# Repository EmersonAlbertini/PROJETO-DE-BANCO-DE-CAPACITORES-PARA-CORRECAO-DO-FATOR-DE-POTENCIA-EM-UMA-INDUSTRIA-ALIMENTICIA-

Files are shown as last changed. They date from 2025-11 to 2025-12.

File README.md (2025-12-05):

# ⚡ Projeto de Banco de Capacitores para Correção do Fator de Potência  

Este repositório apresenta o desenvolvimento de um projeto de banco de capacitores montado em painel elétrico para correção do fator de potência de uma indústria alimentícia.  
O trabalho foi elaborado como Trabalho de Conclusão de Curso (TCC) do curso de Engenharia Elétrica no Centro Universitário Hermínio Ometto (FHO).  
O projeto tem como base dados reais de uma instalação industrial no interior de Santa Catarina e foi desenvolvido em conformidade com as normas ABNT NBR 5410, NBR IEC 61439-1/2, NBR 5419, NR 10, NR 12, entre outras.

---

## 📌 Objetivos Gerais do Projeto  

- Projetar um banco de capacitores automático em painel elétrico para corrigir o fator de potência da instalação;  
- Elevar o fator de potência de 0,87 para 0,95, evitando penalidades tarifárias e melhorando a eficiência energética;  
- Reduzir o carregamento do transformador e proporcionar maior confiabilidade e segurança operacional;  
- Garantir que o projeto esteja em conformidade com as normas técnicas e boas práticas de engenharia.

---

## 🔍 Conteúdo Técnico  

O projeto aborda todas as etapas de dimensionamento, simulação e especificação dos componentes do sistema de compensação reativa, incluindo:

### ⚙️ Cálculo de Compensação Reativa  
- Levantamento da potência reativa da instalação;  
- Cálculo da potência a ser compensada para corrigir o fator de potência;  
- Definição da quantidade e configuração dos estágios.

### 🔄 Simulações e Análises  
- Simulações realizadas via software para validação dos resultados obtidos;  
- Verificação da redução de corrente e melhoria na eficiência do sistema após a compensação reativa;  
- Análise das correntes de curto-circuito trifásico e fase-terra em todos os barramentos da instalação.

### 🔌 Dimensionamento e Seleção de Componentes  
- Seleção dos capacitores trifásicos conforme a tensão nominal da instalação;  
- Utilização de reatores de dessintonia para mitigação de harmônicas e proteção dos capacitores;  
- Definição de contatores específicos para manobra de capacitores, conforme a categoria adequada de utilização;  
- Dimensionamento dos disjuntores de proteção de cada estágio e do disjuntor geral do painel;  
- Especificação do controlador de fator de potência com operação automática e comunicação industrial integrada.

### 🧮 Dimensionamento dos Condutores  
- Definição da seção dos condutores de fase conforme critérios de ampacidade, queda de tensão e curto-circuito;  
- Dimensionamento do condutor de proteção em conformidade com a NBR 5410.

### 🧱 Projeto do Painel Elétrico  
- Projeto desenvolvido em conformidade com as normas NR 10, NR 12, NBR 5410 e NBR IEC 61439-1/2;  
- Sistema de climatização dimensionado com o software RiTherm (Rittal);  
- Sistema de monitoramento térmico da Varixx, com sinalizações locais para supervisão do funcionamento;  
- Diagrama trifilar e layout 3D elaborados no EPLAN Electric P8 + Pro Panel.

---

## 🧰 Ferramentas Utilizadas  

- **EPLAN Electric P8 / Pro Panel** (diagrama e modelagem 3D);  
- **RiTherm** (dimensionamento térmico);  
- **AutoCAD** (diagrama unifilar);  
- **PSP-UFU** (simulações elétricas);  
- **Excel** (lista de cargas e cálculos técnicos).

---

## 🏫 Instituição  

**Centro Universitário Hermínio Ometto – Araras/SP**  
**Curso:** Engenharia Elétrica  
**Período de entrega:** Junho de 2025  

---

## ⚠️ Restrições de Uso  

Este projeto destina-se unicamente para fins didáticos e não deve ser utilizado em aplicações reais sem validação técnica profissional.  
Qualquer uso comercial, seja direto ou indireto, é estritamente proibido sem autorização expressa do autor.  
Para outras finalidades ou solicitações de uso que não se enquadrem nessas condições, por favor, entre em contato com o autor.

---

## ✉️ Contato  

**Autor:** Emerson Falcão Albertini  
**Email:** [emersonalbertini01@gmail.com](mailto:emersonalbertini01@gmail.com)  
**Linkedin:** [www.linkedin.com/in/emerson-falcao-albertini-8aa17a334](https://www.linkedin.com/in/emerson-falcao-albertini-8aa17a334)  

**Orientador:** Prof. Dr. Daniel Augusto Pagi Ferreira  
**Email:** [danielferreira@fho.edu.br](mailto:danielferreira@fho.edu.br)

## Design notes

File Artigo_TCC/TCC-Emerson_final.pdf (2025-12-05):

PROJETO DE BANCO DE CAPACITORES PARA CORREÇÃO DO FATOR DE POTÊNCIA EM UMA INDÚSTRIA ALIMENTÍCIA

Aluno: Emerson Falcão Albertini (FHO) emerson01@alunos.fho.edu.br Orientador: Prof. Dr. Daniel Augusto Pagi Ferreira (FHO) danielferreira@fho.edu.br

Resumo

Este trabalho tem como objetivo desenvolver um projeto de banco de capacitores montado em painel elétrico para corrigir o fator de potência de uma indústria alimentícia. A instalação analisada apresenta elevado consumo de energia reativa indutiva, devido à predominância de inversores de frequência para a partida dos motores, o que compromete o desempenho elétrico e pode gerar penalidades caso não haja a devida compensação. Com base em dados reais de uma instalação industrial, foi realizado o dimensionamento técnico do banco de capacitores, totalizando 225 kVAr distribuídos em 9 estágios, com o objetivo de elevar o fator de potência de 0,87 para 0,95. O projeto contempla os cálculos da compensação, simulações para validação dos resultados e o dimensionamento completo de todos os componentes do sistema, de acordo com as normas técnicas vigentes. Também foram desenvolvidos o diagrama trifilar e layout mecânico do painel. Com isso, o trabalho proposto oferece uma solução técnica eficaz para melhorar a qualidade da energia e evitar despesas com penalidades tarifárias.

Palavras-Chaves: banco de capacitores, fator de potência, qualidade de energia.

### 1. Introdução

Com o crescimento do setor industrial e a crescente demanda por energia elétrica, tem-se intensificado a busca por maior eficiência no uso dos recursos energéticos. A qualidade da energia tornou-se um fator essencial para a competitividade entre empresas, especialmente diante da necessidade de reduzir custos e minimizar impactos ambientais.

Segundo o Ministério de Minas e Energia (MME, 2024), a eficiência energética é considerada uma prioridade nacional, visando à redução dos custos com energia e o aumento da competitividade da economia brasileira. Nesse contexto, práticas como a correção do fator de potência ganham destaque pois, além de melhorar o desempenho dos sistemas elétricos, reduzem perdas técnicas e evitam penalidades tarifárias impostas pelas concessionárias (CREDER, 2016).

A correção do fator de potência é um aspecto crucial na gestão inteligente de energia por medir a eficiência com que a energia elétrica é convertida em trabalho útil, impactando diretamente os custos operacionais e a qualidade do fornecimento de energia.

De acordo com a legislação vigente, estabelecida pela Resolução 1000 de 7/12/2021 (ANEEL, 2021), o fator de potência deve ser mantido dentro dos limites de 0,92 indutivo e 0,92 capacitivo. Caso os limites não sejam respeitados, o excesso de energia reativa, tanto indutiva quanto capacitiva, deve ser medido e faturado. Desse modo, a correção desse fator acaba sendo praticamente obrigatória em industrias de médio a grande porte (FILHO, 2007).

Segundo CREDER (2016), a instalação de bancos de capacitores em paralelo com a rede elétrica é o método mais difundido para corrigir o fator de potência, devido ao seu baixo custo de implementação e manutenção. De modo geral, a principal função de um banco de capacitores é fornecer a quantidade necessária de energia reativa capacitiva, de forma que a relação entre a potência ativa e a potência reativa fique equilibrada, aproximando o fator de potência ao mais próximo possível de ser unitário.

### 1.1. Justificativa

O principal motivo para optar-se por essa solução é melhorar a eficiência energética da instalação. Quando o fator de potência está baixo, uma parcela significativa da energia elétrica é desperdiçada na forma de energia reativa, utilizada apenas para manter os campos eletromagnéticos de equipamentos como motores e transformadores. Com os bancos de capacitores, essa energia passa a ser fornecida localmente, o que reduz a demanda de energia reativa fornecida pela concessionária, diminuindo a circulação de corrente e perdas associadas.

Do ponto de vista técnico, os capacitores fornecem potência reativa capacitiva para compensar a potência reativa indutiva exigida pelas cargas, corrigindo o fator de potência e reduzindo o deslocamento de fase entre corrente e tensão. Como consequência, há uma diminuição das perdas por efeito Joule, do aquecimento de cabos e equipamentos e da sobrecarga em transformadores, contribuindo para um uso eficiente da infraestrutura elétrica.

Outro benefício relevante é a liberação da capacidade do sistema elétrico. A redução da corrente circulante nos condutores e equipamentos, evita sobrecargas e permite melhorar o aproveitamento da infraestrutura existente (SILVA, 2009). Essa condição possibilita futuras ampliações, além de contribuir para o prolongamento da vida útil dos equipamentos.

Além dos ganhos técnicos, a correção do fator de potência proporciona redução de custos operacionais, uma vez que as concessionárias de energia penalizam os consumidores que apresentam fator de potência baixo, cobrando taxas adicionais pela energia reativa excedente. A instalação de bancos de capacitores permite evitar essas penalidades, gerando economia nas faturas de energia elétrica (MARCHI, 2019).

Por fim, essa solução contribui para a sustentabilidade, uma vez que otimiza o uso dos recursos energéticos e evita desperdícios. Assim, a instalação de bancos de capacitores se mostra como medida eficaz e vantajosa para industrias de médio e grande porte que desejam melhorar seu desempenho energético, reduzir custos e atender às exigências regulatórias.

### 2. Considerações gerais e objetivos

Este trabalho consiste na elaboração de um projeto de um banco de capacitores automático, montado em painel, com o objetivo de corrigir o fator de potência de uma instalação industrial.

Especificamente, o estudo busca:

- Diagnosticar o fator de potência atual da instalação;
- Calcular a potência reativa capacitiva necessária para elevar o fator de potência a 0,95;
- Projetar e especificar os componentes do banco de capacitores (capacitores, contatores, disjuntores, reatores de dessintonia e controlador de fator de potência);
- Realizar os cálculos de curto-circuito e dimensionar os condutores conforme as normas técnicas vigentes;
- Validar o projeto por meio de simulações computacionais;
- Elaborar o diagrama trifilar e layout mecânico do painel;
- Avaliar os ganhos obtidos na redução da corrente e do carregamento do transformador.

A proposta foi desenvolvida a partir de dados reais obtidos em uma empresa do setor alimentício localizada no interior de Santa Catarina.

Nota: Todos os materiais técnicos desenvolvidos e utilizados neste trabalho encontram-se disponíveis no repositório oficial do GitHub:

https://github.com/EmersonAlbertini/PROJETO-DE-BANCO-DE-CAPACITORES-PARA-CORRECAO-DO-FATOR-DE-POTENCIA-EM-UMA-INDUSTRIA-ALIMENTICIA-

### 3. Descrição do projeto

A alimentação da indústria tem início em uma subestação abrigada, onde a tensão de 13,8 kV proveniente da concessionária é rebaixada para 380 V por meio de um transformador trifásico de 1000 kVA. Abaixo do transformador encontra-se o Quadro Geral de Baixa Tensão (QGBT), responsável pela distribuição de energia para seis Centros de Controle de Motores (CCM’s). Esses CCM’s alimentam diversas cargas industriais, com predominância de motores acionados por inversores de frequência, condição que intensifica o consumo de energia reativa indutiva e contribui para a redução do fator de potência da instalação.

A Figura 1 mostra o diagrama unifilar do painel elétrico QGBT, responsável por alimentar os seis CCM’s da instalação, ele servirá como ponto de referência para as próximas etapas do desenvolvimento do projeto.

Figura 1 – Diagrama unifilar painel elétrico QGBT

TRAFO-001
1000 kVA
13,8 kV/ 380 V
3Ø / 60Hz

Q01
In=1600A
Ir=1600A
3P

Q02
In=40A
3P
NOTA 9

DPS
CLASSE l+II
220V (F-PE)
Imax = 25 kA
3P+N

Q03
In=16A
3P | 1600/5A

400VA

380/115V P¹ P²

MULTIMEDIDOR
DE GRANDEZAS

ETHERNET/IP
NOTA 10

380V - 3F+N+PE - 1600A - 24kA

Q05
In=800A

3P
NOTA 7

# CCM-002⁽³Ø⁺N⁺PE⁾ ISOL. 0,6/1kV NOTA ⁸ 2x⁽4x240mm²)+1x⁽1x240mm²)

Ir=720A

Q04
In=200A

3P
NOTA 7

# CCM-001⁽³Ø⁺N⁺PE⁾ ISOL. 0,6/1kV NOTA ⁸ 1x⁽4x70mm²)+1x⁽1x50mm²)

Ir=180A

Q06
In=63A

3P
NOTA 7

# CCM-003⁽³Ø⁺N⁺PE⁾ ISOL. 0,6/1kV NOTA ⁸ 1x⁽4x16mm²)+1x⁽1x16mm²)

Ir=54A

Q07
In=250A

3P
NOTA 7

# CCM-004⁽³Ø⁺N⁺PE⁾ ISOL. 0,6/1kV NOTA ⁸ 1x⁽4x95mm²)+1x⁽1x70mm²)

Ir=225A

Q08
In=125A

3P
NOTA 7

# CCM-005⁽³Ø⁺N⁺PE⁾ ISOL. 0,6/1kV NOTA ⁸ 1x⁽4x25mm²)+1x⁽1x25mm²)

Ir=108A

Q09
In=320A

3P
NOTA 7

# CCM-006⁽³Ø⁺N⁺PE⁾ ISOL. 0,6/1kV NOTA ⁸ 1x⁽4x120mm²)+1x⁽1x95mm²)

Ir=260A CABO DE COBRE ³⁵mm² PARA EQUIPOTENCIALIZAÇÃO

PE

QGBT-001 - NOTA 3 E 4

NOTA 5

132.94 kVA
115.75 kW

### 64.97 kVAr

### 34.09 kVA 28.13 kW 18.89 kVAr

468.19 kVA
406.24 kW
232.25 kVAr

### 67.84 kVA 59.87 kW 31.59 kVAr

170.45 kVA
142.29 kW

### 91.34 kVAr

11

VAI PARA | VAI PARA | VAI PARA | VAI PARA | VAI PARA | VAI PARA
PÁG. 02 | PÁG. 02 | PÁG. 03 | PÁG. 04 | PÁG. 04 | PÁG. 05

115.23 kVA
100.54 kW

### 55.55 kVAr

Q14
In=????

3P

# NOTA 7 (3Ø⁺N⁺PE⁾ ISOL. 0,6/1kV NOTA ⁸ _x⁽_x__mm²)+_x⁽_x__mm²)

Ir=????

BANCO DE
CAPACITOR-001

225 kVAr

1

Q10 | Q11 In=320A
| 3P NOTA 7

Ir=294A

Q12
In=250A

3P
NOTA 7

Ir=250A

Q13
In=250A

3P
NOTA 7

Ir=250A

NOTA 1

In=250A

3P
NOTA 7

Ir=250A

RESERVA À DEFINIR ⁽³Ø⁺N⁺PE⁾ ISOL. 0,6/1kV 4x⁽4x185mm²)+4x⁽1x95mm²) | À DEFINIR | À DEFINIR | À DEFINIR
RESERVA | RESERVA | RESERVA

Fonte: Próprio Autor
No presente momento, a instalação apresenta um fator de potência global de 0,87, inferior ao mínimo exigido pela concessionária, o que já resulta em penalidades significativas devido ao excedente de reativos na rede. Com o objetivo de reverter esse cenário, será projetado um banco de capacitores automático, alimentado diretamente pelo QGBT, com a função de compensar a energia reativa consumida pelas cargas indutivas do sistema elétrico.

Além da correção do fator de potência, o banco de capacitores também contribuirá para reduzir o carregamento do transformador, que atualmente opera com 98,87% da sua capacidade nominal, valor muito próximo de seu limite máximo. Essa condição compromete a confiabilidade, pois torna a instalação suscetível a sobrecargas. Com a redução do carregamento, o sistema passa a operar com maior segurança e possibilita futuras ampliações, sem a necessidade imediata de substituição do transformador ou da infraestrutura existente.

Para fundamentar o dimensionamento do banco de capacitores e as análises subsequentes, foram utilizados dois documentos técnicos elaborados para este projeto: a lista de cargas (PBC-LC-25E-0001), que detalha todas as cargas da instalação, e o diagrama unifilar (PBC-UN-25E-0001), que representa graficamente a distribuição elétrica desde a subestação até as cargas terminais de cada CCM.

A Tabela 1, apresentada a seguir, mostra o resumo de cargas da instalação, ela servirá como base para os cálculos e dimensionamentos das etapas subsequentes.

Tabela 1 – Resumo de cargas

Painel

Potência
ativa
demandada
(kW)

Potência
reativa
demandada
(kVAr)

Potência
aparente
demandada
(kVA)

Fator
de
potência

Carregamento
do
transformador
CCM-001 | 100.54 | 55.55 | 115.23 | 0.87 | 11.52%
CCM-002 | 406.24 | 232.25 | 468.19 | 0.87 | 46.82%
CCM-003 | 28.13 | 18.89 | 34.09 | 0.82 | 3.41%
CCM-004 | 115.75 | 64.97 | 132.94 | 0.87 | 13.29%
CCM-005 | 59.87 | 31.59 | 67.84 | 0.88 | 6.78%
CCM-006 | 142.29 | 91.34 | 170.45 | 0.83 | 17.04%
Total | 852.82 | 494.59 | 985.86 | 0.87 | 98.87%

Fonte: Próprio Autor

### 3.1. Cálculo da potência reativa capacitiva a ser compensada

Para que o sistema elétrico da instalação atenda aos requisitos da concessionária de energia, é necessário corrigir o fator de potência. Considerando o QGBT como ponto de referência, atualmente o fator de potência global do sistema está em 0,87.

Embora o valor mínimo exigido seja 0,92, foi adotada a correção para 0,95 indutivo. Essa decisão se justifica pelo fato de que, na prática, manter o fator de potência muito próximo do mínimo permitido não é recomendável pois pequenas variações na carga, como a adição de novos equipamentos ou alterações no perfil de consumo, podem facilmente levar o sistema a ultrapassar o limite de 0,92, o que pode ocasionar sobrecargas caso o sistema não esteja dimensionado para este cenário e/ou penalidades caso a correção não seja feita.

Sendo assim, corrigir o fator de potência para 0,95 é uma boa prática de projeto, pois assegura uma margem de segurança maior que 0,92.

A Figura 2 mostra o triângulo de potências, que representa as relações entre a potência ativa (P), potência reativa (Q), potência aparente (S) e os ângulos correspondentes ao fator de potência (θ₁ e θ₂). Esse triângulo permite compreender geometricamente como essas grandezas se relacionam e, a partir dele, é possível calcular a potência reativa a ser compensada (Qc).

Figura 2 – Triângulo de potências

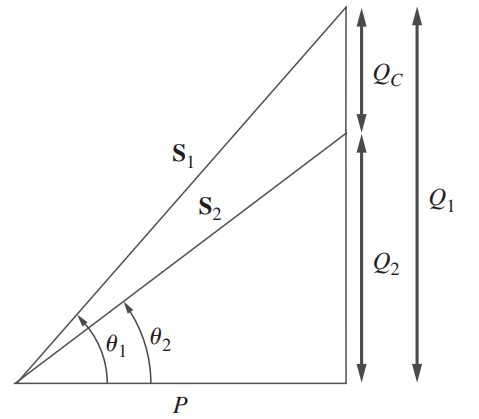
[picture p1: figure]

Fonte: ALEXANDER; SADIKU (2013).
Inicialmente, com base na lista de cargas, verificou-se que a potência ativa total demandada pela instalação é de aproximadamente 852,82 kW, enquanto a potência reativa é cerca de 494,59 kVAr. Com base nesses valores, é possível calcular a potência aparente atual da instalação utilizando a relação trigonométrica descrita na Equação (1):

S₁ = P + Q
= 852,82 + 494,59 ≅ 985,86 kVA | (1)

Para alcançar o fator de potência desejado, é necessário recalcular a potência aparente da instalação, mas agora considerando o fator de potência como 0,95. Deste modo, pela Equação (2):

S₂ =

P

FP

=

852,82
0,95 ≅ 897,71 kVA | (2)

Com a potência aparente obtida, podemos calcular a potência reativa nessa condição por meio da Equação (3):

Q = S
− P = 897,71 − 852,82 ≅ 280,32 kVAr | (3)

A diferença entre a potência reativa atual da instalação e a potência reativa desejada indica o valor da potência que deverá ser compensada pelo banco de capacitores, conforme a Equação (4):

Q = Q − Q = 494,59 − 280,32 = 214,27 kVAr | (4)

Portanto, para corrigir o fator de potência para 0,95, será necessário injetar na rede elétrica aproximadamente 214,27 kVAr de potência reativa capacitiva. Para isso, nos próximos itens, será projetado um banco de capacitores automático composto por 9 estágios de 25 kVAr, totalizando 225 kVAr, o que garantirá a compensação necessária.

Com a inserção do banco de capacitores, a potência reativa demandada da rede elétrica será reduzida, passando de 494,59 kVAr para 269,59 kVAr, resultado da subtração direta da potência reativa fornecida pelo banco (225 kVAr). Nessa nova condição, é possível recalcular a potência aparente demandada da instalação, conforme a Equação (5):

S = P + Q = 852,82 + 269,59 ≅ 894,42 kVA | (5)

Com essa redução, o transformador que anteriormente operava em um nível crítico de 98,87% de carregamento, passará a operar com aproximadamente 89,44%. Isso equivale a uma liberação de aproximadamente 95,3 kVA, ou 9,53% da capacidade nominal. Essa compensação melhorará significativamente a segurança do sistema e possibilitará adição de novas cargas, sem a necessidade imediata de substituir o transformador ou expandir a infraestrutura elétrica existente.

### 3.2. Simulação

A simulação é uma etapa fundamental para validar os resultados obtidos nos cálculos e garantir maior confiabilidade ao projeto. Para este trabalho foi utilizado o software PSP-UFU, que permitiu observar a corrente no secundário do transformador.

A Figura 3 apresenta a condição atual do sistema antes da inserção do banco de capacitores, em que a corrente elétrica no circuito do transformador até o painel do QGBT é de aproximadamente 1572 A.

Figura 3 – Sistema antes a inserção dos capacitores

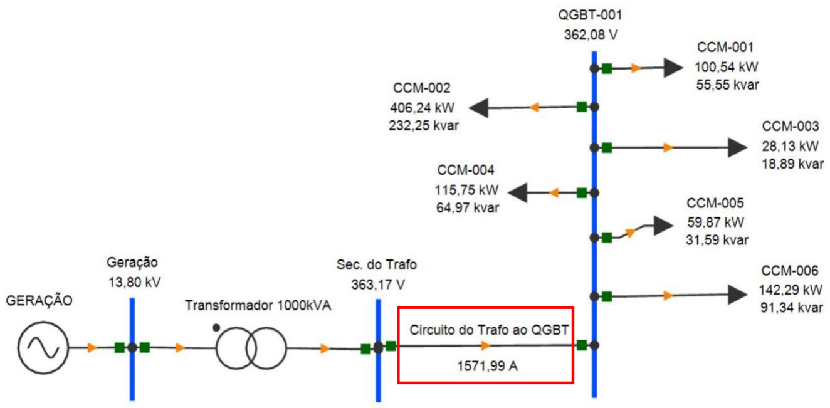
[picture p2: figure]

Fonte: Próprio Autor

A Figura 4 mostra o sistema após a instalação do banco de capacitores, verifica-se que a corrente foi reduzida para cerca de 1414 A.

Figura 4 – Sistema depois a inserção dos capacitores

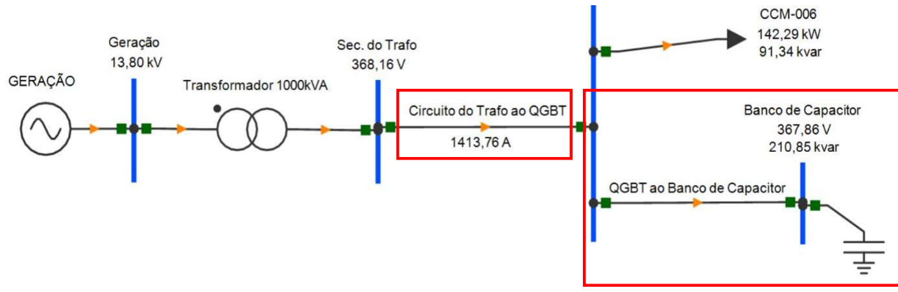
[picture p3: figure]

Fonte: Próprio Autor

Essa redução comprova de forma prática, a efetividade da solução proposta, uma vez que a corrente no secundário do transformador foi reduzida de aproximadamente 1572 A para 1414 A, correspondendo a uma liberação de cerca de 158 A.

### 3.3. Cálculo de curto-circuito

O curto-circuito é uma condição anormal em um sistema elétrico, caracterizado pela conexão acidental de fases entre si ou de fases com o neutro, gerando correntes muito superiores às nominais dos equipamentos.

O cálculo de curto-circuito é essencial para dimensionar corretamente os componentes elétricos, como condutores, disjuntores e barramentos, assegurando que suportem as correntes sem comprometer a segurança e a integridade do sistema.

Além disso, esse cálculo permite definir os ajustes de proteção, garantindo a atuação adequada em casos de falha e, consequentemente, reduzindo os riscos de danos aos equipamentos e à operação.

Para esta instalação, os cálculos de curto-circuito foram realizados em todos os barramentos significativos do sistema, sendo esses: o fornecimento de energia (média tensão), o secundário do transformador (lado de baixa tensão), o painel elétrico QGBT e o painel elétrico do banco de capacitores.

Foram determinados os valores de Ics (corrente de curto-circuito trifásico), Icft (corrente de curto-circuito fase-terra), Ica (corrente assimétrica de curto-circuito) e Icim (impulso da corrente de curto-circuito). A Tabela 2 apresenta os resultados obtidos em cada barramento.

Tabela 2 – Tabela de resultados dos cálculos de curto-circuito

Local | Ics (kA) | Icft (kA) | Fator de
| | | assimetria | Ica (kA) | Icim (kA)

Fornecimento de
energia (lado MT) | 13.91 | 10.44 | 1.62 | 22.53 | 31.87

Transformador
(lado BT) | 24.13 | 23.76 | 1.39 | 33.57 | 47.48

Painel elétrico
QGBT | 23.27 | 23.20 | 1.37 | 31.77 | 44.93

Banco de
capacitores | 20.28 | 9.97 | 1.28 | 26.02 | 36.79
| | Fonte: Próprio Autor

Além dos cálculos, os valores de curto-circuito também podem ser verificados por meio da simulação realizada no tópico anterior. A Figura 5 mostra o valor da corrente de curto-circuito trifásico no barramento do banco de capacitores, confirmando os resultados obtidos nos cálculos.

Figura 5 – Valor de Ics no banco de capacitores

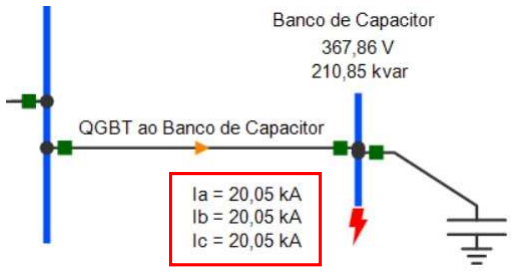
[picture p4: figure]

Fonte: Próprio Autor

### 3.4. Seleção dos capacitores

Para corrigir o fator de potência da instalação, conforme demonstrado nos cálculos anteriores, será necessário inserir capacitores em paralelo com o sistema. Para isso, foram especificadas células trifásicas modelo B32344-E4282-Z040 do fabricante Siemens, vide Figura 6.

O modelo escolhido possui características essenciais para o projeto, como por exemplo, vida útil superior a 100.000 horas, possibilidade de instalação na posição vertical e construção em filme de polipropileno metalizado autorregenerativo, que assegura maior durabilidade do equipamento. Além disso, o modelo possui um sistema interno de proteção contra sobrepressão, que garante a desconexão segura do capacitor em caso de falha.

Figura 6 – Célula capacitiva trifásica

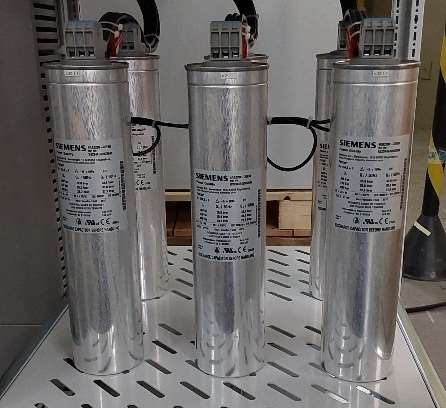
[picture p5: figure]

Fonte: Próprio autor

Cada célula possui potência nominal de 33,7 kVAr quando ligada em 440 V. No entanto, devido a tensão no secundário do transformador ser 380 V, foi necessário recalcular a potência reativa efetiva fornecida por cada unidade, considerando a variação da tensão. Como a potência de um capacitor é proporcional ao quadrado da tensão, aplica-se a relação mostrada na Equação (6):

Q = Q ×

V
V

= 33,7 ×

380
440
≅ 25,1 kVAr | (6)

Assim, cada célula capacitiva fornece cerca de 25 kVAr em 380 V. Para o projeto em questão, foi necessário instalar 9 células capacitivas, totalizando aproximadamente 225 kVAr, sendo superior à necessidade calculada de 214,27 kVAr.

### 3.5. Seleção dos reatores de dessintonia

Em instalações de médio e grande porte, é comum a presença de correntes harmônicas na rede elétrica, principalmente quando há grande quantidade de cargas não lineares, como inversores de frequência, fontes chaveadas, lâmpadas fluorescentes com reatores, entre outros.

De acordo com Wagner e Cruz (2023), as distorções harmônicas de alta frequência podem causar desgaste nos capacitores, pois estes se comportam como elementos de baixa impedância, devido à relação inversa entre impedância e frequência, o que aumenta as perdas ôhmicas, eleva a temperatura interna, reduz a vida útil dos componentes e, em casos extremos, pode causar explosões.

Para evitar esse tipo de problema, foram utilizados reatores de dessintonia (Figura 7) conectados em série com os capacitores. A principal função desse tipo de reator é deslocar a frequência de ressonância do conjunto capacitor-reator para um valor inferior às frequências harmônicas predominantes na rede, evitando assim, a amplificação das harmônicas. Além disso, os reatores atuam como elementos de proteção dos capacitores contra sobrecorrentes e sobretensões.

Figura 7 – Reator de dessintonia

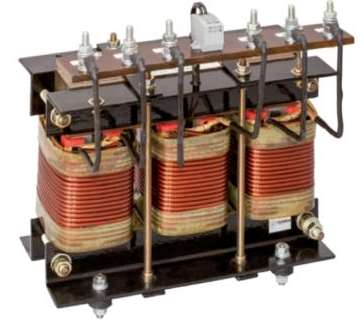
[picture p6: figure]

Fonte: WEG-capacitores-para-correção-do-fator-de-potencia

A escolha adequada dos reatores de dessintonia deve levar em consideração as correntes harmônicas presentes na rede elétrica. No entanto, na maioria dos casos não se tem um estudo detalhado para isso ou não é possível realizar medições no local. Por essa razão, é comum adotar modelos padronizados pelos fabricantes, desenvolvidos com base em critérios técnicos.

O dimensionamento desses reatores leva em consideração, principalmente, a potência do capacitor que será instalado em série com o indutor e o fator de dessintonia adotado, geralmente 7% ou 14%. O valor de 7% é mais utilizado em ambientes industriais, pois desloca a frequência de ressonância para aproximadamente 189 Hz, afastando-a da 5ª harmônica (300 Hz), uma das mais comuns geradas pelos inversores de frequência. Na maioria dos casos, o fator de 7% acaba sendo suficiente para suprir a necessidade da instalação, mas, dependendo das características da carga, pode ser necessário recorrer ao fator de 14%.

No presente projeto, considerando que cada estágio possui 25 kVAr e que a indústria analisada apresenta predominância de partidas de motores acionadas por inversores de frequência, foi adotado o uso de reatores de 25 kVAr, com fator de dessintonia de 7% para todos os estágios.

### 3.6. Seleção dos contatores para manobra dos estágios

Para fazer a comutação dos estágios do banco de capacitores foi necessário utilizar contatores específicos para essa finalidade. Diferentemente dos contatores convencionais, os contatores empregados na manobra de capacitores pertencem à categoria AC-6b, aplicação voltada especificamente para manobras de capacitores, conforme definido pela norma IEC 60947-4-1.

A principal diferença em relação aos modelos padrões, é a presença de resistores de pré-carga, que atuam nos primeiros instantes da energização, limitando a corrente de inrush, que pode atingir valores entre 30 e 50 vezes a corrente nominal do capacitor. Após o amortecimento inicial da corrente, os resistores são automaticamente curto-circuitados, permitindo a condução normal pela via principal dos contatos.

A atuação dos contatos de potência ocorre por um sinal enviado direto do controlador. Ao identificar a necessidade de correção, o controlador aciona a bobina dos contatores, inserindo ou retirando os estágios de forma automática, conforme a demanda da instalação.

Para o projeto, foram especificados contatores do modelo 3RT2628-1BB45 do fabricante Siemens (Figura 8). Este modelo possui bobina de comando em 24 Vcc e é adequado para a comutação de capacitores de 11 a 33 kVAr em redes de 380/400 V.

Figura 8 – Contator para manobra de capacitores

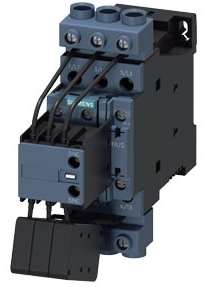
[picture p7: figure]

Fonte: SIEMENS (2025)

### 3.7. Dimensionamento dos disjuntores de proteção dos estágios

Cada estágio do banco de capacitores é composto por um conjunto de 25 kVAr em 380 V, o que resulta em uma corrente nominal dada pela Equação (7):

I =

Q
√3 × V

=

25000
√3 × 380
≈ 38 A | (7)

De acordo com as recomendações do fabricante, o disjuntor de proteção deve ser dimensionado com um fator multiplicador de 1,8 sobre a corrente nominal, a fim de suportar os picos de corrente associados ao chaveamento do capacitor (Fichas Técnicas, pág. 239). Sendo assim, a corrente corrigida dos disjuntores é obtida pela Equação (8):

I = 38 × 1,8 ≈ 68,4 A | (8)

Com base nesse valor, foi especificado o disjuntor 3VM1180-4EE32-0AA0 (Figura 9), do fabricante Siemens, para todos os estágios. Esse modelo possui corrente ajustável de 56 A a 80 A, curva de disparo térmico-magnética, proteção do tipo LI e capacidade de interrupção de curto-circuito de 36 kA.

Figura 9 – Disjuntor de proteção 3VM11

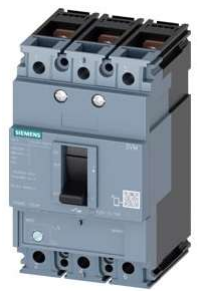
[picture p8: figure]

Fonte: SIEMENS (2025)

A escolha dos disjuntores também está em conformidade com a norma IEC 60947-2, que estabelece que a capacidade de interrupção (Icc) do disjuntor deve ser superior à corrente de curto-circuito presumida no ponto de instalação, garantindo a proteção eficaz do sistema e a integridade dos equipamentos em caso de falha.

### 3.8. Cálculo do disjuntor geral

Para dimensionar o disjuntor geral do painel foi necessário somar a corrente corrigida dos nove estágios do banco. Aplicando-se o mesmo critério de dimensionamento descrito anteriormente, a corrente total corrigida é obtida pela Equação (9):

I = 68,4 × 9 ≈ 616 A | (9)

Dessa forma, foi especificado o disjuntor 3VA1580-5EF32-0AA0. Esse modelo possui corrente nominal ajustável entre 560 A e 800 A, curva de disparo térmico-magnética, proteção do tipo LI e capacidade de interrupção de curto-circuito de 55 kA. Assim como os disjuntores dos estágios, o disjuntor geral também segue os critérios estabelecidos pela IEC 60947-2.

Embora a corrente total corrigida seja de aproximadamente 616 A, foi adotado um disjuntor geral com capacidade de 800 A, pois o painel possui três estágios reservas e, caso venham a ser utilizados, já estará preparado para suportá-los.

### 3.9. Comando geral do painel

O comando será realizado por um sistema de operação manual ou automático, composto de chaves seletoras instaladas na porta frontal do painel. Cada estágio possui sua chave que permite ao operador definir o modo de funcionamento, conforme descrito a seguir:

- Modo Manual: o estágio permanece fixamente ligado, independentemente da lógica do controlador (essa função é utilizada em situações de emergência ou em testes operacionais).
- Modo Automático: o estágio é comandado automaticamente pelo controlador de fator de potência, que decide seu acionamento conforme a demanda de potência reativa da instalação.

Além disso, o painel conta com sinaleiros luminosos na porta para indicar o status de cada estágio (ligado/desligado), com o objetivo de facilitar a supervisão local. Também foram incluídas sinalizações gerais, tais como: disjuntor geral ligado, desligado, em falha e o status do DPS (Dispositivo de Proteção contra Surtos).

### 3.10. Controlador de fator de potência

O controlador de fator de potência é o cérebro de todo o sistema, sendo responsável por comandar de forma automática a operação do banco. Para este projeto, foi especificado o modelo B44066-R6012-S221, do fabricante Siemens.

O controlador realiza medições contínuas, utilizando como referência os parâmetros de tensão e corrente vindos do painel QGBT, ponto onde será corrigido o fator de potência. Com base nessas medições, o equipamento insere ou retira os estágios de forma sequencial, elevando ou reduzindo a potência reativa, conforme a demanda da instalação.

O modelo escolhido contém doze saídas para controle dos estágios e possui recursos de proteção, como detecção de sobrecompensação e diagnóstico de falha em cada estágio. Além disso, ele permite comunicação via interfaces Modbus-TCP e RS-485, possibilitando a integração com um CLP externo ou a conexão a uma rede Ethernet.

A Figura 10 mostra o esquema de ligação do controlador de fator de potência, retirado do catálogo técnico do fabricante.

Figura 10 – Esquema de ligação controlador de fator de potência

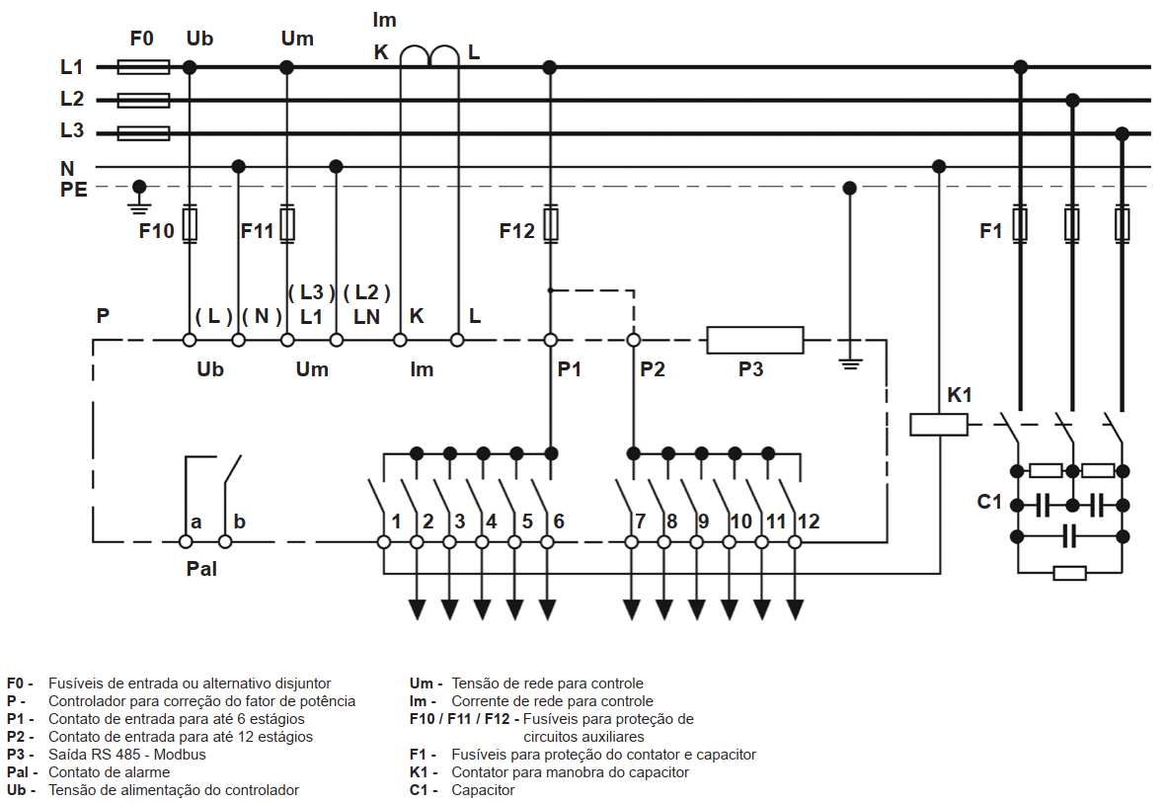
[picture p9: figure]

Fonte: SIEMENS (2025)

### 3.11. Dimensionamento dos condutores

O dimensionamento dos condutores que alimentam o painel deve atender aos parâmetros estabelecidos pela NBR 5410, considerando critérios como ampacidade, queda de tensão admissível, capacidade de interrupção de curto-circuito e dimensionamento dos condutores neutro e terra. Neste projeto, a seção nominal dos condutores de fase foi determinada pelo critério da ampacidade, por ser o mais crítico entre os mencionados, embora todos os demais critérios também tenham sido verificados.

Nessas condições, adotou-se o método de instalação do tipo C (cabos multipolares em bandeja não perfurada), considerando temperatura ambiente de 30 °C (fator de temperatura igual a 1). Além disso, o fator de agrupamento foi definido como 1, considerando que o circuito terá infraestrutura dedicada.

Apesar da corrente total do banco ser de 616 A (calculado no item 3.7), adotou-se o dimensionamento com base na corrente máxima do disjuntor geral (800 A), pois viabiliza expansões de carga. Aplicando a fórmula da corrente corrigida, tem-se a Equação (10):

I =

I
FCA × FCT =

800
1 × 1
= 800 A | (10)

Assim, os condutores de fase devem suportar 800 A. Com base na Tabela 37 da NBR 5410, foi adotado utilização de dois cabos de 185 mm² por fase, com isolação em XLPE.

Conforme a Tabela 48 da NBR 5410, a seção do condutor neutro pode ser metade da seção dos condutores de fase. Entretanto, como não se tem um estudo de distorções harmônicas, o condutor neutro foi dimensionado com a mesma seção dos condutores de fase, a fim de garantir uma margem de segurança caso a instalação apresente correntes harmônicas.

O condutor de proteção (terra) foi dimensionado conforme a Tabela 58 da NBR 5410, que estabelece que, para condutores de fase com seção superior a 35 mm², a seção do condutor de proteção pode ser metade da seção da fase. Com isso, foi adotado um único cabo de 185 mm².

Os condutores internos ao painel também foram dimensionados conforme a norma, respeitando a capacidade de condução exigida para cada circuito. Entretanto, não foram aplicados fatores de correção por agrupamento ou temperatura pois os trajetos são curtos e não geram acúmulo significativo de calor, além disso o painel já conta com sistema de ventilação forçada, conforme descrito no tópico seguinte.

### 3.12. Considerações técnicas do projeto do painel

O projeto do painel foi desenvolvido em conformidade com as normas técnicas aplicáveis, dentre elas a NBR 5410, já mencionada anteriormente, e a NBR IEC 61439-1/2, que estabelece os requisitos de montagem, desempenho e ensaios para conjuntos de manobra e controle de baixa tensão. Também foram atendidas as exigências da NR 10 e NR 12.

O painel foi construído em Forma 1, conforme definido pela NBR IEC 61439, que consiste na montagem onde não há separação física entre os dispositivos funcionais (como contatores, disjuntores e barramentos), sendo todos instalados em um mesmo compartimento. Essa forma de construção tem como objetivo reduzir custos de fabricação e manter a simplicidade construtiva.

Seguindo os requisitos da NR 12, os dispositivos de comando instalados na porta do painel (chaves seletoras e sinaleiros), são alimentados em extra baixa tensão, o que garante maior segurança ao operador durante a operação local do sistema.

Além disso, o painel conta com um sistema de monitoramento de temperatura do fabricante Varixx, composto por um relé de temperatura e sensores instalados nos pontos com maior probabilidade de aquecimento, sendo estes: a saída dos polos do disjuntor geral, as conexões entre o barramento flexível e o barramento principal, e a saída de cada capacitor. O sistema permite acompanhar a temperatura em tempo real dos pontos críticos, e pode ser integrado a um sistema supervisório.

Conforme a NBR 5419, é obrigatório o uso do dispositivo de proteção contra surtos (DPS) em painéis elétricos, salvo em condições específicas previstas na norma. No presente projeto, optou-se pelo uso somente de DPS classe 2, uma vez que o painel QGBT já conta com a proteção de um DPS classe 1, que atua como primeira barreira contra surtos diretos.

A climatização do painel é essencial para garantir a operação segura e confiável dos componentes. Para este projeto, adotou-se um sistema de ventilação forçada, composto por ventiladores e filtros, dimensionado com base na ferramenta RiTherm, da RITTAL (fabricante da chaparia utilizada no painel). A ferramenta permite determinar o tipo de climatização adequado, assegurando que a temperatura interna do painel permaneça dentro dos limites recomendados para operação segura.

O diagrama trifilar do painel elétrico foi desenvolvido no software EPLAN Electric P8, o que permitiu detalhar todas as ligações internas do sistema. A Figura 11 apresenta uma página referente a um dos estágios do banco de capacitores, retirada do diagrama trifilar.

1° ESTÁGIO ¹⁵⁰¹.1 | 1501.4 | 1501.7 R¹ | S1 | T1

### PE PE

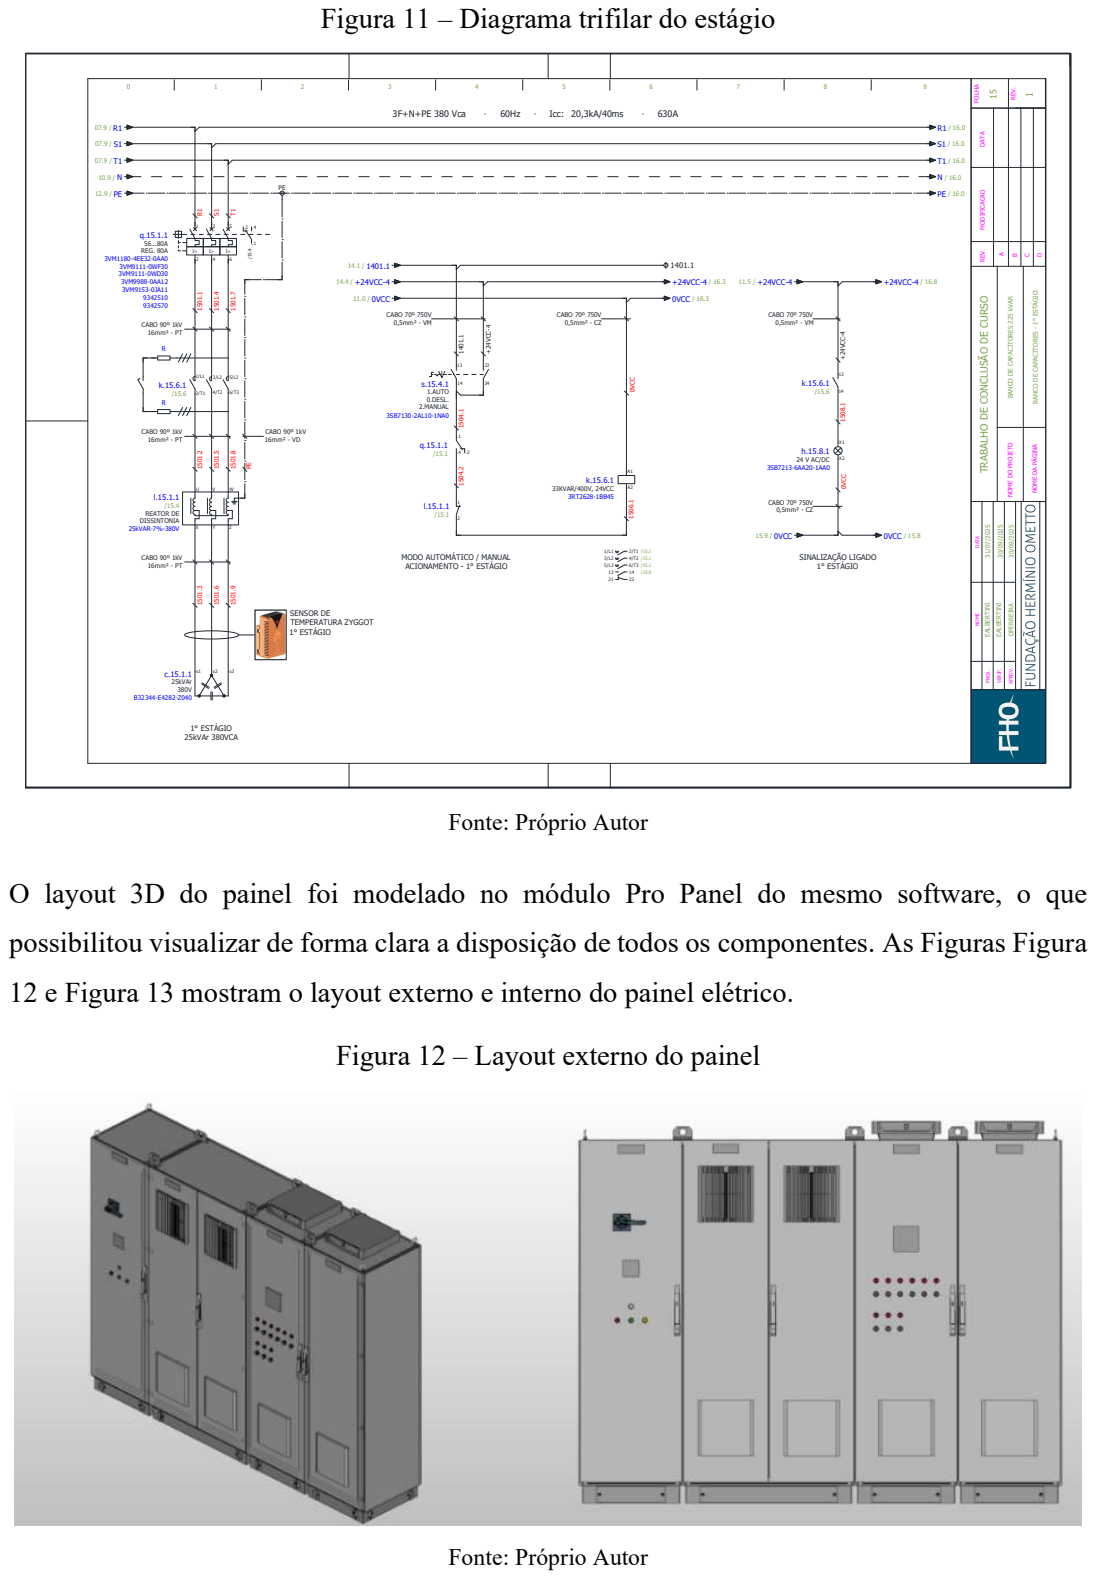
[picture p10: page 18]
PROJ.; VERIF. NOME DATA MODIFICACAO REV.; 1 EALBERTINI; CABO 90º 1kV 16mm² - PT; 1° ESTÁGIO 25kVAr 380VCA; CABO 70º 750V 0,5mm² - CZ; 3F+N+PE 380 Vca; Icc:; CABO 70º 750V 0,5mm² - VM; CABO 90º 1kV 16mm² - VD; SINALIZAÇÃO LIGADO 1° ESTÁGIO; ACIONAMENTO - 1° ESTÁGIO; +²⁴VCC⁻4 1401.1; +²⁴VCC⁻4; SENSOR DE TEMPERATURA ZYGGOT; c.15.1.1 25kVAr; k.15.6.1 33KVAR/400V, 24VCC; q.15.1.1 56...80A REG. 80A; s.15.4.1 1.AUTO; 0.DESL. 2.MANUAL 3SB7130-2AL10-1NA0; l.15.1.1 /15.4 REATOR DE DISSINTONIA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

Figura 11 – Diagrama trifilar do estágio

B DATA CD REV. NOME DO PROJETO NOME DA PÁGINA APROV. FOLHA 30/09/2025 EALBERTINI 31/07/2025 BANCO DE CAPACITORES 225 kVAR BANCO DE CAPACITORES - 1° ESTÁGIO 15 30/09/2025 DFERREIRA TRABALHO DE CONCLUSÃO DE CURSO

MODO AUTOMÁTICO / MANUAL

Fonte: Próprio Autor

O layout 3D do painel foi modelado no módulo Pro Panel do mesmo software, o que
possibilitou visualizar de forma clara a disposição de todos os componentes. As Figuras Figura
12 e Figura 13 mostram o layout externo e interno do painel elétrico.

Figura 12 – Layout externo do painel

Figura 13 – Layout interno do painel

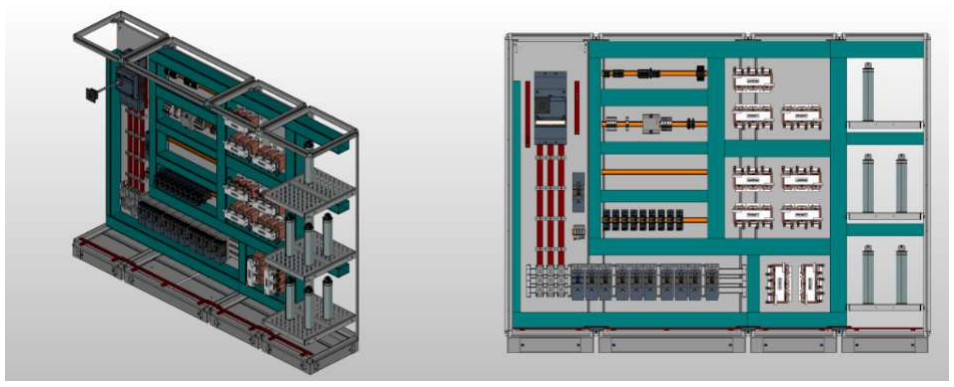
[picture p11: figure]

Fonte: Próprio Autor

### 4. Conclusão

A correção do fator de potência por meio da instalação de um banco de capacitores mostrou-se uma solução técnica eficaz para a realidade da indústria analisada. O projeto desenvolvido possibilitou elevar o fator de potência da instalação de 0,87 para 0,95, atendendo às exigências normativas e evitando penalidades tarifárias decorrentes do excesso de energia reativa na rede elétrica.

A compensação capacitiva proporcionou uma redução significativa no carregamento do transformador, que passou de 98,87% para 89,44%, liberando aproximadamente 95,3 kVA. Essa liberação de carga permitirá que o transformador opere em uma faixa mais segura e viabilizará futuras ampliações sem a necessidade de substituição imediata dos componentes.

Dessa forma, o trabalho cumpriu seu objetivo ao apresentar uma solução técnica para a compensação de energia reativa, alinhada às normas vigentes para projetos de painéis. Na prática, essa medida contribui para a eficiência energética, redução dos custos operacionais e melhor aproveitamento do sistema elétrico da indústria analisada.

REFERÊNCIAS

ABNT – Associação Brasileira De Normas Técnicas. NBR 5410: Instalações Elétricas de Baixa Tensão. Rio de Janeiro: ABNT, 2004. 209 p.

ABNT – Associação Brasileira de Normas Técnicas. NBR 5419: Proteção contra descargas atmosféricas. Rio de Janeiro: ABNT, 2015.

ABNT – Associação Brasileira De Normas Técnicas. NBR IEC 61439-1: Conjuntos de manobra e controle de baixa tensão - Parte 1: Regras gerais. Rio de Janeiro: ABNT, 2016. 147 p.

ABNT – Associação Brasileira De Normas Técnicas. NBR IEC 61439-2: Conjuntos de manobra e controle de baixa tensão - Parte 2: Requisitos para conjuntos de manobra e controle de baixa tensão. Rio de Janeiro: ABNT, 2016. 22 p.

ABNT. Associação Brasileira de Normas Técnicas. ABNT NBR IEC 60947-2: Aparelhos de manobra e comando de baixa tensão – Parte 2: Disjuntores. Rio de Janeiro, 2011.

ALEXANDER, Charles K.; SADIKU, Matthew N. O. Fundamentos de circuitos elétricos. 5. ed. Porto Alegre: AMGH Editora, Bookman, 2013.

ANEEL – Agência Nacional de Energia Elétrica. Resolução Normativa ANEEL nº 1000. Brasília, ANEEL, 2021. Disponível em: https://www.in.gov.br/en/web/dou/-/resolucao-normativa-aneel-n-1.000-de-7-de-dezembro-de-2021-368359651. Acesso em: 20 jul. 2025.

CREDER, Hélio. Instalações elétricas. 16. ed. Rio de Janeiro: LTC, 2016.

INTERNATIONAL ELECTROTECHNICAL COMMISSION. IEC 60947-4-1: Low-voltage switchgear and controlgear – Part 4-1: Contactors and motor-starters – Electromechanical contactors and motor-starters. Geneva: IEC, 2020. 276 p.

MAMEDE FILHO, João. Fator de potência. In: MAMEDE FILHO, João. Instalações elétricas industriais. 7. ed. Rio de Janeiro: Livros Técnicos e Científicos, 2007. cap. 4, p. 179.

MARCH, D. Projeto e estudo de viabilidade técnica e financeira da correção do fator de potência em indústria têxtil utilizando bancos de capacitores. 2019. p. 61-63. Trabalho de Conclusão de Curso (Graduação em Engrenharia Elétrica) – Universidade Federal de Santa Catarina, Florianópolis, 2019. Disponível em: https://repositorio.ufsc.br/handle/123456789/197847. Acesso em: 20 jul. 2025.

MINISTÉRIO DE MINAS E ENERGIA (BR). Eficiência energética é parte fundamental do futuro do setor elétrico. Brasília, 28 nov. 2024. Disponível em: https://www.gov.br/mme/pt-br/assuntos/noticias/eficiencia-energetica-e-parte-fundamental-do-futuro-do-setor-eletrico. Acesso em: 14 jul. 2025.

Ministério do Trabalho e Emprego. NR 10: Segurança em Instalações e Serviços em Eletricidade. Brasília: Ministério do Trabalho e Emprego, 2019.

Ministério do Trabalho e Emprego. NR 12: Segurança no Trabalho em Máquinas e Equipamentos. Brasília: Ministério do Trabalho e Emprego, 2019.

SIEMENS. Especificações Técnicas - Março 25. Versão: JAN/25. Disponível em: https://assets.new.siemens.com/siemens/assets/api/uuid:80670812-d74b-451f-a233-2ad58f1c4c1c/Fichas-tecnicas-Marco-atualizado.pdf. Acesso em: 22 jul. 2025.

SILVA, M. C. I. Correção do fator de potência de cargas industriais com dinâmica rápida. 2009. p. 37. Dissertação (Mestrado em Engrenharia Elétrica) – Escola de Engenharia, Universidade Federal de Minas Gerais, Belo Horizonte, 2009. Disponível em: http://hdl.handle.net/1843/BUOS-8D7HDF. Acesso em: 20 jul. 2025.

WAGNER, Gustavo; CRUZ, Vinícius. Estudo de caso de correção de fator de potência em uma planta industrial. 2023. p. 50-57. Trabalho de conclusão de curso (Graduação em Engenharia Elétrica) – Universidade Tecnológica Federal do Paraná, Curitiba, 2023. Disponível em: http://repositorio.utfpr.edu.br/jspui/handle/1/35992. Acesso em: 04 out. 2025.

WEG. Reatores de Dessintonia DRW. Disponível em: https://www.weg.net/catalog/weg/BR/pt/Automação-e-Controle-Industrial/Controls/Capacitores-e-Correção-do-Fator-de-Potência/Reatores-de-Dessintonia/Reatores-de-Dessintonia-DRW/p/MKT_WDC_BRAZIL_PRODUCT_DETUNING_REACTORS_DRW. Acesso em: 22 jul. 2025.

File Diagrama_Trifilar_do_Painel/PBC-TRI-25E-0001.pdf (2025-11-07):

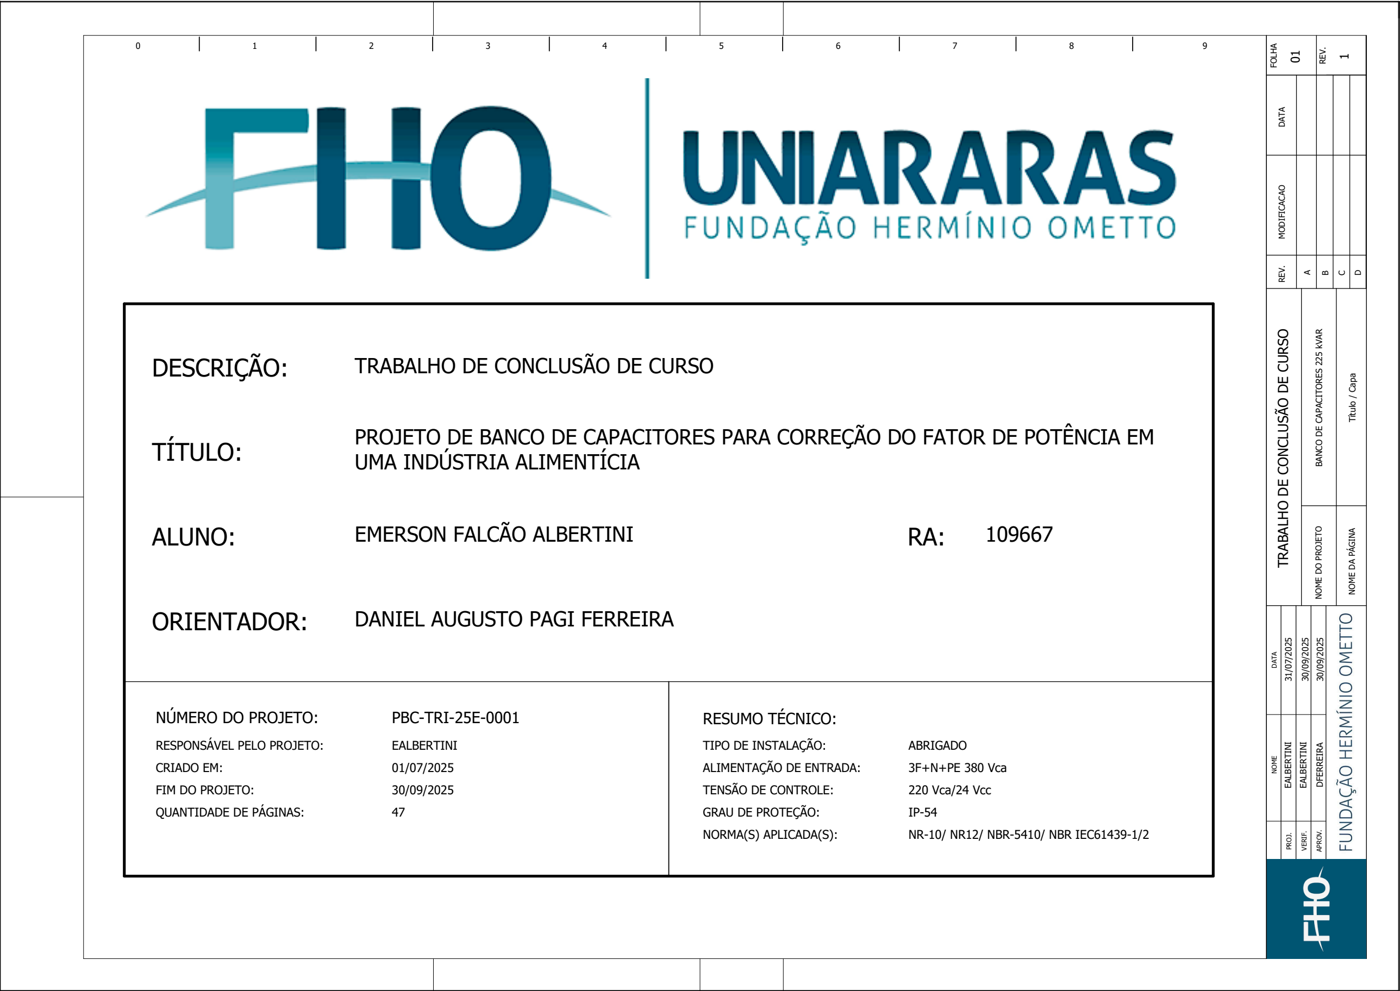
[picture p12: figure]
EALBERTINI 31/07/2025 PROJ.; VERIF.; NOME DATA; MODIFICACAO REV.; DATA; REV. NOME DO PROJETO; NOME DA PÁGINA; BANCO DE CAPACITORES 225 kVAR; Título / Capa; APROV.; FOLHA; 30/09/2025 DFERREIRA; TRABALHO DE CONCLUSÃO DE CURSO; EALBERTINI; ALIMENTAÇÃO DE ENTRADA:; FIM DO PROJETO:; TIPO DE INSTALAÇÃO:; NÚMERO DO PROJETO:; QUANTIDADE DE PÁGINAS:; ABRIGADO; 220 Vca/24 Vcc; PBC-TRI-25E-0001; 3F+N+PE 380 Vca; GRAU DE PROTEÇÃO:; TENSÃO DE CONTROLE:; RESPONSÁVEL PELO PROJETO:; CRIADO EM:; RESUMO TÉCNICO:; TÍTULO:; DESCRIÇÃO:; ALUNO:; UMA INDÚSTRIA ALIMENTÍCIA; EMERSON FALCÃO ALBERTINI; DANIEL AUGUSTO PAGI FERREIRA; ORIENTADOR:

NORMA(S) APLICADA(S): | NR-10/ NR12/ NBR-5410/ NBR IEC61439-1/2

# PROJETO DE BANCO DE CAPACITORES PARA CORREÇÃO DO FATOR DE POTÊNCIA EM

30/09/2025

EALBERTINI 31/07/2025 PROJ.

VERIF.

NOME DATA

MODIFICACAO REV.

A
B

DATA

C

D

## REV. NOME DO PROJETO

### NOME DA PÁGINA

BANCO DE CAPACITORES 225 kVAR

### ÍNDICE

APROV.

30/09/2025 DFERREIRA

# TRABALHO DE CONCLUSÃO DE CURSO

EALBERTINI

# Índice INDICE Ver 1

Página | Descrição da página | Data | Editor
&Diagrama Elétrico/01 | Título / Capa | 13/08/2025 | Douglas Santos
&Diagrama Elétrico/02 | ÍNDICE | 30/09/2025 | Douglas Santos
&Diagrama Elétrico/02.a | ÍNDICE | 30/09/2025 | Douglas Santos
&Diagrama Elétrico/03 | LEGENDA | 15/07/2025 | Douglas Santos
&Diagrama Elétrico/03.a | SIMBOLOGIA | 15/07/2025 | Douglas Santos
&Diagrama Elétrico/03.b | SIMBOLOGIA | 15/07/2025 | Douglas Santos
&Diagrama Elétrico/04 | FOLHA DE DADOS | 22/07/2025 | Douglas Santos
&Diagrama Elétrico/05 | ESQUEMA DE ENTRADA | 05/09/2025 | Douglas Santos
&Diagrama Elétrico/06 | DIAGRAMA DO DPS | 05/09/2025 | Douglas Santos
&Diagrama Elétrico/07 | DISTRIBUIÇÃO DE COMANDO BACKUP | 30/09/2025 | Douglas Santos
&Diagrama Elétrico/08 | ILUMINAÇÃO PAINEL | 05/09/2025 | Douglas Santos
&Diagrama Elétrico/09 | VENTILAÇÃO PAINEL | 05/09/2025 | Douglas Santos
&Diagrama Elétrico/10 | CIRCUITOS AUXILIARES | 20/08/2025 | Douglas Santos
&Diagrama Elétrico/11 | FONTE 24VCC | 05/09/2025 | Douglas Santos
&Diagrama Elétrico/12 | RELÉ DE MONITORAMENTO E PROTEÇÃO DE TEMPERATURA | 11/08/2025 | Douglas Santos
&Diagrama Elétrico/13 | SENSORES DE TEMPERATURA | 30/07/2025 | Douglas Santos
&Diagrama Elétrico/14 | CONTROLADOR FATOR DE POTÊNCIA | 05/09/2025 | Douglas Santos
&Diagrama Elétrico/15 | BANCO DE CAPACITORES - 1° ESTÁGIO | 30/09/2025 | Douglas Santos
&Diagrama Elétrico/16 | BANCO DE CAPACITORES - 2° ESTÁGIO | 30/09/2025 | Douglas Santos
&Diagrama Elétrico/17 | BANCO DE CAPACITORES - 3° ESTÁGIO | 30/09/2025 | Douglas Santos
&Diagrama Elétrico/18 | BANCO DE CAPACITORES - 4° ESTÁGIO | 30/09/2025 | Douglas Santos
&Diagrama Elétrico/19 | BANCO DE CAPACITORES - 5° ESTÁGIO | 30/09/2025 | Douglas Santos
&Diagrama Elétrico/20 | BANCO DE CAPACITORES - 6° ESTÁGIO | 30/09/2025 | Douglas Santos
&Diagrama Elétrico/21 | BANCO DE CAPACITORES - 7° ESTÁGIO | 30/09/2025 | Douglas Santos
&Diagrama Elétrico/22 | BANCO DE CAPACITORES - 8° ESTÁGIO | 30/09/2025 | Douglas Santos
&Diagrama Elétrico/23 | BANCO DE CAPACITORES - 9° ESTÁGIO | 30/09/2025 | Douglas Santos
&Diagrama Elétrico/24 | BANCO DE CAPACITORES - 10° ESTÁGIO RESERVA | 25/07/2025 | Douglas Santos
&Diagrama Elétrico/25 | BANCO DE CAPACITORES - 11° ESTÁGIO RESERVA | 25/07/2025 | Douglas Santos
&Diagrama Elétrico/26 | BANCO DE CAPACITORES - 12° ESTÁGIO RESERVA | 25/07/2025 | Douglas Santos
&Diagrama Elétrico/27 | LAYOUT EXTERNO | 30/09/2025 | Douglas Santos
&Diagrama Elétrico/28 | LAYOUT INTERNO | 30/09/2025 | Douglas Santos
&Diagrama Elétrico/29 | LAYOUT 3D | 30/09/2025 | Douglas Santos
&Diagrama Elétrico/30 | LAYOUT 3D | 30/09/2025 | Douglas Santos

30/09/2025

EALBERTINI 31/07/2025 PROJ.

VERIF.

NOME DATA

MODIFICACAO REV.

A
B

DATA

C

D

## REV. NOME DO PROJETO

### NOME DA PÁGINA

BANCO DE CAPACITORES 225 kVAR

### ÍNDICE

APROV.

02.a

30/09/2025 DFERREIRA

# TRABALHO DE CONCLUSÃO DE CURSO

EALBERTINI

# Índice INDICE Ver 1

Página | Descrição da página | Data | Editor
&Diagrama Elétrico/31 | LAYOUT 3D | 30/09/2025 | Douglas Santos
&Diagrama Elétrico/32 | LAYOUT 3D | 30/09/2025 | Douglas Santos
&Diagrama Elétrico/33 | Lista de peças : ZCB/4/2U/400 - RIT.8660002 | 02/09/2025 | Douglas Santos
&Diagrama Elétrico/33.a | Lista de peças : RIT.8660033 - 30x10mm | 05/09/2025 | Douglas Santos
&Diagrama Elétrico/33.b | Lista de peças : B32344-E4282-Z040 - 3RT2628-1BB45 | 05/09/2025 | Douglas Santos
&Diagrama Elétrico/33.c | Lista de peças : 3RT2628-1BB45 - 3VA1580-5EF32-0AA0 | 05/09/2025 | Douglas Santos
&Diagrama Elétrico/33.d | Lista de peças : 3VA9687-0FK21 - 3VM9111-0WF30 | 30/09/2025 | Douglas Santos
&Diagrama Elétrico/33.e | Lista de peças : 3VM9111-0WD30 - 3VM9111-0WF30 | 30/09/2025 | Douglas Santos
&Diagrama Elétrico/33.f | Lista de peças : 3VM9111-0WD30 - 3VM9111-0WF30 | 30/09/2025 | Douglas Santos
&Diagrama Elétrico/33.g | Lista de peças : 3VM9111-0WD30 - ZFI | 05/09/2025 | Douglas Santos
&Diagrama Elétrico/33.h | Lista de peças : ZSB/M/60/120 - 51300214 | 05/09/2025 | Douglas Santos
&Diagrama Elétrico/34 | Lista de peças totalizadas : | 02/09/2025 | Douglas Santos
&Diagrama Elétrico/34.a | Lista de peças totalizadas : | 05/09/2025 | Douglas Santos
&Diagrama Elétrico/34.b | Lista de peças totalizadas : | 30/09/2025 | Douglas Santos

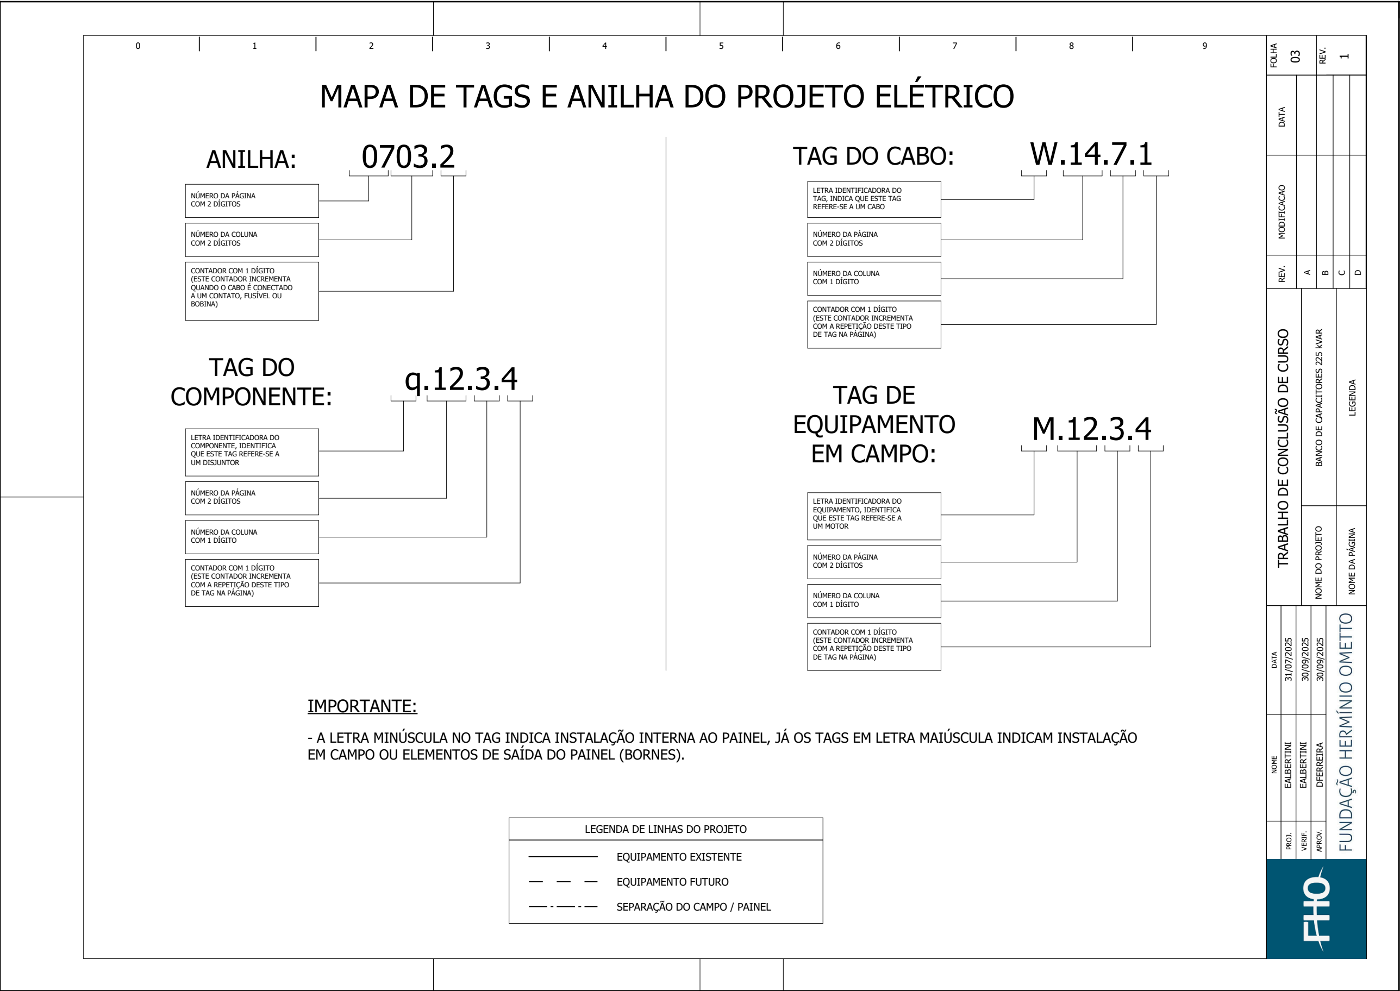
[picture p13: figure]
EALBERTINI 31/07/2025 PROJ.; VERIF.; NOME DATA; MODIFICACAO REV.; DATA; REV. NOME DO PROJETO; NOME DA PÁGINA; BANCO DE CAPACITORES 225 kVAR; LEGENDA; APROV.; 30/09/2025 DFERREIRA; TRABALHO DE CONCLUSÃO DE CURSO; EALBERTINI; EQUIPAMENTO EXISTENTE; EQUIPAMENTO FUTURO; SEPARAÇÃO DO CAMPO / PAINEL; ANILHA:; NÚMERO DA PÁGINA COM 2 DÍGITOS; NÚMERO DA COLUNA COM 2 DÍGITOS; CONTADOR COM 1 DÍGITO (ESTE CONTADOR INCREMENTA QUANDO O CABO É CONECTADO A UM CONTATO, FUSÍVEL OU BOBINA); q.12.3.4 TAG DO COMPONENTE:; NÚMERO DA COLUNA COM 1 DÍGITO; CONTADOR COM 1 DÍGITO (ESTE CONTADOR INCREMENTA COM A REPETIÇÃO DESTE TIPO DE TAG NA PÁGINA); LETRA IDENTIFICADORA DO COMPONENTE, IDENTIFICA QUE ESTE TAG REFERE-SE A UM DISJUNTOR; TAG DO CABO:; LETRA IDENTIFICADORA DO TAG, INDICA QUE ESTE TAG REFERE-SE A UM CABO; TAG DE EQUIPAMENTO EM CAMPO:; LETRA IDENTIFICADORA DO EQUIPAMENTO, IDENTIFICA QUE ESTE TAG REFERE-SE A UM MOTOR; IMPORTANTE:; LEGENDA DE LINHAS DO PROJETO

# MAPA DE TAGS E ANILHA DO PROJETO ELÉTRICO

- A LETRA MINÚSCULA NO TAG INDICA INSTALAÇÃO INTERNA AO PAINEL, JÁ OS TAGS EM LETRA MAIÚSCULA INDICAM INSTALAÇÃO EM CAMPO OU ELEMENTOS DE SAÍDA DO PAINEL (BORNES).

# SIMBOLOGIA

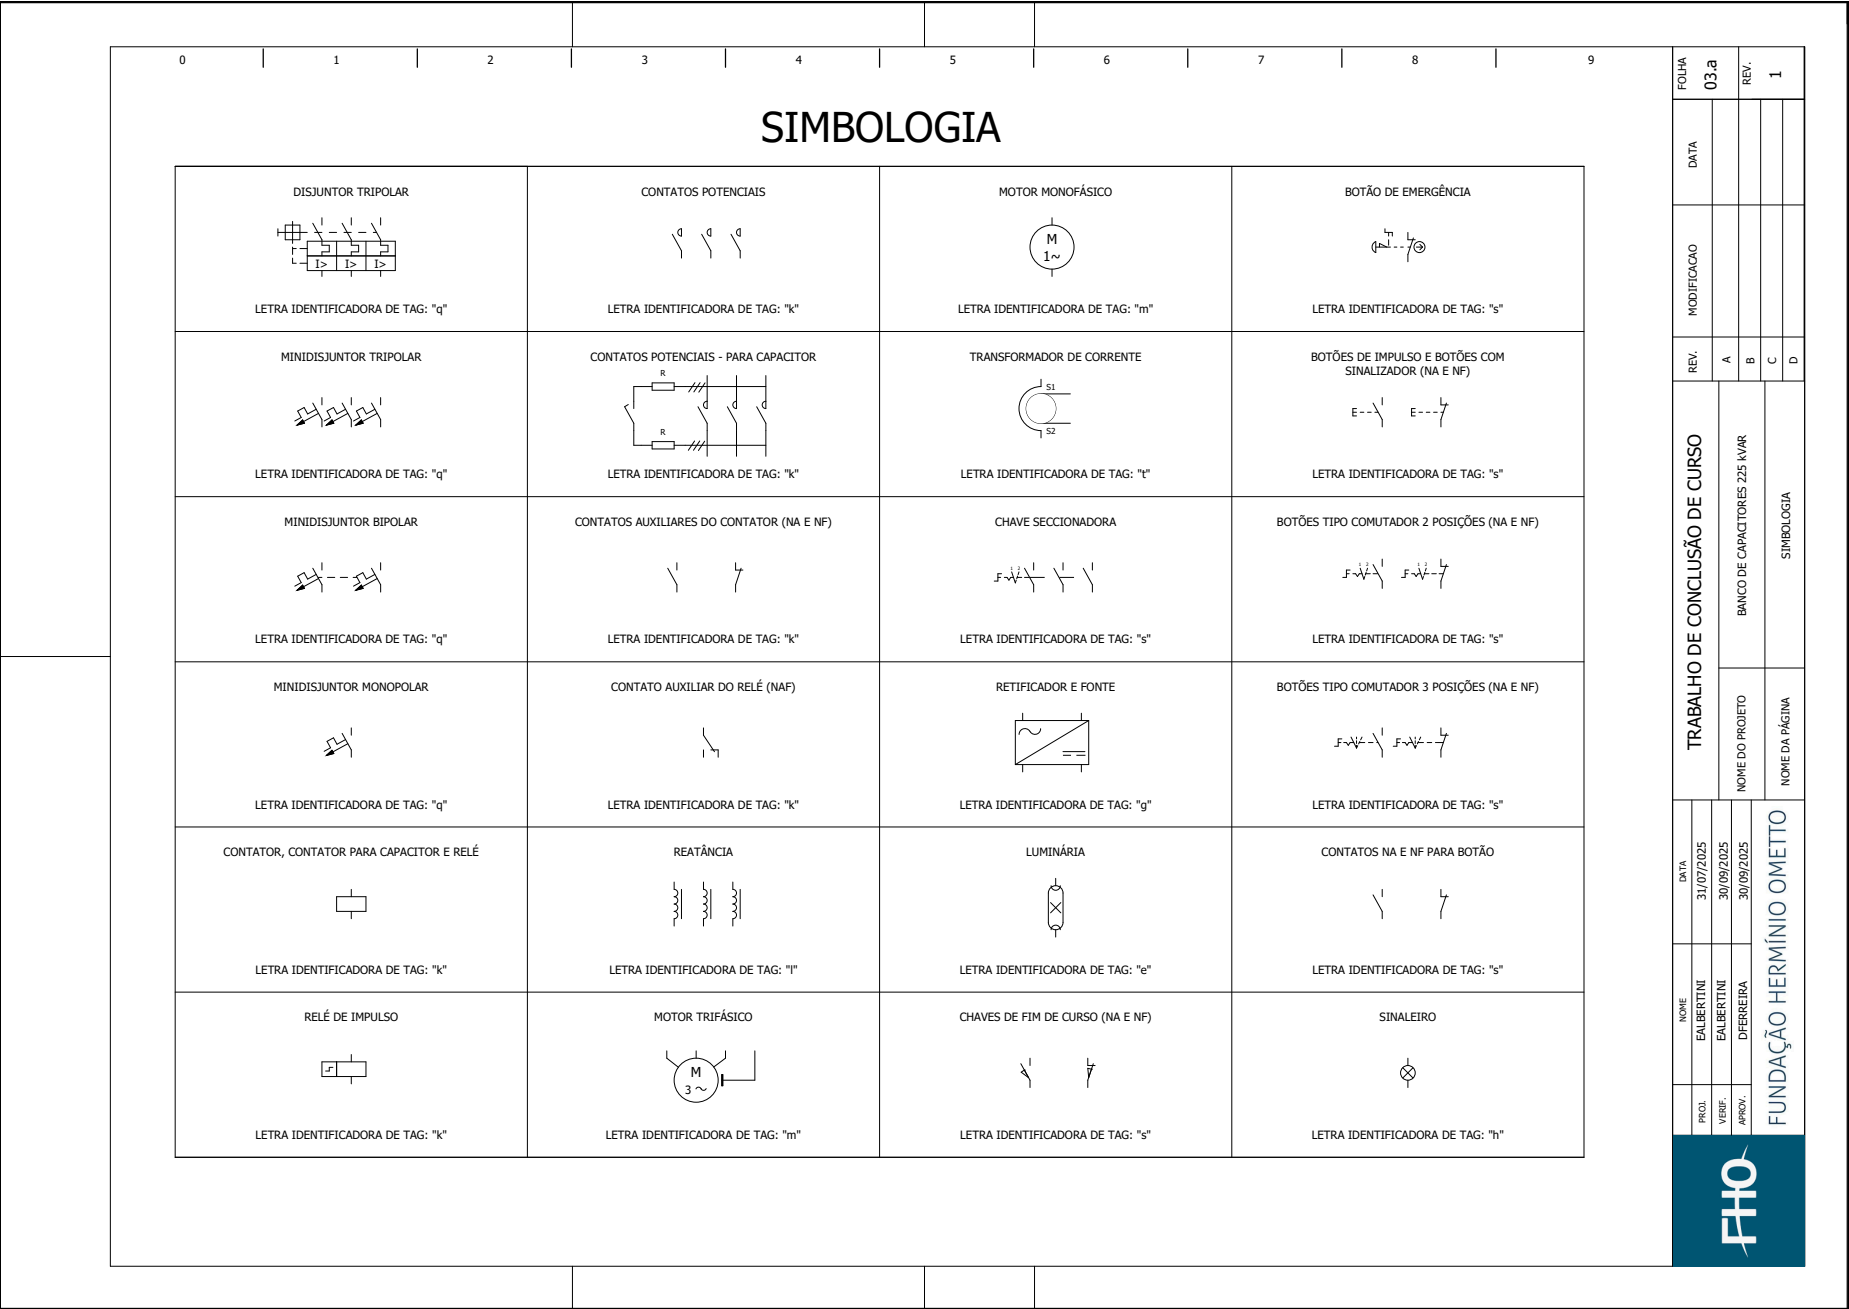
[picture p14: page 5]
EALBERTINI 31/07/2025 PROJ.; VERIF.; NOME DATA; MODIFICACAO REV.; DATA; SIMBOLOGIA; APROV.; 30/09/2025 DFERREIRA; EALBERTINI; MINIDISJUNTOR TRIPOLAR; MINIDISJUNTOR BIPOLAR; MINIDISJUNTOR MONOPOLAR; REATÂNCIA; MOTOR TRIFÁSICO; RETIFICADOR E FONTE; CHAVE SECCIONADORA; LUMINÁRIA; SINALEIRO

REV. NOME DO PROJETO

DISJUNTOR TRIPOLAR | CONTATOS POTENCIAIS LETRA IDENTIFICADORA DE TAG: "k" | MOTOR MONOFÁSICO M 1~ LETRA IDENTIFICADORA DE TAG: "m" | BOTÃO DE EMERGÊNCIA

LETRA IDENTIFICADORA DE TAG: "q"

LETRA IDENTIFICADORA DE TAG: "s"

CONTATOS POTENCIAIS - PARA CAPACITOR

TRANSFORMADOR DE CORRENTE

BOTÕES DE IMPULSO E BOTÕES COM

SINALIZADOR (NA E NF)

TRABALHO DE CONCLUSÃO DE CURSO

BANCO DE CAPACITORES 225 kVAR

LETRA IDENTIFICADORA DE TAG: "k"

LETRA IDENTIFICADORA DE TAG: "t"

CONTATOS AUXILIARES DO CONTATOR (NA E NF)

BOTÕES TIPO COMUTADOR 2 POSIÇÕES (NA E NF)

CONTATO AUXILIAR DO RELÉ (NAF)

BOTÕES TIPO COMUTADOR 3 POSIÇÕES (NA E NF)

NOME DA PÁGINA

LETRA IDENTIFICADORA DE TAG: "g"

CONTATOR, CONTATOR PARA CAPACITOR E RELÉ

CONTATOS NA E NF PARA BOTÃO

LETRA IDENTIFICADORA DE TAG: "l"

LETRA IDENTIFICADORA DE TAG: "e"

RELÉ DE IMPULSO

CHAVES DE FIM DE CURSO (NA E NF)

LETRA IDENTIFICADORA DE TAG: "m"

LETRA IDENTIFICADORA DE TAG: "h"

# SIMBOLOGIA

REV. NOME DO PROJETO

BORNE DE PASSAGEM LETRA IDENTIFICADORA DE TAG: "X" | CONTATO TEMPERATURA (NA E NF) LETRA IDENTIFICADORA DE TAG: "s"

BORNE DE PASSAGEM COM FUSÍVEL

TRABALHO DE CONCLUSÃO DE CURSO

BANCO DE CAPACITORES 225 kVAR

LETRA IDENTIFICADORA DE TAG: "X"

CONECTOR MACHO/FÊMEA

BARRA DE TERRA

NOME DA PÁGINA

LETRA IDENTIFICADORA DE TAG: "PE"

CONDUTOR BLINDADO LETRA IDENTIFICADORA DE TAG: "w" | PE

RESISTÊNCIA DE AQUECIMENTO

LETRA IDENTIFICADORA DE TAG: "r"

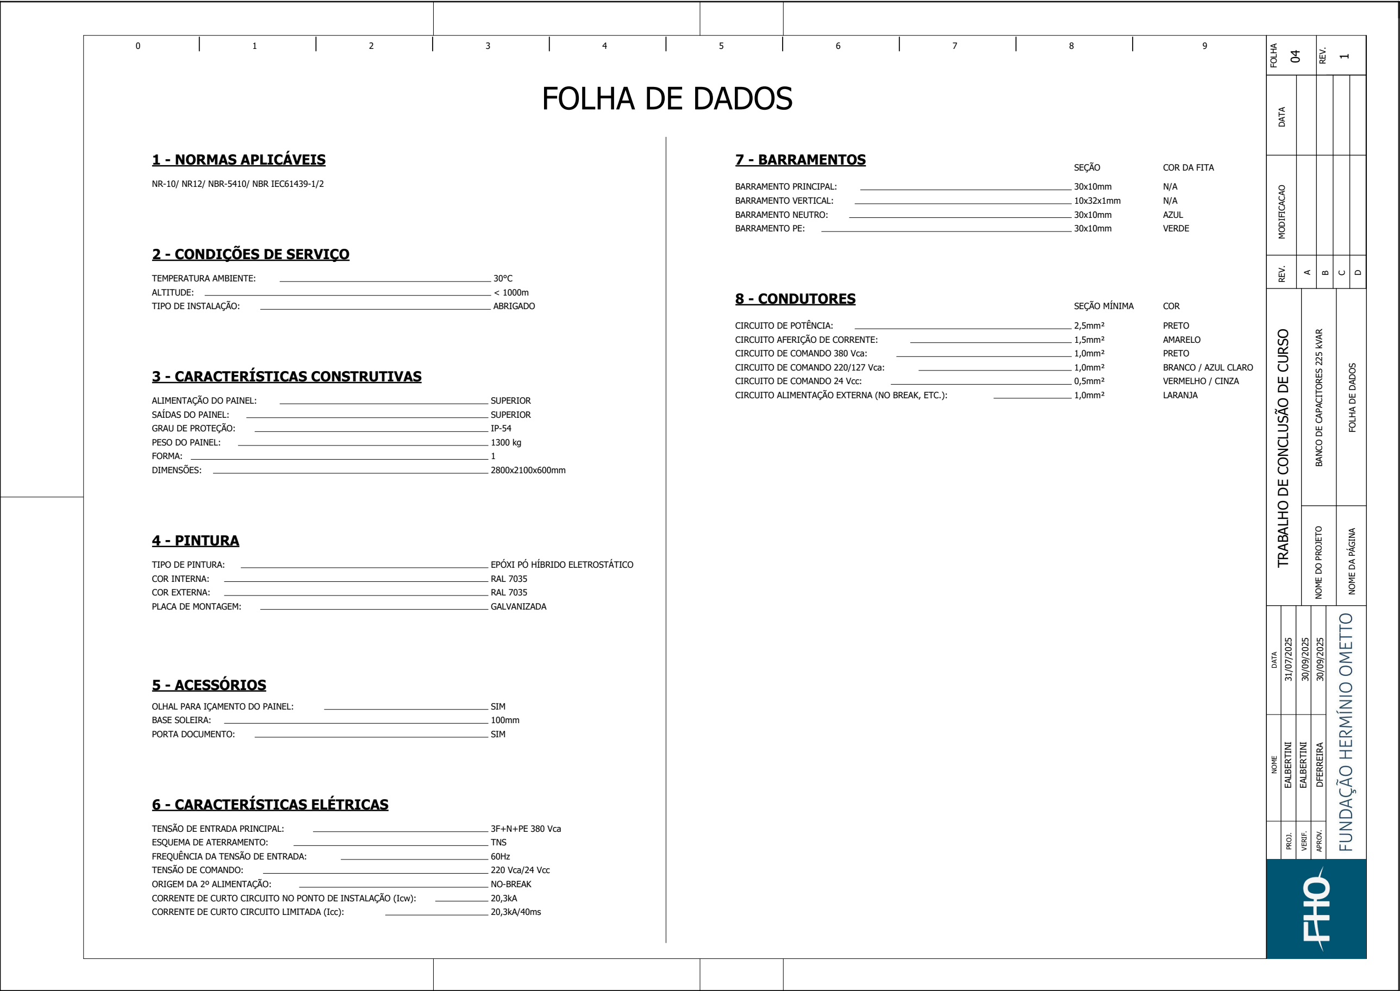
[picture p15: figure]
EALBERTINI 31/07/2025 PROJ.; VERIF.; NOME DATA; MODIFICACAO REV.; DATA; REV. NOME DO PROJETO; NOME DA PÁGINA; BANCO DE CAPACITORES 225 kVAR; FOLHA DE DADOS; APROV.; 30/09/2025 DFERREIRA; TRABALHO DE CONCLUSÃO DE CURSO; EALBERTINI; 3 - CARACTERÍSTICAS CONSTRUTIVAS; 2 - CONDIÇÕES DE SERVIÇO; OLHAL PARA IÇAMENTO DO PAINEL:; 1 - NORMAS APLICÁVEIS; PLACA DE MONTAGEM:; TEMPERATURA AMBIENTE:; ALIMENTAÇÃO DO PAINEL:; COR EXTERNA:; COR INTERNA:; 5 - ACESSÓRIOS; GRAU DE PROTEÇÃO:; SAÍDAS DO PAINEL:; TIPO DE INSTALAÇÃO:; BASE SOLEIRA:; 4 - PINTURA; ALTITUDE:; 6 - CARACTERÍSTICAS ELÉTRICAS; TENSÃO DE ENTRADA PRINCIPAL:; ESQUEMA DE ATERRAMENTO:; ORIGEM DA 2º ALIMENTAÇÃO:; 7 - BARRAMENTOS; SEÇÃO; COR DA FITA; 3F+N+PE 380 Vca; BARRAMENTO PRINCIPAL:; BARRAMENTO VERTICAL:; BARRAMENTO NEUTRO:; BARRAMENTO PE:; 8 - CONDUTORES; TIPO DE PINTURA:; FREQUÊNCIA DA TENSÃO DE ENTRADA:; TENSÃO DE COMANDO:; NR-10/ NR12/ NBR-5410/ NBR IEC61439-1/2; ABRIGADO; SUPERIOR; RAL 7035; GALVANIZADA; SIM; TNS; 220 Vca/24 Vcc; EPÓXI PÓ HÍBRIDO ELETROSTÁTICO; PORTA DOCUMENTO:; PESO DO PAINEL:; FORMA:; DIMENSÕES:; NO-BREAK; AZUL; VERDE; CIRCUITO DE POTÊNCIA:; CIRCUITO AFERIÇÃO DE CORRENTE:; CIRCUITO DE COMANDO 380 Vca:; CIRCUITO DE COMANDO 220/127 Vca:; SEÇÃO MÍNIMA; COR; CIRCUITO DE COMANDO 24 Vcc:; 2,5mm²; 1,5mm²; 1,0mm²; PRETO; AMARELO; BRANCO / AZUL CLARO; 0,5mm²; VERMELHO / CINZA; LARANJA

CORRENTE DE CURTO CIRCUITO NO PONTO DE INSTALAÇÃO (Icw):

CORRENTE DE CURTO CIRCUITO LIMITADA (Icc):

CIRCUITO ALIMENTAÇÃO EXTERNA (NO BREAK, ETC.):

20,3kA

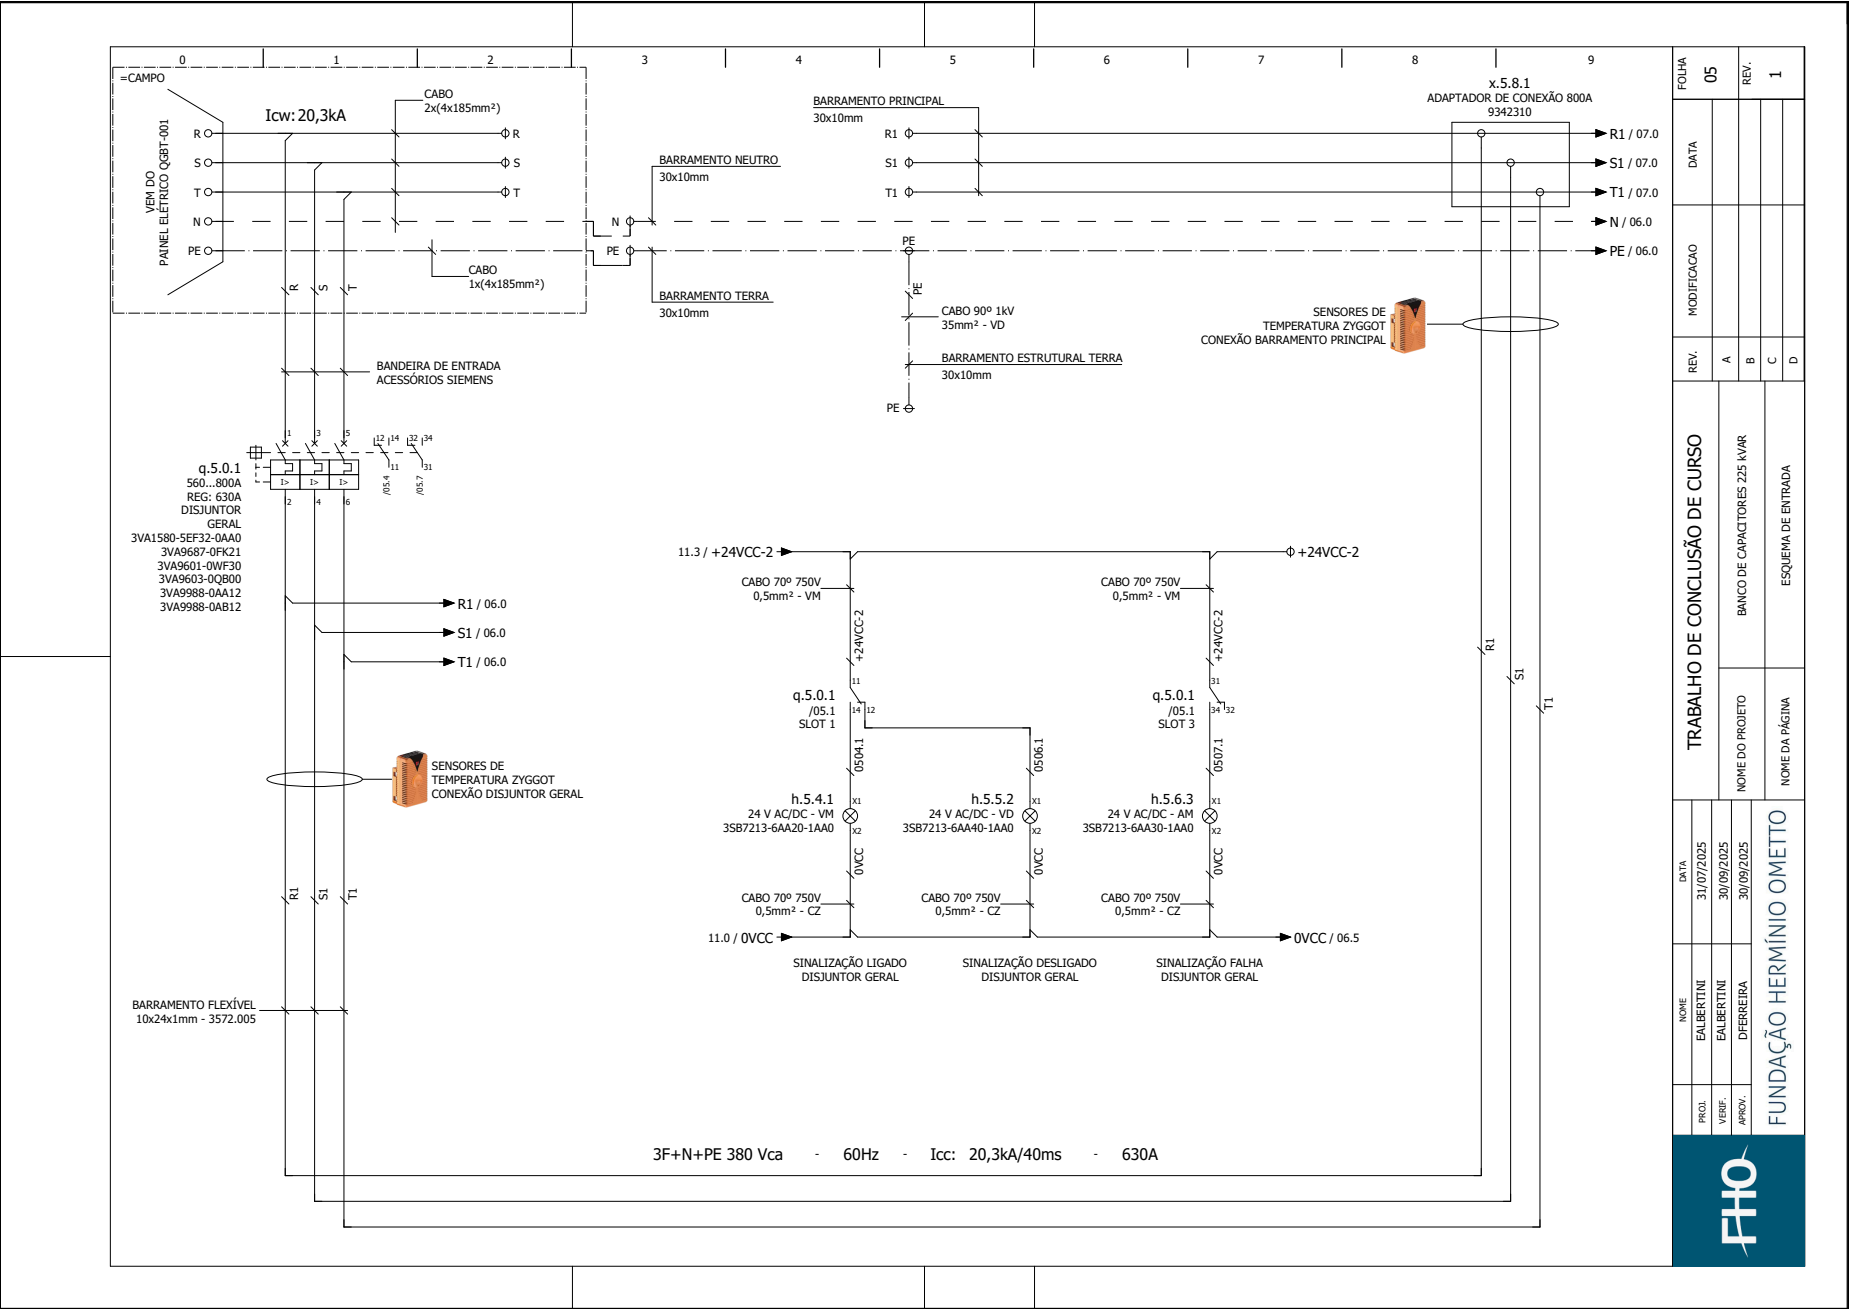
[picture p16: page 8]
EALBERTINI 31/07/2025 PROJ.; VERIF.; NOME DATA; MODIFICACAO REV.; DATA; APROV.; 30/09/2025 DFERREIRA; EALBERTINI; VEM DO; CABO 1x(4x185mm²); CABO 2x(4x185mm²) Icw:; Icc:; BARRAMENTO PRINCIPAL; BARRAMENTO FLEXÍVEL; BARRAMENTO NEUTRO; BARRAMENTO TERRA; 3F+N+PE 380 Vca; CABO 70º 750V 0,5mm² - VM; SINALIZAÇÃO LIGADO; +24VCC-2; SINALIZAÇÃO DESLIGADO DISJUNTOR GERAL; SINALIZAÇÃO FALHA DISJUNTOR GERAL; 0VCC; CABO 70º 750V 0,5mm² - CZ; CABO 90º 1kV 35mm² - VD; SENSORES DE TEMPERATURA ZYGGOT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

REV. NOME DO PROJETO

ADAPTADOR DE CONEXÃO 800A

PAINEL ELÉTRICO QGBT-001

CONEXÃO BARRAMENTO PRINCIPAL

BARRAMENTO ESTRUTURAL TERRA

BANDEIRA DE ENTRADA
ACESSÓRIOS SIEMENS

TRABALHO DE CONCLUSÃO DE CURSO

BANCO DE CAPACITORES 225 kVAR

ESQUEMA DE ENTRADA

11.3 / +24VCC-2
DISJUNTOR GERAL ⁺²⁴VCC⁻2 0VCC

NOME DA PÁGINA

SENSORES DE
TEMPERATURA ZYGGOT
CONEXÃO DISJUNTOR GERAL

## - Icc:

3F+N+PE 380 Vca | 60Hz | 20,3kA/40ms | 630A

REV. NOME DO PROJETO

TRABALHO DE CONCLUSÃO DE CURSO

BANCO DE CAPACITORES 225 kVAR

DIAGRAMA DO DPS

NOME DA PÁGINA

## 3F+N+PE 380 Vca

- 60Hz

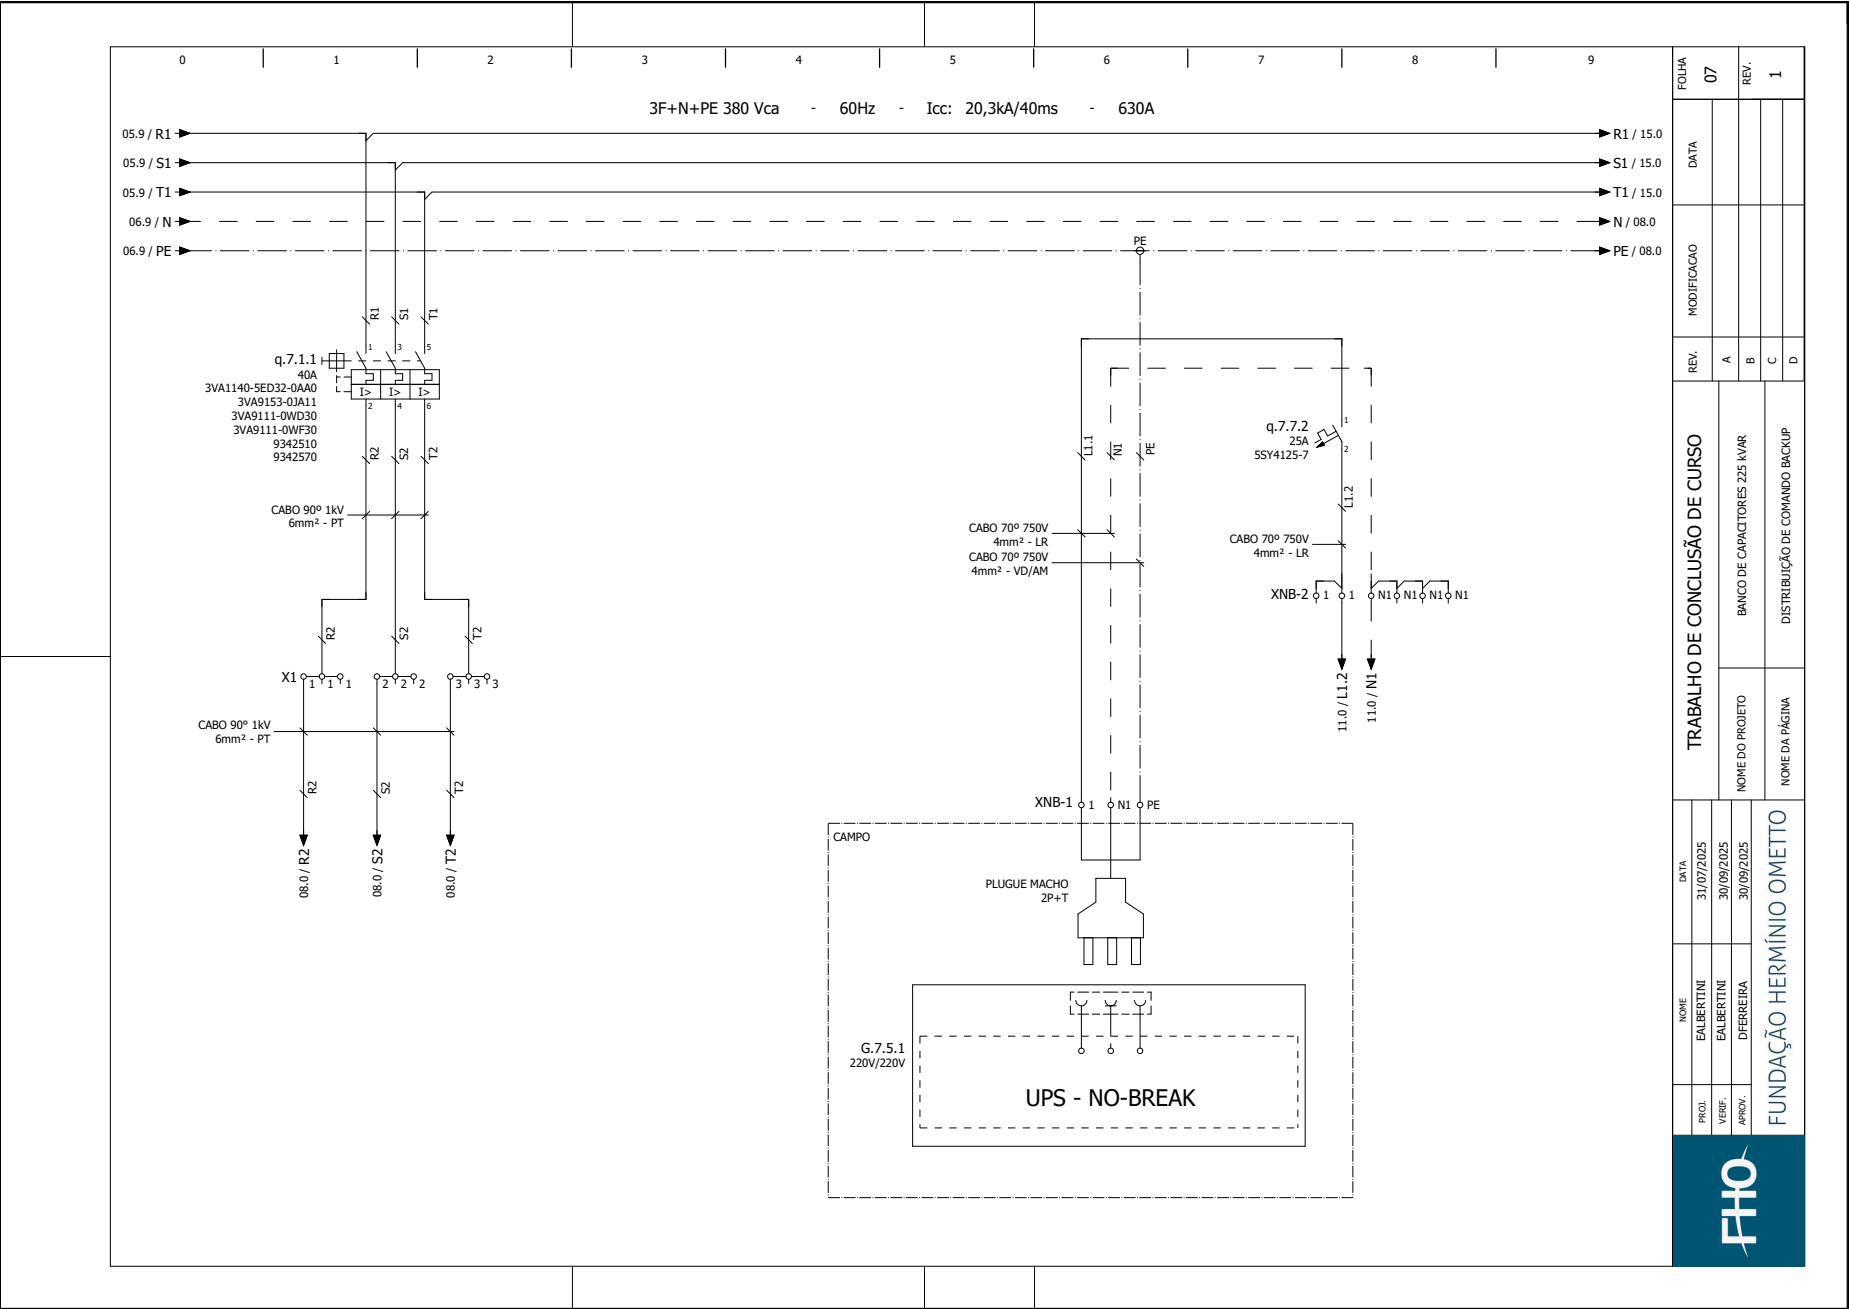
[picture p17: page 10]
EALBERTINI 31/07/2025 PROJ.; VERIF.; NOME DATA; MODIFICACAO REV.; DATA; APROV.; 30/09/2025 DFERREIRA; EALBERTINI; CABO 90º 1kV 6mm² - PT; - Icc: 20,3kA/40ms; CABO 90° 1kV 6mm² - PT; CABO 70º 750V 4mm² - LR CABO 70º 750V 4mm² - VD/AM; CABO 70º 750V 4mm² - LR; PLUGUE MACHO 2P+T; XNB-1; PEPE; XNB-2; CAMPO

REV. NOME DO PROJETO

DISTRIBUIÇÃO DE COMANDO BACKUP

TRABALHO DE CONCLUSÃO DE CURSO

BANCO DE CAPACITORES 225 kVAR

NOME DA PÁGINA

UPS - NO-BREAK

## - Icc:

3F+N+PE 380 Vca | 60Hz | 20,3kA/40ms | 630A

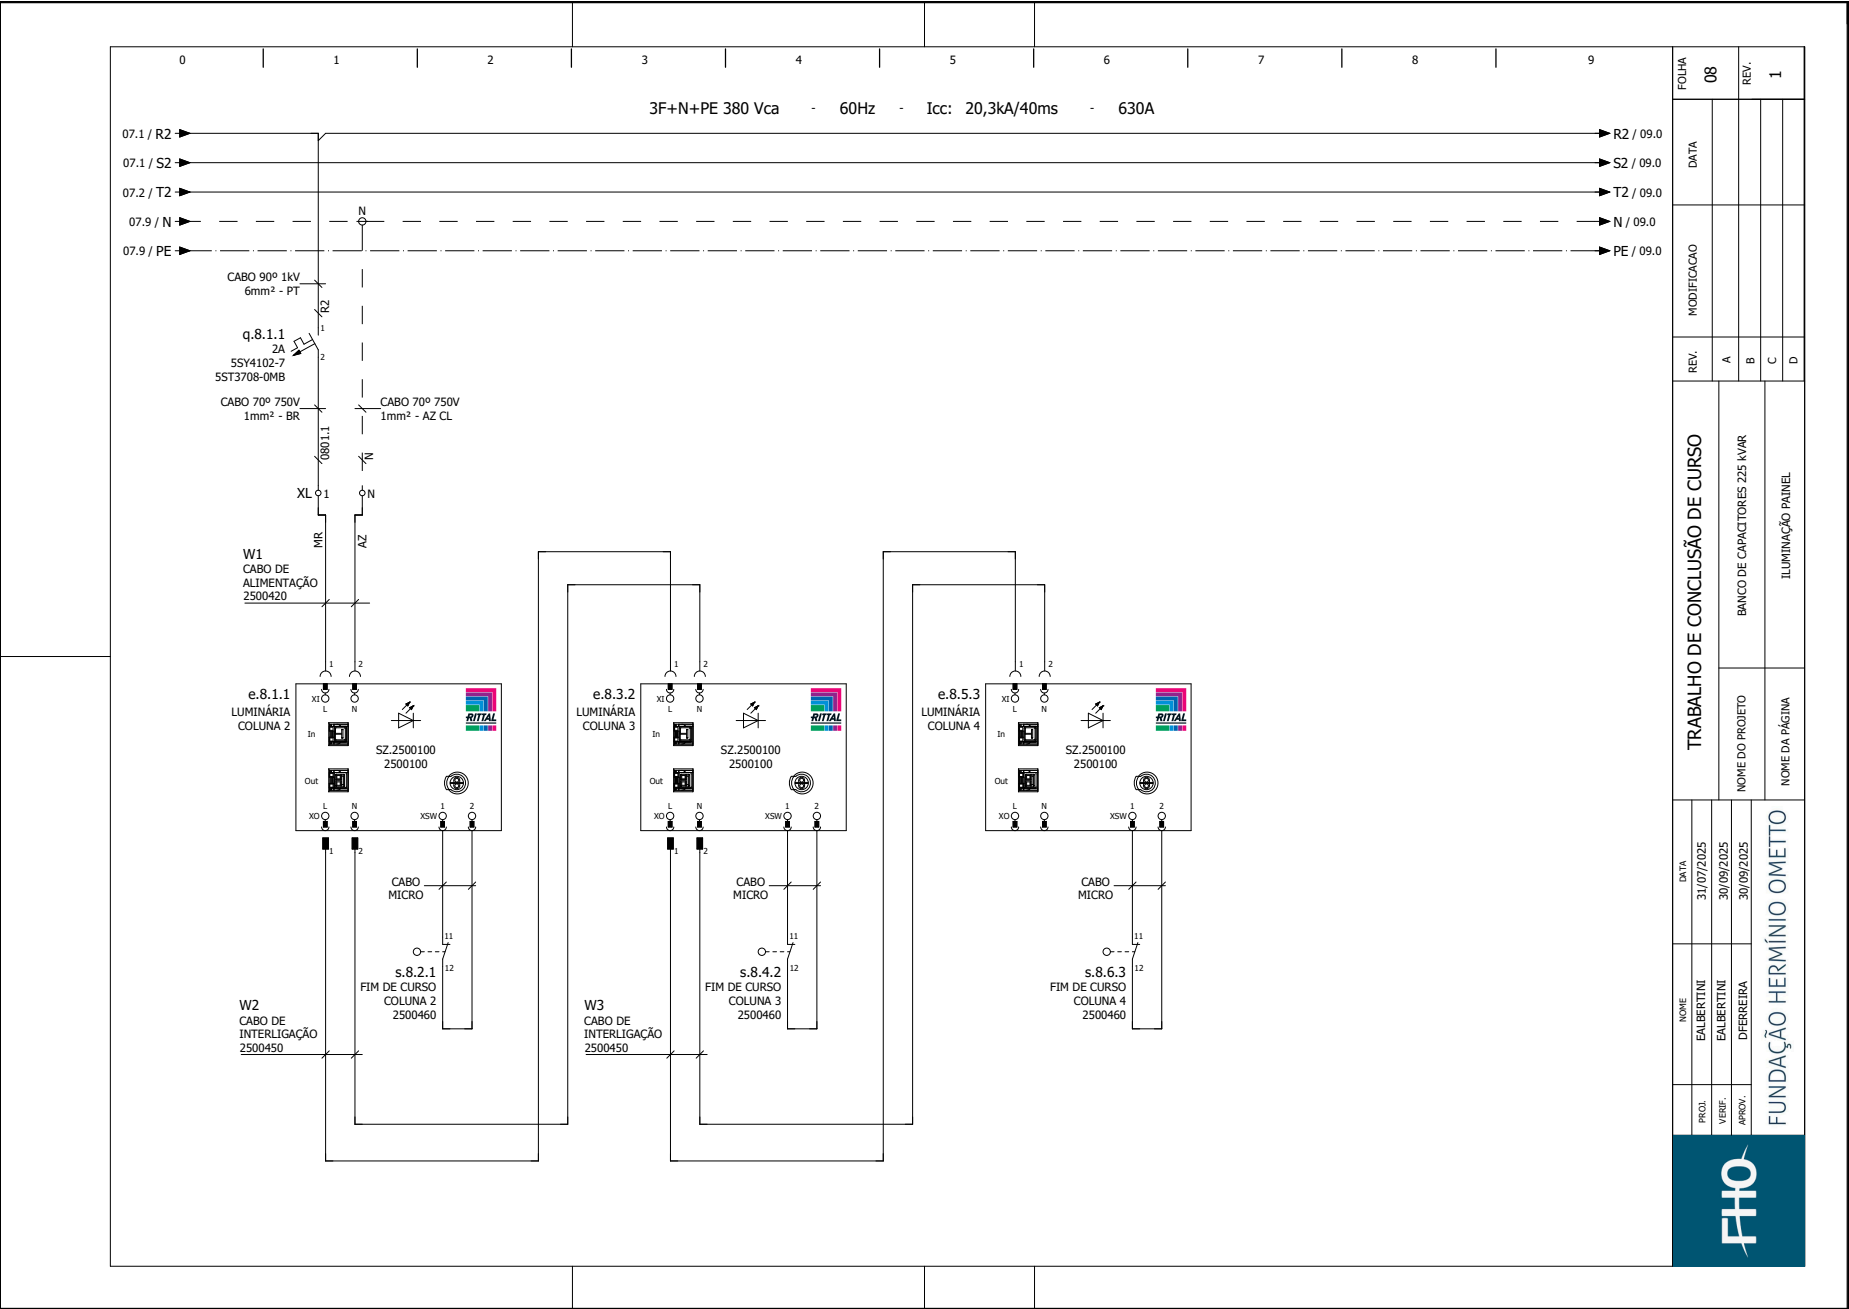
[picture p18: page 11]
EALBERTINI 31/07/2025 PROJ.; VERIF.; NOME DATA; MODIFICACAO REV.; DATA; ILUMINAÇÃO PAINEL; APROV.; 30/09/2025 DFERREIRA; EALBERTINI; Out; e.8.1.1 LUMINÁRIA; COLUNA 2; XSW; e.8.3.2 LUMINÁRIA; COLUNA 3; e.8.5.3 LUMINÁRIA; COLUNA 4; CABO 70º 750V 1mm² - BR; CABO 70º 750V 1mm² - AZ CL; CABO MICRO; CABO 90º 1kV 6mm² - PT; W2 CABO DE INTERLIGAÇÃO 2500450; W1 CABO DE ALIMENTAÇÃO 2500420; W3 CABO DE INTERLIGAÇÃO 2500450; s.8.2.1 FIM DE CURSO COLUNA 2 2500460; FIM DE CURSO COLUNA 3 2500460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

REV. NOME DO PROJETO

TRABALHO DE CONCLUSÃO DE CURSO

BANCO DE CAPACITORES 225 kVAR

NOME DA PÁGINA

## 3F+N+PE 380 Vca

- 60Hz

REV. NOME DO PROJETO

TRABALHO DE CONCLUSÃO DE CURSO

BANCO DE CAPACITORES 225 kVAR

NOME DA PÁGINA

## 3F+N+PE 380 Vca

- 60Hz

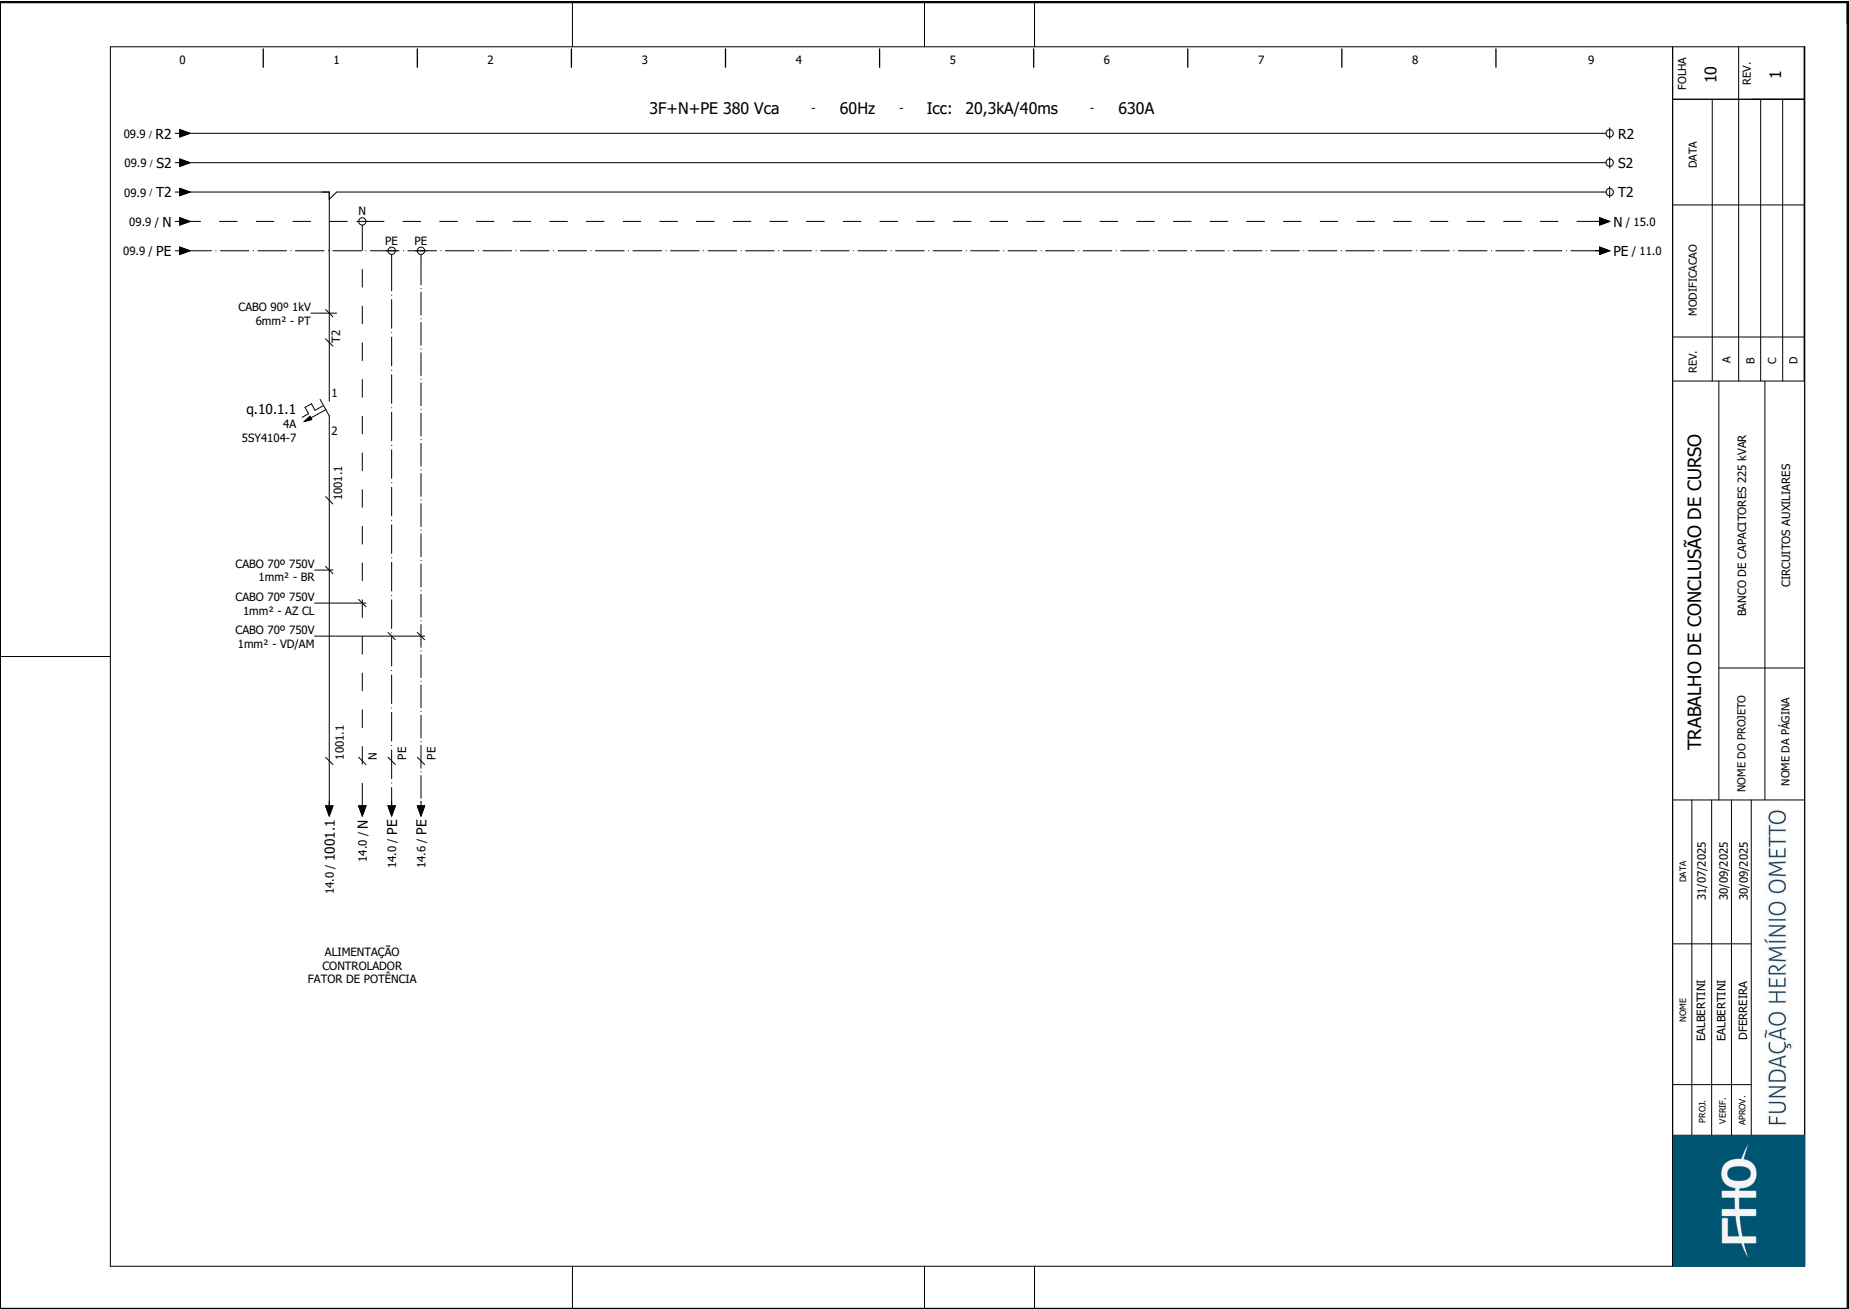
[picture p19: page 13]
EALBERTINI 31/07/2025 PROJ.; VERIF.; NOME DATA; MODIFICACAO REV.; DATA; CIRCUITOS AUXILIARES; APROV.; 30/09/2025 DFERREIRA; EALBERTINI; - Icc: 20,3kA/40ms; ALIMENTAÇÃO CONTROLADOR; CABO 90º 1kV 6mm² - PT

REV. NOME DO PROJETO

TRABALHO DE CONCLUSÃO DE CURSO

BANCO DE CAPACITORES 225 kVAR

CABO 70º 750V
1mm² - BR
1mm² - AZ CL
1mm² - VD/AM
FATOR DE POTÊNCIA ¹⁰⁰¹.1

NOME DA PÁGINA

## 3F+N+PE 380 Vca

- 60Hz

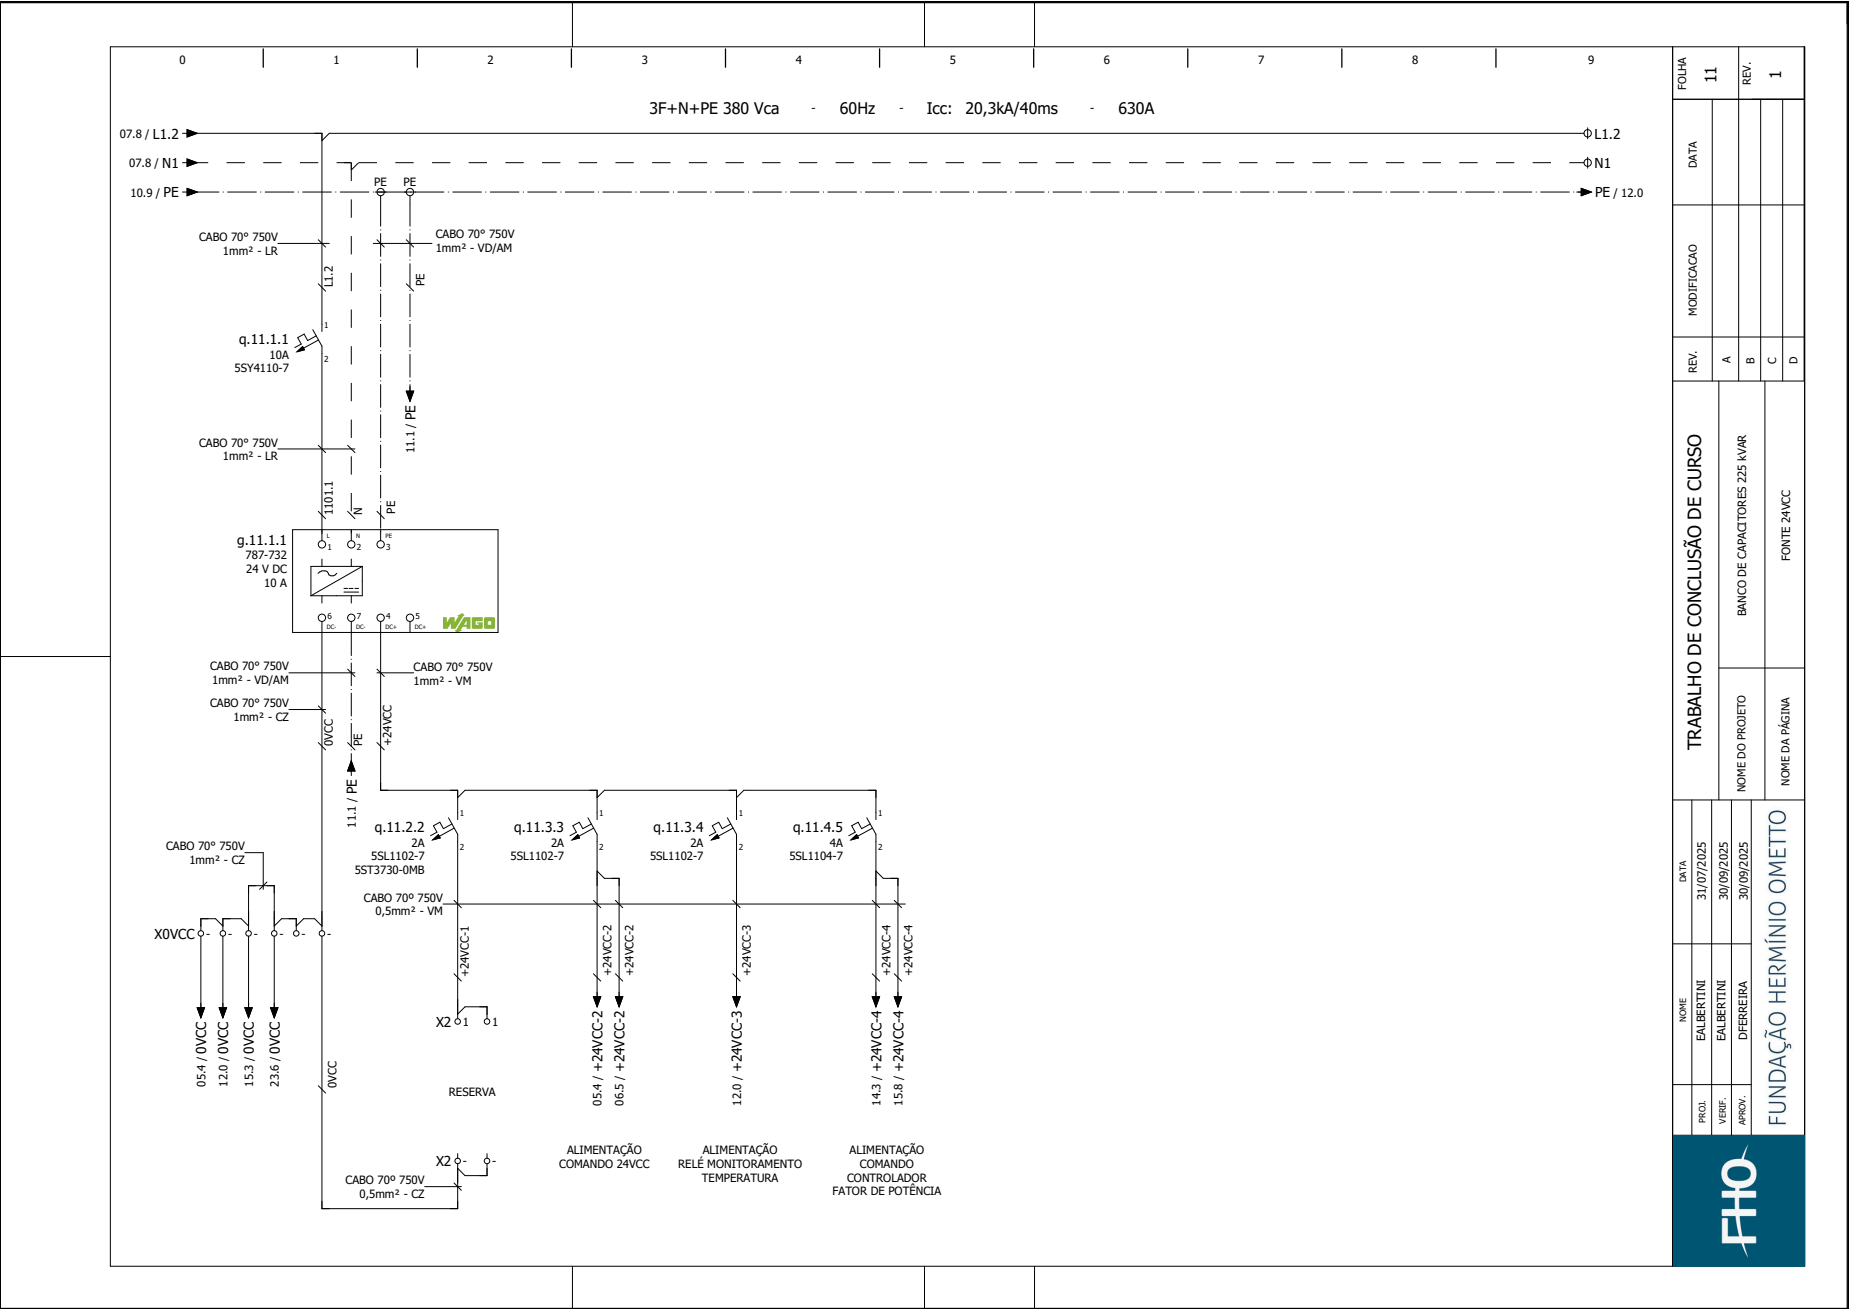
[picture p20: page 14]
EALBERTINI 31/07/2025 PROJ.; VERIF.; NOME DATA; MODIFICACAO REV.; DATA; FONTE 24VCC; APROV.; 30/09/2025 DFERREIRA; EALBERTINI; CABO 70º 750V 0,5mm² - VM; RESERVA; CABO 70º 750V 0,5mm² - CZ; CABO 70° 750V 1mm² - CZ; CABO 70° 750V 1mm² - VM; CABO 70° 750V 1mm² - VD/AM; ALIMENTAÇÃO; COMANDO 24VCC ⁺²⁴VCC⁻2; +24VCC-3; ALIMENTAÇÃO RELÉ MONITORAMENTO; TEMPERATURA; +24VCC-2; - Icc: 20,3kA/40ms; CABO 70° 750V 1mm² - LR; +24VCC-4; +24VCC-1; 0VCC 0VCC; +24VCC; X0VCC; +24VCC-2 / 05.4; +24VCC-3 / 12.0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

REV. NOME DO PROJETO

TRABALHO DE CONCLUSÃO DE CURSO

BANCO DE CAPACITORES 225 kVAR

NOME DA PÁGINA

ALIMENTAÇÃO
COMANDO
CONTROLADOR
FATOR DE POTÊNCIA

## 3F+N+PE 380 Vca

- 60Hz

REV. NOME DO PROJETO

RELÉ DE MONITORAMENTO E PROTEÇÃO DE

TRABALHO DE CONCLUSÃO DE CURSO

BANCO DE CAPACITORES 225 kVAR

RELÉ DE MONITORAMENTO
DE TEMPERATURA

NOME DA PÁGINA

PINOS 12345678 | CTS

SINAL

RTS

RXD

TXD

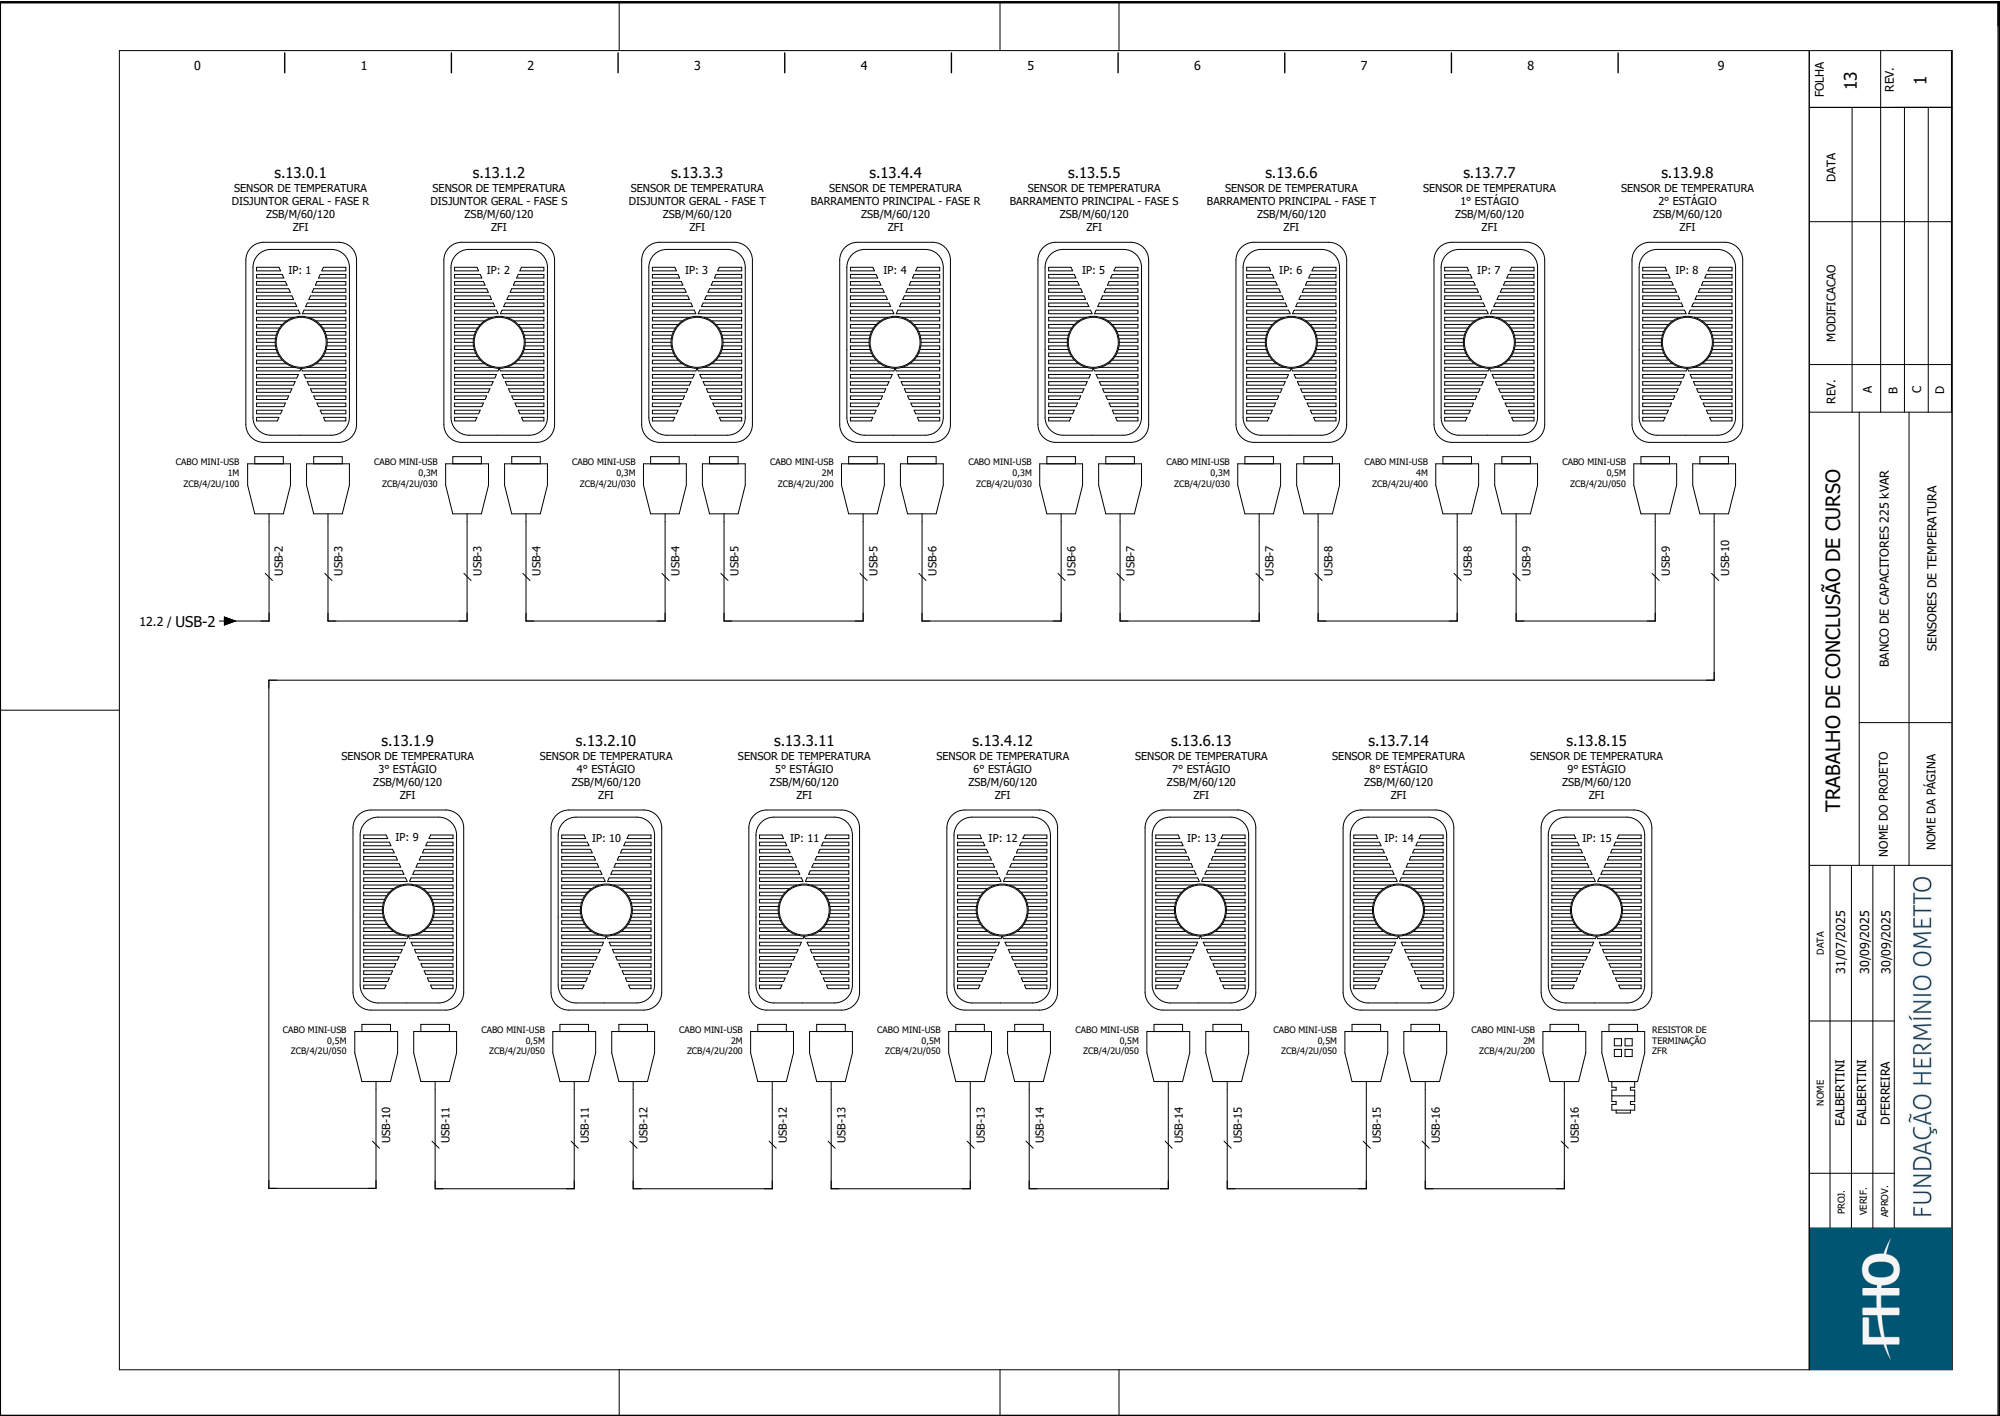
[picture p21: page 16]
EALBERTINI 31/07/2025 PROJ.; VERIF.; NOME DATA; MODIFICACAO REV.; DATA; APROV.; 30/09/2025 DFERREIRA; EALBERTINI; USB-2; USB-3; USB-4; USB-5; USB-6; USB-7; USB-8; USB-9; USB-10; USB-11; USB-12; USB-13; USB-14; USB-15; USB-16; 1M ZCB/4/2U/100; 0,3M ZCB/4/2U/030; RESISTOR DE TERMINAÇÃO ZFR; ZSB/M/60/120 ZFI; 1° ESTÁGIO ZSB/M/60/120 ZFI; 2° ESTÁGIO ZSB/M/60/120 ZFI; 2M ZCB/4/2U/200; 4M ZCB/4/2U/400; 0,5M ZCB/4/2U/050; 3° ESTÁGIO ZSB/M/60/120 ZFI; 4° ESTÁGIO ZSB/M/60/120 ZFI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

REV. NOME DO PROJETO

SENSOR DE TEMPERATURA
DISJUNTOR GERAL - FASE R

DISJUNTOR GERAL - FASE S

DISJUNTOR GERAL - FASE T

BARRAMENTO PRINCIPAL - FASE R

BARRAMENTO PRINCIPAL - FASE S

BARRAMENTO PRINCIPAL - FASE T

CABO MINI-USB

TRABALHO DE CONCLUSÃO DE CURSO

BANCO DE CAPACITORES 225 kVAR

SENSORES DE TEMPERATURA

NOME DA PÁGINA

3F+N+PE 380 Vca | - | 60Hz | - | Icc: 20,3kA/40ms | - | 630A

## PAINEL ELÉTRICO QGBT-001

REV. NOME DO PROJETO

SINAL DE TENSÃO
220VAC - 50/60Hz

SINAL DE CORRENTE

CONTROLADOR FATOR DE POTÊNCIA

TRABALHO DE CONCLUSÃO DE CURSO

BANCO DE CAPACITORES 225 kVAR

BORNE DE AFERIÇÃO PARA 1 TC'S

NOME DA PÁGINA

220 VAC - 60 Hz

SINAL DE CORRENTE (FASE R)
CONTROLADOR F.P.

CONTROLADOR DE FATOR DE POTÊNCIA

PAINEL ELÉTRICO QGBT-001

3F+N+PE 380 Vca | - | 60Hz | - | Icc: 20,3kA/40ms | - | 630A

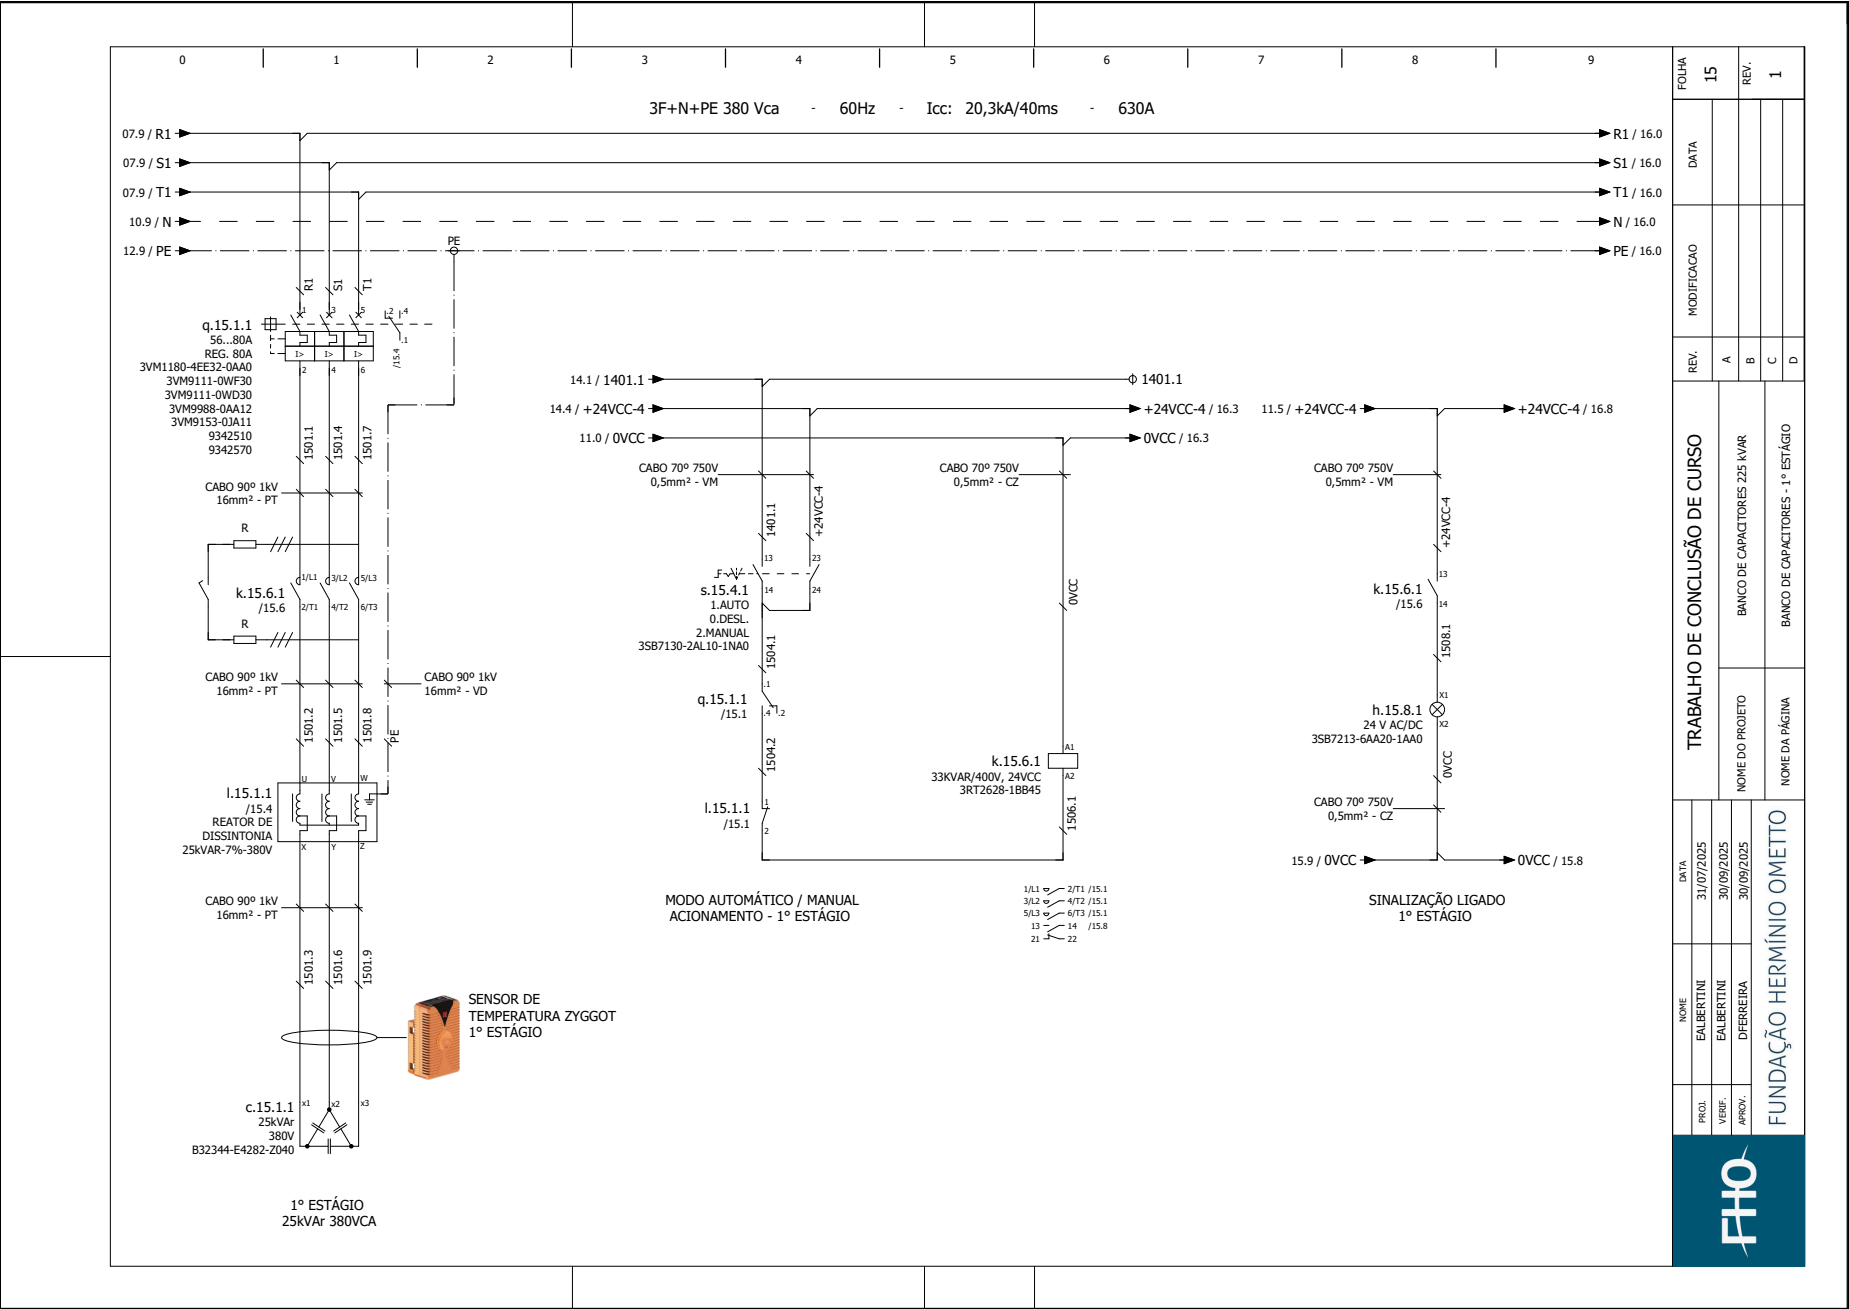
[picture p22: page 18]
EALBERTINI 31/07/2025 PROJ.; VERIF.; NOME DATA; MODIFICACAO REV.; DATA; APROV.; 30/09/2025 DFERREIRA; EALBERTINI; CABO 90º 1kV 16mm² - PT; 1° ESTÁGIO 25kVAr 380VCA; CABO 70º 750V 0,5mm² - CZ; CABO 70º 750V 0,5mm² - VM; CABO 90º 1kV 16mm² - VD; SINALIZAÇÃO LIGADO 1° ESTÁGIO; +24VCC-4; SENSOR DE TEMPERATURA ZYGGOT 1° ESTÁGIO; c.15.1.1 25kVAr 380V B32344-E4282-Z040; k.15.6.1 33KVAR/400V, 24VCC 3RT2628-1BB45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

REV. NOME DO PROJETO

BANCO DE CAPACITORES - 1° ESTÁGIO

TRABALHO DE CONCLUSÃO DE CURSO

BANCO DE CAPACITORES 225 kVAR

NOME DA PÁGINA

MODO AUTOMÁTICO / MANUAL
ACIONAMENTO - 1° ESTÁGIO

3F+N+PE 380 Vca | - | 60Hz | - | Icc: 20,3kA/40ms | - | 630A

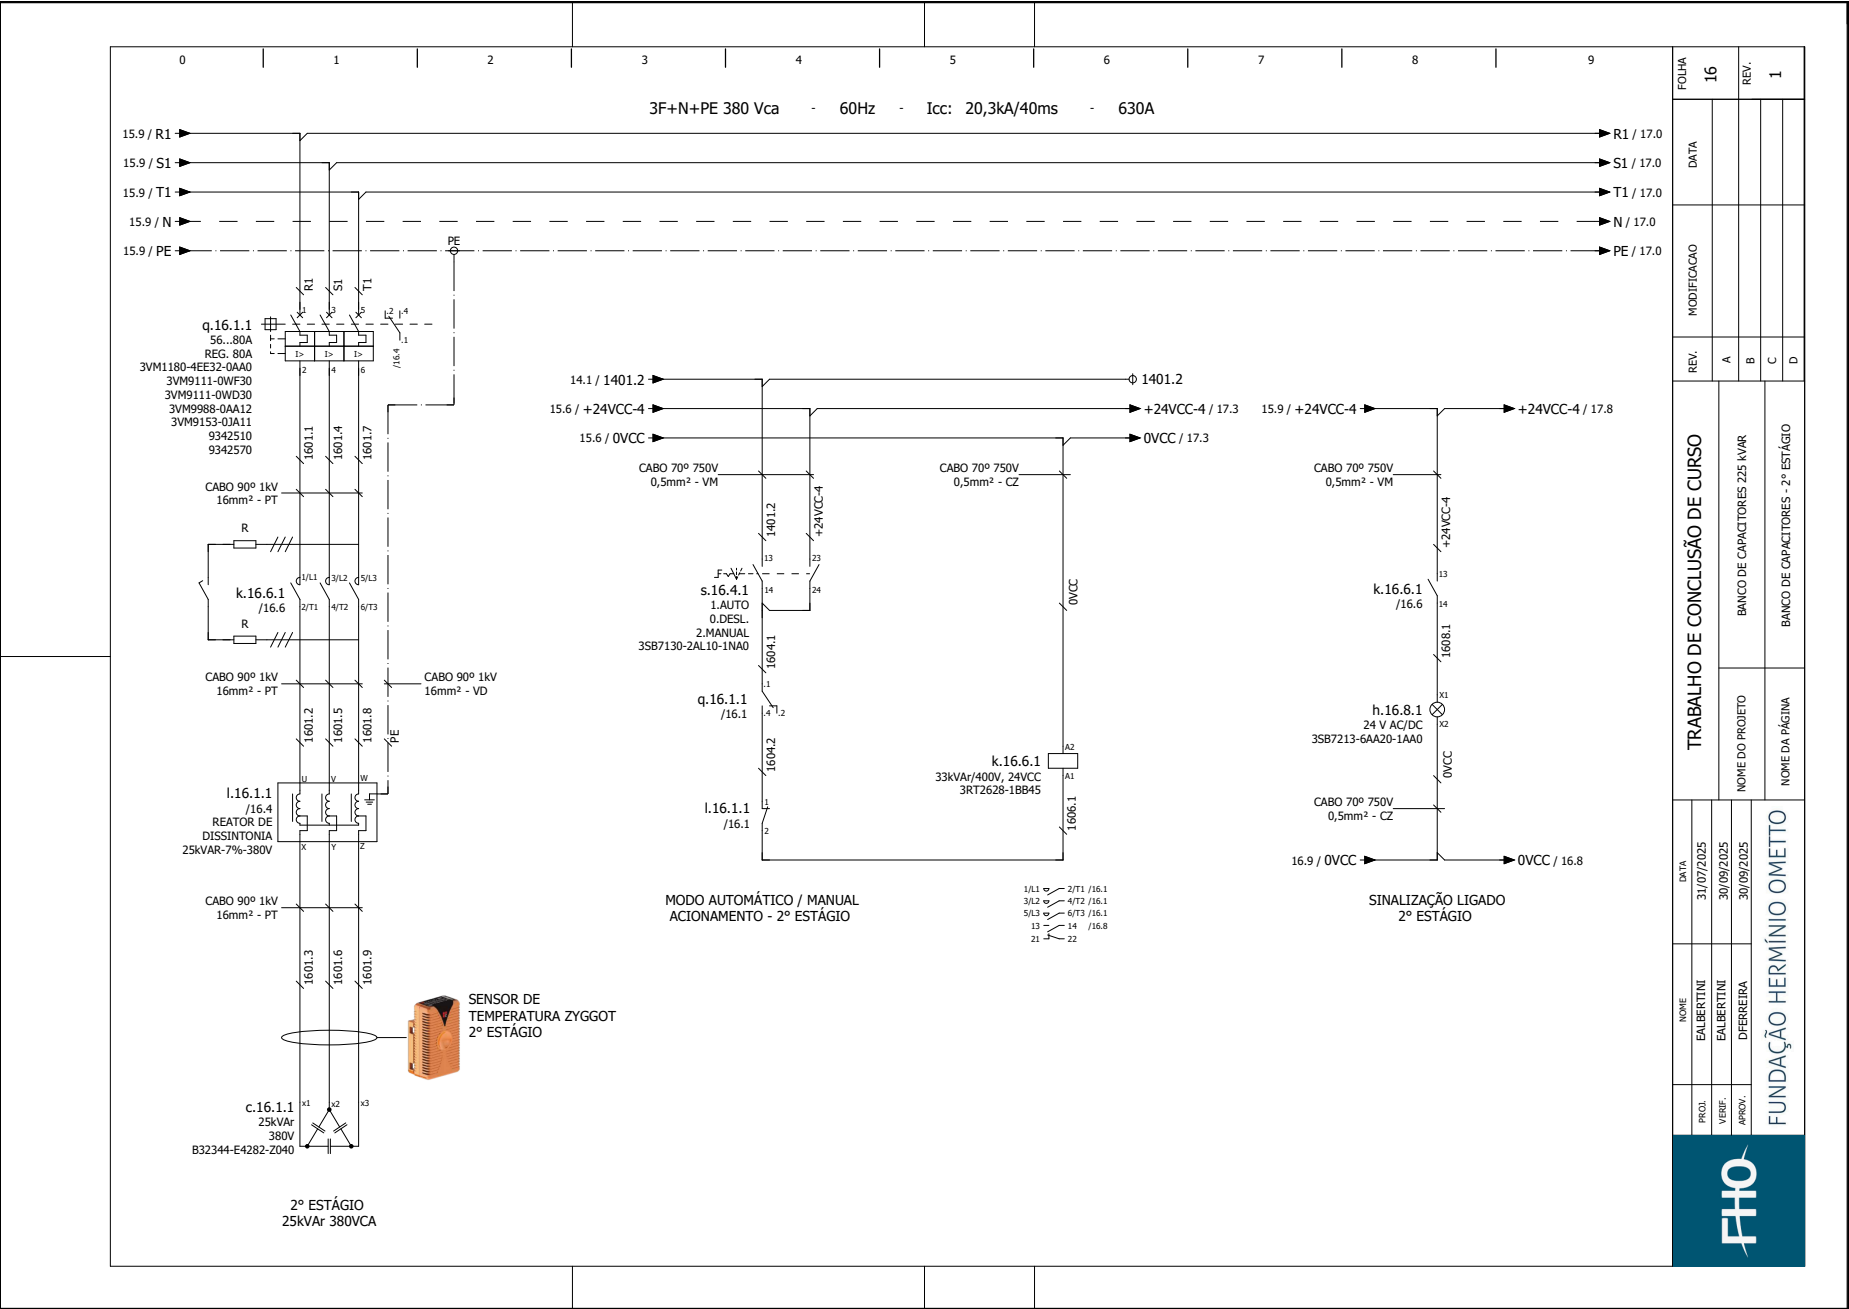
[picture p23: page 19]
EALBERTINI 31/07/2025 PROJ.; VERIF.; NOME DATA; MODIFICACAO REV.; DATA; APROV.; 30/09/2025 DFERREIRA; EALBERTINI; CABO 90º 1kV 16mm² - PT; 2° ESTÁGIO 25kVAr 380VCA; CABO 90º 1kV 16mm² - VD; SINALIZAÇÃO LIGADO 2° ESTÁGIO; SENSOR DE TEMPERATURA ZYGGOT 2° ESTÁGIO; +24VCC-4; CABO 70º 750V 0,5mm² - VM; CABO 70º 750V 0,5mm² - CZ; c.16.1.1 25kVAr 380V B32344-E4282-Z040; q.16.1.1 56...80A REG. 80A 3VM1180-4EE32-0AA0 3VM9111-0WF30 3VM9111-0WD30 3VM9988-0AA12 3VM9153-0JA11 9342510 9342570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

REV. NOME DO PROJETO

ACIONAMENTO - 2° ESTÁGIO ¹⁴⁰¹.2

BANCO DE CAPACITORES - 2° ESTÁGIO

TRABALHO DE CONCLUSÃO DE CURSO

BANCO DE CAPACITORES 225 kVAR

NOME DA PÁGINA

MODO AUTOMÁTICO / MANUAL

3F+N+PE 380 Vca | - | 60Hz | - | Icc: 20,3kA/40ms | - | 630A

REV. NOME DO PROJETO

ACIONAMENTO - 3° ESTÁGIO ¹⁴⁰².1

BANCO DE CAPACITORES - 3° ESTÁGIO

TRABALHO DE CONCLUSÃO DE CURSO

BANCO DE CAPACITORES 225 kVAR

NOME DA PÁGINA

MODO AUTOMÁTICO / MANUAL

3F+N+PE 380 Vca | - | 60Hz | - | Icc: 20,3kA/40ms | - | 630A

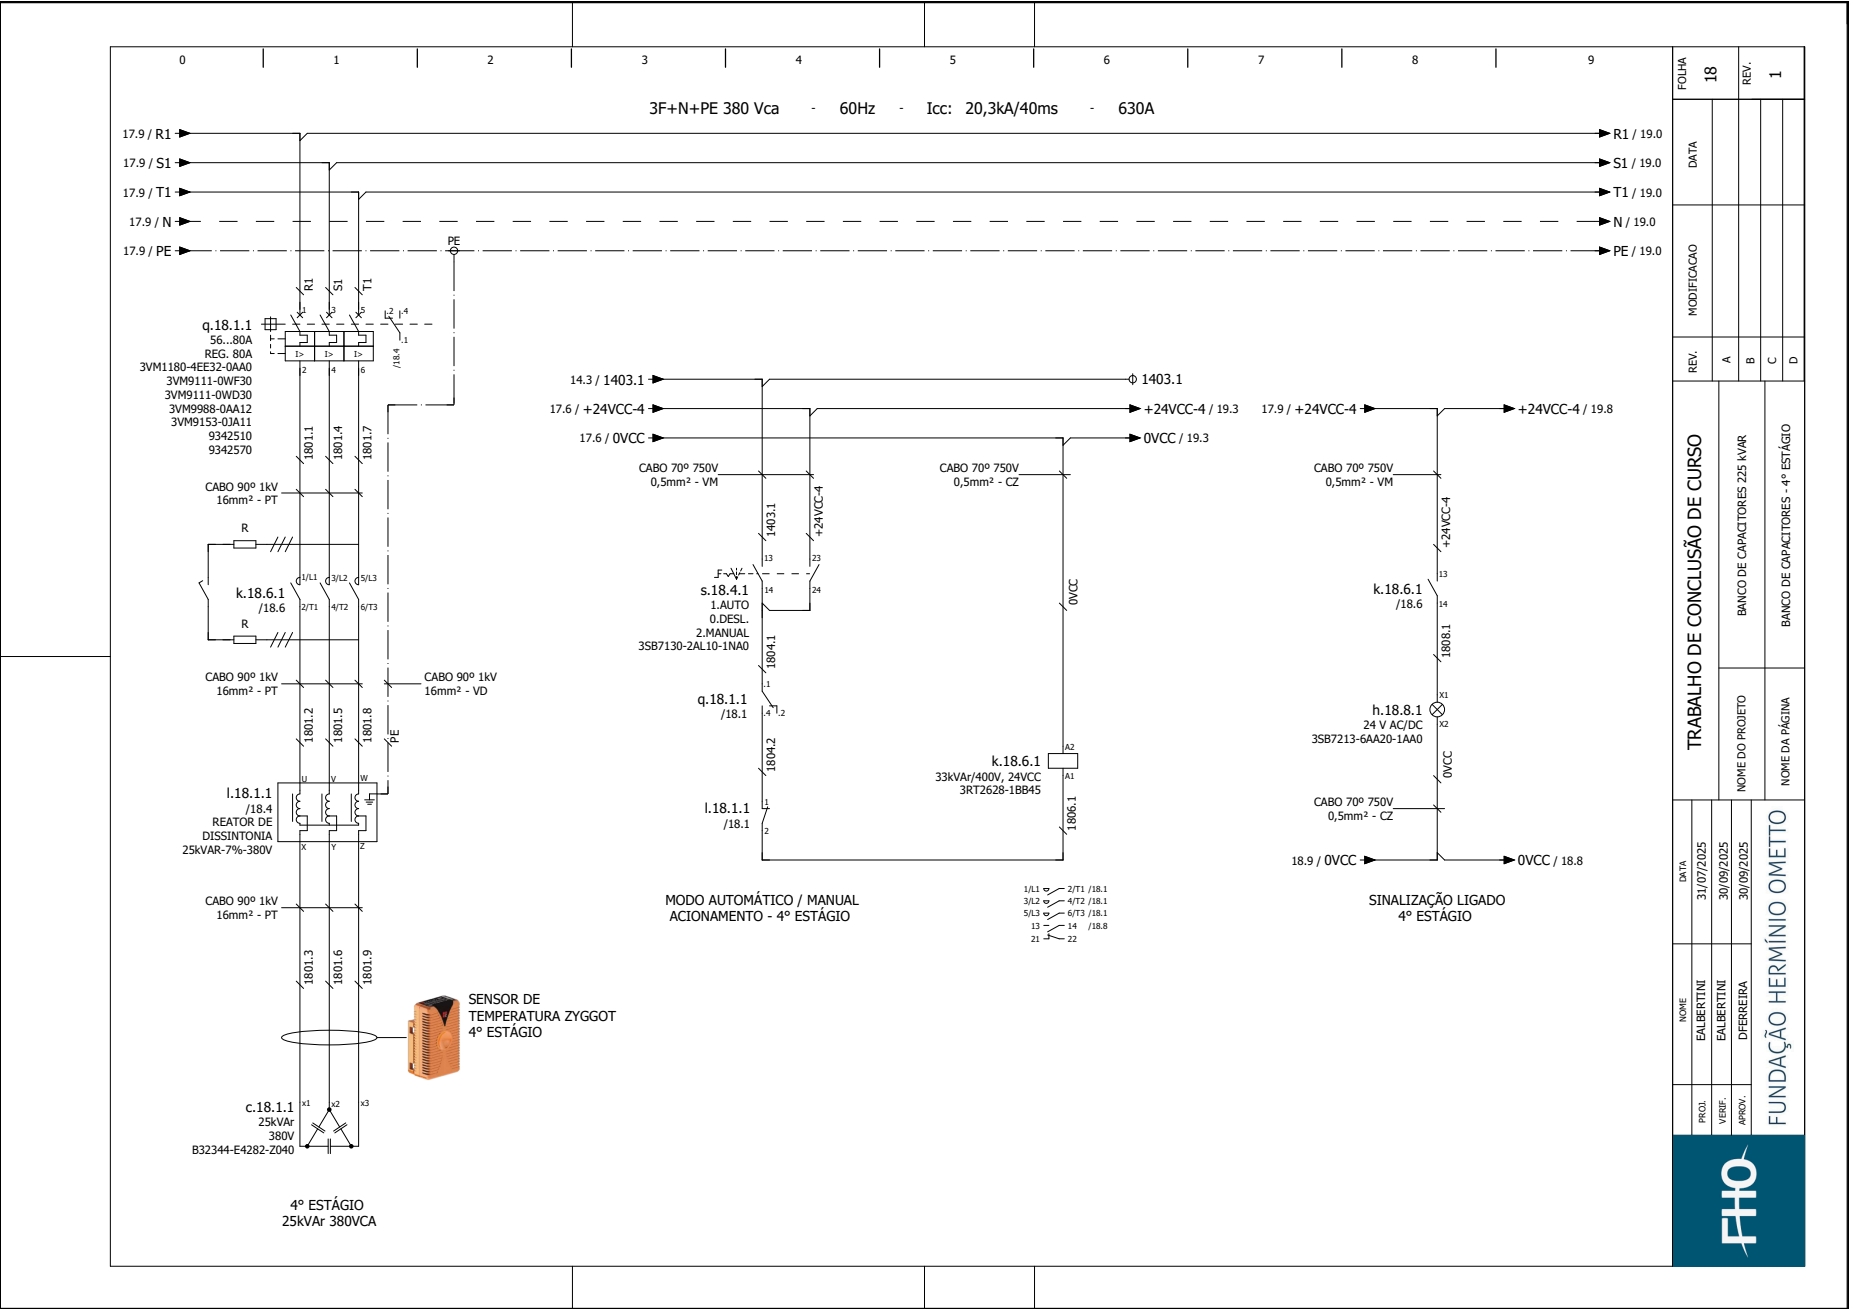
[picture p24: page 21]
EALBERTINI 31/07/2025 PROJ.; VERIF.; NOME DATA; MODIFICACAO REV.; DATA; APROV.; 30/09/2025 DFERREIRA; EALBERTINI; CABO 90º 1kV 16mm² - PT; 4° ESTÁGIO 25kVAr 380VCA; CABO 90º 1kV 16mm² - VD; SINALIZAÇÃO LIGADO 4° ESTÁGIO; SENSOR DE TEMPERATURA ZYGGOT 4° ESTÁGIO; CABO 70º 750V 0,5mm² - CZ; CABO 70º 750V 0,5mm² - VM; +24VCC-4; c.18.1.1 25kVAr 380V B32344-E4282-Z040; q.18.1.1 56...80A REG. 80A 3VM1180-4EE32-0AA0 3VM9111-0WF30 3VM9111-0WD30 3VM9988-0AA12 3VM9153-0JA11 9342510 9342570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

REV. NOME DO PROJETO

ACIONAMENTO - 4° ESTÁGIO ¹⁴⁰³.1

BANCO DE CAPACITORES - 4° ESTÁGIO

TRABALHO DE CONCLUSÃO DE CURSO

BANCO DE CAPACITORES 225 kVAR

NOME DA PÁGINA

MODO AUTOMÁTICO / MANUAL

3F+N+PE 380 Vca | - | 60Hz | - | Icc: 20,3kA/40ms | - | 630A

REV. NOME DO PROJETO

ACIONAMENTO - 5° ESTÁGIO ¹⁴⁰³.2

BANCO DE CAPACITORES - 5° ESTÁGIO

TRABALHO DE CONCLUSÃO DE CURSO

BANCO DE CAPACITORES 225 kVAR

NOME DA PÁGINA

MODO AUTOMÁTICO / MANUAL

3F+N+PE 380 Vca | - | 60Hz | - | Icc: 20,3kA/40ms | - | 630A

EALBERTINI 31/07/2025 PROJ.; VERIF.; NOME DATA; MODIFICACAO REV.; DATA; APROV.; 30/09/2025 DFERREIRA; EALBERTINI; CABO 90º 1kV 16mm² - PT; 6° ESTÁGIO 25kVAr 380VCA; CABO 90º 1kV 16mm² - VD; SINALIZAÇÃO LIGADO 6° ESTÁGIO; SENSOR DE TEMPERATURA ZYGGOT 6° ESTÁGIO; CABO 70º 750V 0,5mm² - CZ; CABO 70º 750V 0,5mm² - VM; +24VCC-4; c.20.1.1 25kVAr 380V B32344-E4282-Z040; q.20.1.1 56...80A REG. 80A 3VM1180-4EE32-0AA0 3VM9111-0WF30 3VM9111-0WD30 3VM9988-0AA12 3VM9153-0JA11 9342510 9342570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

REV. NOME DO PROJETO

ACIONAMENTO - 6° ESTÁGIO ¹⁴⁰⁴.1

BANCO DE CAPACITORES - 6° ESTÁGIO

TRABALHO DE CONCLUSÃO DE CURSO

BANCO DE CAPACITORES 225 kVAR

NOME DA PÁGINA

MODO AUTOMÁTICO / MANUAL

3F+N+PE 380 Vca | - | 60Hz | - | Icc: 20,3kA/40ms | - | 630A

EALBERTINI 31/07/2025 PROJ.; VERIF.; NOME DATA; MODIFICACAO REV.; DATA; APROV.; 30/09/2025 DFERREIRA; EALBERTINI; CABO 90º 1kV 16mm² - PT; 7° ESTÁGIO 25kVAr 380VCA; CABO 90º 1kV 16mm² - VD; SINALIZAÇÃO LIGADO 7° ESTÁGIO; SENSOR DE TEMPERATURA ZYGGOT 7° ESTÁGIO; CABO 70º 750V 0,5mm² - CZ; CABO 70º 750V 0,5mm² - VM; +24VCC-4; c.21.1.1 25kVAr 380V B32344-E4282-Z040; q.21.1.1 56...80A REG. 80A 3VM1180-4EE32-0AA0 3VM9111-0WF30 3VM9111-0WD30 3VM9988-0AA12 3VM9153-0JA11 9342510 9342570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

REV. NOME DO PROJETO

ACIONAMENTO - 7° ESTÁGIO ¹⁴⁰⁴.2

BANCO DE CAPACITORES - 7° ESTÁGIO

TRABALHO DE CONCLUSÃO DE CURSO

BANCO DE CAPACITORES 225 kVAR

NOME DA PÁGINA

MODO AUTOMÁTICO / MANUAL

3F+N+PE 380 Vca | - | 60Hz | - | Icc: 20,3kA/40ms | - | 630A

REV. NOME DO PROJETO

ACIONAMENTO - 8° ESTÁGIO ¹⁴⁰⁵.2

BANCO DE CAPACITORES - 8° ESTÁGIO

TRABALHO DE CONCLUSÃO DE CURSO

BANCO DE CAPACITORES 225 kVAR

NOME DA PÁGINA

MODO AUTOMÁTICO / MANUAL

3F+N+PE 380 Vca | - | 60Hz | - | Icc: 20,3kA/40ms | - | 630A

EALBERTINI 31/07/2025 PROJ.; VERIF.; NOME DATA; MODIFICACAO REV.; DATA; APROV.; 30/09/2025 DFERREIRA; EALBERTINI; CABO 90º 1kV 16mm² - PT; 9° ESTÁGIO 25kVAr 380VCA; CABO 90º 1kV 16mm² - VD; SINALIZAÇÃO LIGADO 9° ESTÁGIO; SENSOR DE TEMPERATURA ZYGGOT 9° ESTÁGIO; CABO 70º 750V 0,5mm² - CZ; CABO 70º 750V 0,5mm² - VM; +24VCC-4; c.23.1.1 25kVAr 380V B32344-E4282-Z040; q.23.1.1 56...80A REG. 80A 3VM1180-4EE32-0AA0 3VM9111-0WF30 3VM9111-0WD30 3VM9988-0AA12 3VM9153-0JA11 9342510 9342570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

REV. NOME DO PROJETO

ACIONAMENTO - 9° ESTÁGIO ¹⁴⁰⁶.1

BANCO DE CAPACITORES - 9° ESTÁGIO

TRABALHO DE CONCLUSÃO DE CURSO

BANCO DE CAPACITORES 225 kVAR

NOME DA PÁGINA

MODO AUTOMÁTICO / MANUAL

EALBERTINI 31/07/2025 PROJ.; VERIF.; NOME DATA; MODIFICACAO REV.; DATA; REV. NOME DO PROJETO; NOME DA PÁGINA; BANCO DE CAPACITORES 225 kVAR; APROV.; 30/09/2025 DFERREIRA; TRABALHO DE CONCLUSÃO DE CURSO; EALBERTINI; 10° ESTÁGIO - RESERVA

### BANCO DE CAPACITORES - 10° ESTÁGIO RESERVA

EALBERTINI 31/07/2025 PROJ.; VERIF.; NOME DATA; MODIFICACAO REV.; DATA; REV. NOME DO PROJETO; NOME DA PÁGINA; BANCO DE CAPACITORES 225 kVAR; APROV.; 30/09/2025 DFERREIRA; TRABALHO DE CONCLUSÃO DE CURSO; EALBERTINI; 11° ESTÁGIO - RESERVA

### BANCO DE CAPACITORES - 11° ESTÁGIO RESERVA

EALBERTINI 31/07/2025 PROJ.; VERIF.; NOME DATA; MODIFICACAO REV.; DATA; REV. NOME DO PROJETO; NOME DA PÁGINA; BANCO DE CAPACITORES 225 kVAR; APROV.; 30/09/2025 DFERREIRA; TRABALHO DE CONCLUSÃO DE CURSO; EALBERTINI; 12° ESTÁGIO - RESERVA

### BANCO DE CAPACITORES - 12° ESTÁGIO RESERVA

## LEGENDA:

600 mm | 1000 mm | 600 mm | 600 mm 9 | 10 7 | 8

REV. NOME DO PROJETO

TRABALHO DE CONCLUSÃO DE CURSO

BANCO DE CAPACITORES 225 kVAR

NOME DA PÁGINA

1

26 | 27

EALBERTINI 31/07/2025 PROJ.; VERIF.; NOME DATA; MODIFICACAO REV.; DATA; LAYOUT INTERNO; APROV.; 30/09/2025 DFERREIRA; EALBERTINI; LEGENDA:; 6-) X1; X3; X4; X5; 7-) XNB-1; XNB-2; 8-) q.7.7.2; q.8.1.1; q.9.1.1; q.10.1.1; q.11.1.1;; 13-) X0VCC; X2; 14-) x.14.7.1; 15-) q.15.1.1; q.16.1.1; 16-) q.17.1.1; q.18.1.1; q.19.1.1; 17-) q.20.1.1; q.21.1.1; q.22.1.1; 18-) q.23.1.1;; ESPAÇO RESERVA; PRATELEIRA 03; PRATELEIRA 02; PRATELEIRA 01; VISTA SUPERIOR PRATELEIRA 01; VISTA SUPERIOR PRATELEIRA 02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

REV. NOME DO PROJETO

TRABALHO DE CONCLUSÃO DE CURSO

BANCO DE CAPACITORES 225 kVAR

NOME DA PÁGINA


30/09/2025

EALBERTINI 31/07/2025 PROJ.

VERIF.

NOME DATA

MODIFICACAO REV.

A
B

DATA

C

D

## REV. NOME DO PROJETO

### NOME DA PÁGINA

BANCO DE CAPACITORES 225 kVAR

LAYOUT 3D

APROV.

30/09/2025 DFERREIRA

# TRABALHO DE CONCLUSÃO DE CURSO

EALBERTINI


30/09/2025

EALBERTINI 31/07/2025 PROJ.

VERIF.

NOME DATA

MODIFICACAO REV.

A
B

DATA

C

D

## REV. NOME DO PROJETO

### NOME DA PÁGINA

BANCO DE CAPACITORES 225 kVAR

LAYOUT 3D

APROV.

30/09/2025 DFERREIRA

# TRABALHO DE CONCLUSÃO DE CURSO

EALBERTINI


30/09/2025

EALBERTINI 31/07/2025 PROJ.

VERIF.

NOME DATA

MODIFICACAO REV.

A
B

DATA

C

D

## REV. NOME DO PROJETO

### NOME DA PÁGINA

BANCO DE CAPACITORES 225 kVAR

LAYOUT 3D

APROV.

30/09/2025 DFERREIRA

# TRABALHO DE CONCLUSÃO DE CURSO

EALBERTINI


30/09/2025

EALBERTINI 31/07/2025 PROJ.

VERIF.

NOME DATA

MODIFICACAO REV.

A
B

DATA

C

D

## REV. NOME DO PROJETO

### NOME DA PÁGINA

BANCO DE CAPACITORES 225 kVAR

LAYOUT 3D

APROV.

30/09/2025 DFERREIRA

# TRABALHO DE CONCLUSÃO DE CURSO

EALBERTINI

30/09/2025

EALBERTINI 31/07/2025 PROJ.

VERIF.

NOME DATA

MODIFICACAO REV.

A
B

DATA

C

D

## REV. NOME DO PROJETO

### NOME DA PÁGINA

BANCO DE CAPACITORES 225 kVAR

Lista de peças : ZCB/4/2U/400 - RIT.8660002

APROV.

30/09/2025 DFERREIRA

# TRABALHO DE CONCLUSÃO DE CURSO

EALBERTINI

# Lista de peças LISTA DE PEÇAS REV-C

TAG Posicionamento | QTD | CÓDIGO DA PEÇA | DESCRIÇÃO | FABRICANTE
| 1 | ZCB/4/2U/400 | CABO MINI-USB PARA INTERLIGAÇÃO DE SENSORES BT - 4M | VARIXX /12.1;/13.7
| 1 | ZCB/4/2U/100 | CABO MINI-USB PARA INTERLIGAÇÃO DE SENSORES BT - 1M | VARIXX /13.0
/13.1;/13.3 /13.5;/13.6 | 1 | ZCB/4/2U/030 | CABO MINI-USB PARA INTERLIGAÇÃO DE SENSORES BT - 0,3M | VARIXX
| 1 | ZTA | DERIVADOR EM T PARA CABOS MINI-USB DOS SENSORES BT | VARIXX /12.1
| 1 | ZFR | RESISTOR DE TERMINAÇÃO PARA SENSORES BT | VARIXX /12.0
/13.3;/13.4 /13.8 | 1 | ZCB/4/2U/200 | CABO MINI-USB PARA INTERLIGAÇÃO DE SENSORES BT - 2M | VARIXX
/13.1;/13.2 /13.4;/13.6 /13.7;/13.9 | 1 | ZCB/4/2U/050 | CABO MINI-USB PARA INTERLIGAÇÃO DE SENSORES BT - 0,5M | VARIXX
-BR.E (BC-225kVAr.S5) (BC-225kVAr.S6) (BC-225kVAr.S7) | 1 | 30x10mm | BARRAMENTO DE COBRE 30x10mm | GDRW
-BR.N (BC-225kVAr.S5) | 1 | 30x10mm | BARRAMENTO DE COBRE 30x10mm | GDRW
-BR.PE (BC-225kVAr.S5) (BC-225kVAr.S7) (BC-225kVAr.S8) | 1 | 30x10mm | BARRAMENTO DE COBRE 30x10mm | GDRW
-F1 (BC-225kVAr.S6) | 1 | 3092000 | PERFIL DE COBERTURA PARA BARRAS COLETORAS (BC-225kVAr.S5) | RITTAL
-F2 | | 9340070 | COBERTURA DE ACABAMENTO PARA PROTEÇÃO LATERAL (BC-225kVAr.S6) | RITTAL 1
-SB | | 3092000 | PERFIL DE COBERTURA PARA BARRAS COLETORAS (BC-225kVAr.S5) | RITTAL 1
-SB | | RIT.9340010 | SUPORTE DE BARRAMENTO 3 POLOS RILINE 60 (BC-225kVAr.S5) | RITTAL 1
-SB | | 9340070 | COBERTURA DE ACABAMENTO PARA PROTEÇÃO LATERAL (BC-225kVAr.S5) | RITTAL 2
-U1 (BC-225kVAr.S7) (BC-225kVAr.S8) | 1 | RIT.8606500 | ARMARIO TS 600x2000x600mm RAL 7035 (BC-225kVAr.S5) | RITTAL
-U1 | | RIT.8006500 | ARMARIO TS 1000x2000x600mm RAL 7035 (BC-225kVAr.S6) | RITTAL 1
-U1 (BC-225kVAr.S5) (BC-225kVAr.S7) (BC-225kVAr.S8) | 1 | RIT.TS_Base_100_600x600 | BASE SOLEIRA COMPLETA - 100mm - 600x600mm | RITTAL
-U1 (BC-225kVAr.S7) (BC-225kVAr.S8) | 1 | RIT.8660002 | ELEMENTO PARA BASE SOLEIRA FRONT. E TRAS. P/TS 600 - 100mm DE ALTURA (BC-225kVAr.S5) | RITTAL

30/09/2025

EALBERTINI 31/07/2025 PROJ.

VERIF.

NOME DATA

MODIFICACAO REV.

A
B

DATA

C

D

## REV. NOME DO PROJETO

### NOME DA PÁGINA

BANCO DE CAPACITORES 225 kVAR

Lista de peças : RIT.8660033 - 30x10mm

APROV.

33.a

30/09/2025 DFERREIRA

# TRABALHO DE CONCLUSÃO DE CURSO

EALBERTINI

# Lista de peças LISTA DE PEÇAS REV-C

TAG Posicionamento | QTD | CÓDIGO DA PEÇA | DESCRIÇÃO | FABRICANTE
-U1 (BC-225kVAr.S6) (BC-225kVAr.S7) (BC-225kVAr.S8) | 1 | RIT.8660033 | ACABAMENTO LATERAL PARA BASE SOLEIRA VX - 100mm DE ALTURA (BC-225kVAr.S5) | RITTAL
-U1 (BC-225kVAr.S6) | | RIT.TS_Base_100_1000x600 | BASE SOLEIRA COMPLETA - 100mm - 1000x600mm | RITTAL 1
-U1 | | RIT.8660005 | ELEMENTO PARA BASE SOLEIRA FRONT. E TRAS. P/TS 1000 - 100mm DE ALTURA (BC-225kVAr.S6) | RITTAL 1
-U1 (BC-225kVAr.S5) (BC-225kVAr.S6) (BC-225kVAr.S7) | 1 | RIT.4591700 | PLACA DE MONTAGEM INTERMEDIARIA 2000mm | RITTAL
-U1 (BC-225kVAr.S6) | 1 | RIT.4540000 | CANTONEIRA COMBINADA (BC-225kVAr.S5) | RITTAL
-U1 (BC-225kVAr.S6) (BC-225kVAr.S7) | 1 | RIT.8611290 | FECHO COMFORT PARA CADEADO | RITTAL
-U1 (BC-225kVAr.S7) | 1 | RIT.8611190 | BOTÃO PULSANDOR PARA FECHO COMFORT (BC-225kVAr.S6) | RITTAL
-U1 (BC-225kVAr.S5) (BC-225kVAr.S6) (BC-225kVAr.S7) (BC-225kVAr.S8) | 1 | TITULO | PLAQUETA DE TÍTULO PARA PAINEL ELÉTRICO | ZTK
-U1 | | RIT.3079000 | SUPORTE UNIVERSAL PARA BARRAMENTO FLEXÍVEL (BC-225kVAr.S5) | RITTAL 1
-U1 (BC-225kVAr.S5) (BC-225kVAr.S8) | 1 | RIT.8106235 | FECHAMENTO LATERIAL 600mm | RITTAL
-U1 (BC-225kVAr.S6) | 1 | RIT.9340010 | SUPORTE DE BARRAMENTO 3 POLOS RILINE 60 (BC-225kVAr.S5) | RITTAL
-U1 | | RIT.7466035 (BC-225kVAr.S8) | PRATELEIRA PARA FIXAÇÃO NO QUADRO | RIT 1
-W14 | | RIT.3574005 | BARRAS LAMINADAS EM COBRE 10x32x1MM 965A (BC-225kVAr.S5) | RITTAL 1
-W15 | | RIT.3574005 | BARRAS LAMINADAS EM COBRE 10x32x1MM 965A (BC-225kVAr.S5) | RITTAL 1
-W16 | | RIT.3574005 | BARRAS LAMINADAS EM COBRE 10x32x1MM 965A (BC-225kVAr.S5) | RITTAL 1
-W17 (BC-225kVAr.S5) | 1 | 30x10mm | BARRAMENTO DE COBRE 30x10mm | GDRW
-W18 (BC-225kVAr.S5) | 1 | 30x10mm | BARRAMENTO DE COBRE 30x10mm | GDRW
-W19 (BC-225kVAr.S5) | 1 | 30x10mm | BARRAMENTO DE COBRE 30x10mm | GDRW

30/09/2025

EALBERTINI 31/07/2025 PROJ.

VERIF.

NOME DATA

MODIFICACAO REV.

A
B

DATA

C

D

## REV. NOME DO PROJETO

### NOME DA PÁGINA

BANCO DE CAPACITORES 225 kVAR

Lista de peças : B32344-E4282-Z040 - 3RT2628-1BB45

APROV.

33.b

30/09/2025 DFERREIRA

# TRABALHO DE CONCLUSÃO DE CURSO

EALBERTINI

# Lista de peças LISTA DE PEÇAS REV-C

TAG Posicionamento | QTD | CÓDIGO DA PEÇA | DESCRIÇÃO | FABRICANTE
-c.15.1.1 | 1 | B32344-E4282-Z040 | CÉLULA CAPACITIVA DE 33,7kVAR EM 440V | SIEMENS /15.1
-c.16.1.1 | 1 | B32344-E4282-Z040 | CÉLULA CAPACITIVA DE 33,7kVAR EM 440V | SIEMENS /16.1
-c.17.1.1 | 1 | B32344-E4282-Z040 | CÉLULA CAPACITIVA DE 33,7kVAR EM 440V | SIEMENS /17.1
-c.18.1.1 | 1 | B32344-E4282-Z040 | CÉLULA CAPACITIVA DE 33,7kVAR EM 440V | SIEMENS /18.1
-c.19.1.1 | 1 | B32344-E4282-Z040 | CÉLULA CAPACITIVA DE 33,7kVAR EM 440V | SIEMENS /19.1
-c.20.1.1 | 1 | B32344-E4282-Z040 | CÉLULA CAPACITIVA DE 33,7kVAR EM 440V | SIEMENS /20.1
-c.21.1.1 | 1 | B32344-E4282-Z040 | CÉLULA CAPACITIVA DE 33,7kVAR EM 440V | SIEMENS /21.1
-c.22.1.1 | 1 | B32344-E4282-Z040 | CÉLULA CAPACITIVA DE 33,7kVAR EM 440V | SIEMENS /22.1
-c.23.1.1 | 1 | B32344-E4282-Z040 | CÉLULA CAPACITIVA DE 33,7kVAR EM 440V | SIEMENS /23.1
-e.8.1.1 | 1 | 2500100 | LUMINARIA LED 400 100-240V 50/60HZ | RITTAL /08.1
-e.8.3.2 | 1 | 2500100 | LUMINARIA LED 400 100-240V 50/60HZ | RITTAL /08.3
-e.8.5.3 | 1 | 2500100 | LUMINARIA LED 400 100-240V 50/60HZ | RITTAL /08.5
-f.6.0.1 | 1 | 952405 | DPS CLASSE II - DG M TNS 275 FM | DEHN /06.1
-g.11.1.1 | 1 | 787-732 | FONTE CHAVEADA EPSITRON® ECO Power - 24VCC -10A | WAGO /11.1
-h.5.4.1 | 1 | 3SB7213-6AA20-1AA0 | SINALEIRO MONOBLOCO VERMELHO - 24V CA/CC | SIEMENS /05.4
-h.5.5.2 | 1 | 3SB7213-6AA40-1AA0 | SINALEIRO MONOBLOCO VERDE - 24V CA/CC | SIEMENS /05.5
-h.5.6.3 | 1 | 3SB7213-6AA30-1AA0 | SINALEIRO MONOBLOCO AMARELO - 24V CA/CC | SIEMENS /05.7
-h.6.5.1 | 1 | 3SB7213-6AA60-1AA0 | SINALEIRO MONOBLOCO BRANCO - 24V CA/CC | SIEMENS /06.5
-h.15.8.1 | 1 | 3SB7213-6AA20-1AA0 | SINALEIRO MONOBLOCO VERMELHO - 24V CA/CC | SIEMENS /15.8
-h.16.8.1 | 1 | 3SB7213-6AA20-1AA0 | SINALEIRO MONOBLOCO VERMELHO - 24V CA/CC | SIEMENS /16.8
-h.17.8.1 | 1 | 3SB7213-6AA20-1AA0 | SINALEIRO MONOBLOCO VERMELHO - 24V CA/CC | SIEMENS /17.8
-h.18.8.1 | 1 | 3SB7213-6AA20-1AA0 | SINALEIRO MONOBLOCO VERMELHO - 24V CA/CC | SIEMENS /18.8
-h.19.8.1 | 1 | 3SB7213-6AA20-1AA0 | SINALEIRO MONOBLOCO VERMELHO - 24V CA/CC | SIEMENS /19.8
-h.20.8.1 | 1 | 3SB7213-6AA20-1AA0 | SINALEIRO MONOBLOCO VERMELHO - 24V CA/CC | SIEMENS /20.8
-h.21.8.1 | 1 | 3SB7213-6AA20-1AA0 | SINALEIRO MONOBLOCO VERMELHO - 24V CA/CC | SIEMENS /21.8
-h.22.8.1 | 1 | 3SB7213-6AA20-1AA0 | SINALEIRO MONOBLOCO VERMELHO - 24V CA/CC | SIEMENS /22.8
-h.23.8.1 | 1 | 3SB7213-6AA20-1AA0 | SINALEIRO MONOBLOCO VERMELHO - 24V CA/CC | SIEMENS /23.8
-k.15.6.1 /15.6 | 1 | 3RT2628-1BB45 | CONTATOR PARA CAPACITOR 33kVAR EM 380V - 24VCC | SIEMENS

30/09/2025

EALBERTINI 31/07/2025 PROJ.

VERIF.

NOME DATA

MODIFICACAO REV.

A
B

DATA

C

D

## REV. NOME DO PROJETO

### NOME DA PÁGINA

BANCO DE CAPACITORES 225 kVAR
Lista de peças : 3RT2628-1BB45 -

3VA1580-5EF32-0AA0

APROV.

33.c

30/09/2025 DFERREIRA

# TRABALHO DE CONCLUSÃO DE CURSO

EALBERTINI

# Lista de peças LISTA DE PEÇAS REV-C

TAG Posicionamento | QTD | CÓDIGO DA PEÇA | DESCRIÇÃO | FABRICANTE
-k.16.6.1 /16.6 | 1 | 3RT2628-1BB45 | CONTATOR PARA CAPACITOR 33kVAR EM 380V - 24VCC | SIEMENS
-k.17.6.1 /17.6 | 1 | 3RT2628-1BB45 | CONTATOR PARA CAPACITOR 33kVAR EM 380V - 24VCC | SIEMENS
-k.18.6.1 /18.6 | 1 | 3RT2628-1BB45 | CONTATOR PARA CAPACITOR 33kVAR EM 380V - 24VCC | SIEMENS
-k.19.6.1 /19.6 | 1 | 3RT2628-1BB45 | CONTATOR PARA CAPACITOR 33kVAR EM 380V - 24VCC | SIEMENS
-k.20.6.1 /20.6 | 1 | 3RT2628-1BB45 | CONTATOR PARA CAPACITOR 33kVAR EM 380V - 24VCC | SIEMENS
-k.21.6.1 /21.6 | 1 | 3RT2628-1BB45 | CONTATOR PARA CAPACITOR 33kVAR EM 380V - 24VCC | SIEMENS
-k.22.6.1 /22.6 | 1 | 3RT2628-1BB45 | CONTATOR PARA CAPACITOR 33kVAR EM 380V - 24VCC | SIEMENS
-k.23.6.1 /23.6 | 1 | 3RT2628-1BB45 | CONTATOR PARA CAPACITOR 33kVAR EM 380V - 24VCC | SIEMENS
-l.15.1.1 /15.1 | 1 | 25kVAR-7%-380V | REATOR DE DESSINTONIA 25kVAR - 7% - 380V | COSMO
-l.16.1.1 /16.1 | 1 | 25kVAR-7%-380V | REATOR DE DESSINTONIA 25kVAR - 7% - 380V | COSMO
-l.17.1.1 /17.1 | 1 | 25kVAR-7%-380V | REATOR DE DESSINTONIA 25kVAR - 7% - 380V | COSMO
-l.18.1.1 /18.1 | 1 | 25kVAR-7%-380V | REATOR DE DESSINTONIA 25kVAR - 7% - 380V | COSMO
-l.19.1.1 /19.1 | 1 | 25kVAR-7%-380V | REATOR DE DESSINTONIA 25kVAR - 7% - 380V | COSMO
-l.20.1.1 /20.1 | 1 | 25kVAR-7%-380V | REATOR DE DESSINTONIA 25kVAR - 7% - 380V | COSMO
-l.21.1.1 /21.1 | 1 | 25kVAR-7%-380V | REATOR DE DESSINTONIA 25kVAR - 7% - 380V | COSMO
-l.22.1.1 /22.1 | 1 | 25kVAR-7%-380V | REATOR DE DESSINTONIA 25kVAR - 7% - 380V | COSMO
-l.23.1.1 /23.1 | 1 | 25kVAR-7%-380V | REATOR DE DESSINTONIA 25kVAR - 7% - 380V | COSMO
-m.9.2.1 /09.2 | 1 | 3243700 | VENTILADOR COM FILTRO BLUE E+ 625/716m³/H 230V RAL7035 | RITTAL
-m.9.2.1 /09.2 | 1 | 3243300 | FILTRO DE SAÍDA 323X323mm RAL7035 | RITTAL
-m.9.4.2 /09.4 | 1 | 3243700 | VENTILADOR COM FILTRO BLUE E+ 625/716m³/H 230V RAL7035 | RITTAL
-m.9.4.2 /09.4 | 1 | 3243300 | FILTRO DE SAÍDA 323X323mm RAL7035 | RITTAL
-m.9.6.3 | 1 | 3139100 | VENTILADOR DE TETO SEM FILTRO 360/373m³/H 230V RAL7035 | RITTAL /09.6
-m.9.6.3 /09.6 | 1 | 3243300 | FILTRO DE SAÍDA 323X323mm RAL7035 | RITTAL
-m.9.6.3 | 1 | 3173120 | ELEMENTO PLISSADO IP54 PARA SK3243 3244 3245 | RITTAL /09.6
-m.9.7.4 | 1 | 3139100 | VENTILADOR DE TETO SEM FILTRO 360/373m³/H 230V RAL7035 | RITTAL /09.7
-m.9.7.4 /09.7 | 1 | 3243300 | FILTRO DE SAÍDA 323X323mm RAL7035 | RITTAL
-m.9.7.4 | 1 | 3173120 | ELEMENTO PLISSADO IP54 PARA SK3243 3244 3245 | RITTAL /09.7
-q.5.0.1 | 1 | 3VA1580-5EF32-0AA0 | DISJUNTOR CAIXA MOLDADA 3VA15 55kA 380V - 560...800A | SIEMENS /05.1

30/09/2025

EALBERTINI 31/07/2025 PROJ.

VERIF.

NOME DATA

MODIFICACAO REV.

A
B

DATA

C

D

## REV. NOME DO PROJETO

### NOME DA PÁGINA

BANCO DE CAPACITORES 225 kVAR

Lista de peças : 3VA9687-0FK21 - 3VM9111-0WF30

APROV.

33.d

30/09/2025 DFERREIRA

# TRABALHO DE CONCLUSÃO DE CURSO

EALBERTINI

# Lista de peças LISTA DE PEÇAS REV-C

TAG Posicionamento | QTD | CÓDIGO DA PEÇA | DESCRIÇÃO | FABRICANTE
-q.5.0.1 | 1 | 3VA9687-0FK21 | ACESSÓRIO PARA 3VA15/25 - ACIONAMENTO ROTATIVO EXTERNO COMPLETO | SIEMENS /05.1
-q.5.0.1 | 1 | 3VA9601-0WF30 | ACESSÓRIO PARA 3VA - COBERTURA ESTENDIDA PARA BORNE (3VA15/25) | SIEMENS /05.1
-q.5.0.1 | 1 | 3VA9603-0QB00 | ACESSÓRIO 3VA15/25 - BARRA DE CONEXÃO FRONTAL COM SEPARADOR DE FASE - 3 POLOS - (50MM X 28MM) | SIEMENS /05.1
-q.5.0.1 | 1 | 3VA9988-0AA12 | BLOCO DE CONTATO AUXILIAR 1NAF PARA DISJUNTOR 3VA | SIEMENS /05.1
-q.5.0.1 | 1 | 3VA9988-0AB12 | BLOCO DE CONTATO ALARME TAS PARA DISJUNTOR 3VA | SIEMENS /05.1
-q.6.1.1 | 1 | 3VM1112-5ED32-0AA0 | DISJUNTOR CAIXA MOLDADA 3VM11 55kA 380V - 125A | SIEMENS /06.1
-q.6.1.1 | 1 | 3VM9153-0JA11 | ACESSÓRIO PARA 3VM - BORNE DE CONEXÃO PARA CABOS 1,5 - 70mm² | SIEMENS /06.1
-q.6.1.1 | 2 | 3VM9111-0WF30 | ACESSÓRIO PARA 3VM - COBERTURA ESTENDIDA PARA BORNE (3VM11) | SIEMENS /06.1
-q.6.1.1 | 1 | 3VM9988-0AA12 | BLOCO DE CONTATO AUXILIAR 6A 1NAF PARA DISJUNTOR 3VM | SIEMENS /06.1
-q.7.1.1 | 1 | 3VA1140-5ED32-0AA0 | DISJUNTOR CAIXA MOLDADA 40A 55kA | SIEMENS /07.1
-q.7.1.1 | 1 | 3VA9153-0JA11 | ACESSÓRIO PARA 3VA - BORNE DE CONEXÃO PARA CABOS 1,5 - 70mm² | SIEMENS /07.1
-q.7.1.1 | 1 | 3VA9111-0WD30 | ACESSÓRIO PARA 3VA - COBERTURA PADRÃO PARA BORNE (3VA1-100A e 160A) | SIEMENS /07.1
-q.7.1.1 | 1 | 3VA9111-0WF30 | ACESSÓRIO PARA 3VA - COBERTURA ESTENDIDA PARA BORNE (3VA1-100A e 160A) | SIEMENS /07.1
-q.7.1.1 | 1 | 9342510 | ADAPTADOR DE APARELHOS 160A/90mm - 690V SAÍDA DE CABOS P/BAIXO | RITTAL /07.1
-q.7.1.1 | 1 | 9342570 | CONTONEIRA DE CONEXÃO PARA ADAPTADOR DE 160A | RITTAL /07.1
-q.7.7.2 | 1 | 5SY4125-7 | MINI DISJUNTOR 1P CURVA C 25A | SIEMENS /07.8
-q.8.1.1 | 1 | 5SY4102-7 | MINI DISJUNTOR 1P CURVA C 2A | SIEMENS /08.1
-q.8.1.1 | 1 | 5ST3708-0MB | BARRAMENTO DE ALIMENTAÇÃO TRIFÁSICO 80/130A PARA MINI DISJUNTOR | SIEMENS /08.1
-q.9.1.1 | 1 | 5SY4106-7 | MINI DISJUNTOR 1P CURVA C 6A | SIEMENS /09.1
-q.10.1.1 | 1 | 5SY4104-7 | MINI DISJUNTOR 1P CURVA C 4A | SIEMENS /10.1
-q.11.1.1 | 1 | 5SY4110-7 | MINI DISJUNTOR 1P CURVA C 10A | SIEMENS /11.1
-q.11.2.2 | 1 | 5SL1102-7 | MINI DISJUNTOR 1P CURVA C 2A | SIEMENS /11.2
-q.11.2.2 | 1 | 5ST3730-0MB | BARRAMENTO DE ALIMENTAÇÃO MONOFÁSICO 63/80A PARA MINI DISJUNTOR | SIEMENS /11.2
-q.11.3.3 | 1 | 5SL1102-7 | MINI DISJUNTOR 1P CURVA C 2A | SIEMENS /11.3
-q.11.3.4 | 1 | 5SL1102-7 | MINI DISJUNTOR 1P CURVA C 2A | SIEMENS /11.4
-q.11.4.5 | 1 | 5SL1104-7 | MINI DISJUNTOR 1P CURVA C 4A | SIEMENS /11.4
-q.15.1.1 | 1 | 3VM1180-4EE32-0AA0 | DISJUNTOR CAIXA MOLDADA 3VM11 36kA 380V - 56...80A | SIEMENS /15.1
-q.15.1.1 | 1 | 3VM9111-0WF30 | ACESSÓRIO PARA 3VM - COBERTURA ESTENDIDA PARA BORNE (3VM11) | SIEMENS /15.1

30/09/2025

EALBERTINI 31/07/2025 PROJ.

VERIF.

NOME DATA

MODIFICACAO REV.

A
B

DATA

C

D

## REV. NOME DO PROJETO

### NOME DA PÁGINA

BANCO DE CAPACITORES 225 kVAR

Lista de peças : 3VM9111-0WD30 - 3VM9111-0WF30

APROV.

33.e

30/09/2025 DFERREIRA

# TRABALHO DE CONCLUSÃO DE CURSO

EALBERTINI

# Lista de peças LISTA DE PEÇAS REV-C

TAG Posicionamento | QTD | CÓDIGO DA PEÇA | DESCRIÇÃO | FABRICANTE
-q.15.1.1 | 1 | 3VM9111-0WD30 | ACESSÓRIO PARA 3VM - COBERTURA PADRÃO PARA BORNE (3VM11) | SIEMENS /15.1
-q.15.1.1 | 1 | 3VM9988-0AA12 | BLOCO DE CONTATO AUXILIAR 6A 1NAF PARA DISJUNTOR 3VM | SIEMENS /15.1
-q.15.1.1 | 1 | 3VM9153-0JA11 | ACESSÓRIO PARA 3VM - BORNE DE CONEXÃO PARA CABOS 1,5 - 70mm² | SIEMENS /15.1
-q.15.1.1 | 1 | 9342510 | ADAPTADOR DE APARELHOS 160A/90mm - 690V SAÍDA DE CABOS P/BAIXO | RITTAL /15.1
-q.15.1.1 | 1 | 9342570 | CONTONEIRA DE CONEXÃO PARA ADAPTADOR DE 160A | RITTAL /15.1
-q.16.1.1 | 1 | 3VM1180-4EE32-0AA0 | DISJUNTOR CAIXA MOLDADA 3VM11 36kA 380V - 56...80A | SIEMENS /16.1
-q.16.1.1 | 1 | 3VM9111-0WF30 | ACESSÓRIO PARA 3VM - COBERTURA ESTENDIDA PARA BORNE (3VM11) | SIEMENS /16.1
-q.16.1.1 | 1 | 3VM9111-0WD30 | ACESSÓRIO PARA 3VM - COBERTURA PADRÃO PARA BORNE (3VM11) | SIEMENS /16.1
-q.16.1.1 | 1 | 3VM9988-0AA12 | BLOCO DE CONTATO AUXILIAR 6A 1NAF PARA DISJUNTOR 3VM | SIEMENS /16.1
-q.16.1.1 | 1 | 3VM9153-0JA11 | ACESSÓRIO PARA 3VM - BORNE DE CONEXÃO PARA CABOS 1,5 - 70mm² | SIEMENS /16.1
-q.16.1.1 | 1 | 9342510 | ADAPTADOR DE APARELHOS 160A/90mm - 690V SAÍDA DE CABOS P/BAIXO | RITTAL /16.1
-q.16.1.1 | 1 | 9342570 | CONTONEIRA DE CONEXÃO PARA ADAPTADOR DE 160A | RITTAL /16.1
-q.17.1.1 | 1 | 3VM1180-4EE32-0AA0 | DISJUNTOR CAIXA MOLDADA 3VM11 36kA 380V - 56...80A | SIEMENS /17.1
-q.17.1.1 | 1 | 3VM9111-0WF30 | ACESSÓRIO PARA 3VM - COBERTURA ESTENDIDA PARA BORNE (3VM11) | SIEMENS /17.1
-q.17.1.1 | 1 | 3VM9111-0WD30 | ACESSÓRIO PARA 3VM - COBERTURA PADRÃO PARA BORNE (3VM11) | SIEMENS /17.1
-q.17.1.1 | 1 | 3VM9988-0AA12 | BLOCO DE CONTATO AUXILIAR 6A 1NAF PARA DISJUNTOR 3VM | SIEMENS /17.1
-q.17.1.1 | 1 | 3VM9153-0JA11 | ACESSÓRIO PARA 3VM - BORNE DE CONEXÃO PARA CABOS 1,5 - 70mm² | SIEMENS /17.1
-q.17.1.1 | 1 | 9342510 | ADAPTADOR DE APARELHOS 160A/90mm - 690V SAÍDA DE CABOS P/BAIXO | RITTAL /17.1
-q.17.1.1 | 1 | 9342570 | CONTONEIRA DE CONEXÃO PARA ADAPTADOR DE 160A | RITTAL /17.1
-q.18.1.1 | 1 | 3VM1180-4EE32-0AA0 | DISJUNTOR CAIXA MOLDADA 3VM11 36kA 380V - 56...80A | SIEMENS /18.1
-q.18.1.1 | 1 | 3VM9111-0WF30 | ACESSÓRIO PARA 3VM - COBERTURA ESTENDIDA PARA BORNE (3VM11) | SIEMENS /18.1
-q.18.1.1 | 1 | 3VM9111-0WD30 | ACESSÓRIO PARA 3VM - COBERTURA PADRÃO PARA BORNE (3VM11) | SIEMENS /18.1
-q.18.1.1 | 1 | 3VM9988-0AA12 | BLOCO DE CONTATO AUXILIAR 6A 1NAF PARA DISJUNTOR 3VM | SIEMENS /18.1
-q.18.1.1 | 1 | 3VM9153-0JA11 | ACESSÓRIO PARA 3VM - BORNE DE CONEXÃO PARA CABOS 1,5 - 70mm² | SIEMENS /18.1
-q.18.1.1 | 1 | 9342510 | ADAPTADOR DE APARELHOS 160A/90mm - 690V SAÍDA DE CABOS P/BAIXO | RITTAL /18.1
-q.18.1.1 | 1 | 9342570 | CONTONEIRA DE CONEXÃO PARA ADAPTADOR DE 160A | RITTAL /18.1
-q.19.1.1 | 1 | 3VM1180-4EE32-0AA0 | DISJUNTOR CAIXA MOLDADA 3VM11 36kA 380V - 56...80A | SIEMENS /19.1
-q.19.1.1 | 1 | 3VM9111-0WF30 | ACESSÓRIO PARA 3VM - COBERTURA ESTENDIDA PARA BORNE (3VM11) | SIEMENS /19.1

30/09/2025

EALBERTINI 31/07/2025 PROJ.

VERIF.

NOME DATA

MODIFICACAO REV.

A
B

DATA

C

D

## REV. NOME DO PROJETO

### NOME DA PÁGINA

BANCO DE CAPACITORES 225 kVAR

Lista de peças : 3VM9111-0WD30 - 3VM9111-0WF30

APROV.

33.f

30/09/2025 DFERREIRA

# TRABALHO DE CONCLUSÃO DE CURSO

EALBERTINI

# Lista de peças LISTA DE PEÇAS REV-C

TAG Posicionamento | QTD | CÓDIGO DA PEÇA | DESCRIÇÃO | FABRICANTE
-q.19.1.1 | 1 | 3VM9111-0WD30 | ACESSÓRIO PARA 3VM - COBERTURA PADRÃO PARA BORNE (3VM11) | SIEMENS /19.1
-q.19.1.1 | 1 | 3VM9988-0AA12 | BLOCO DE CONTATO AUXILIAR 6A 1NAF PARA DISJUNTOR 3VM | SIEMENS /19.1
-q.19.1.1 | 1 | 3VM9153-0JA11 | ACESSÓRIO PARA 3VM - BORNE DE CONEXÃO PARA CABOS 1,5 - 70mm² | SIEMENS /19.1
-q.19.1.1 | 1 | 9342510 | ADAPTADOR DE APARELHOS 160A/90mm - 690V SAÍDA DE CABOS P/BAIXO | RITTAL /19.1
-q.19.1.1 | 1 | 9342570 | CONTONEIRA DE CONEXÃO PARA ADAPTADOR DE 160A | RITTAL /19.1
-q.20.1.1 | 1 | 3VM1180-4EE32-0AA0 | DISJUNTOR CAIXA MOLDADA 3VM11 36kA 380V - 56...80A | SIEMENS /20.1
-q.20.1.1 | 1 | 3VM9111-0WF30 | ACESSÓRIO PARA 3VM - COBERTURA ESTENDIDA PARA BORNE (3VM11) | SIEMENS /20.1
-q.20.1.1 | 1 | 3VM9111-0WD30 | ACESSÓRIO PARA 3VM - COBERTURA PADRÃO PARA BORNE (3VM11) | SIEMENS /20.1
-q.20.1.1 | 1 | 3VM9988-0AA12 | BLOCO DE CONTATO AUXILIAR 6A 1NAF PARA DISJUNTOR 3VM | SIEMENS /20.1
-q.20.1.1 | 1 | 3VM9153-0JA11 | ACESSÓRIO PARA 3VM - BORNE DE CONEXÃO PARA CABOS 1,5 - 70mm² | SIEMENS /20.1
-q.20.1.1 | 1 | 9342510 | ADAPTADOR DE APARELHOS 160A/90mm - 690V SAÍDA DE CABOS P/BAIXO | RITTAL /20.1
-q.20.1.1 | 1 | 9342570 | CONTONEIRA DE CONEXÃO PARA ADAPTADOR DE 160A | RITTAL /20.1
-q.21.1.1 | 1 | 3VM1180-4EE32-0AA0 | DISJUNTOR CAIXA MOLDADA 3VM11 36kA 380V - 56...80A | SIEMENS /21.1
-q.21.1.1 | 1 | 3VM9111-0WF30 | ACESSÓRIO PARA 3VM - COBERTURA ESTENDIDA PARA BORNE (3VM11) | SIEMENS /21.1
-q.21.1.1 | 1 | 3VM9111-0WD30 | ACESSÓRIO PARA 3VM - COBERTURA PADRÃO PARA BORNE (3VM11) | SIEMENS /21.1
-q.21.1.1 | 1 | 3VM9988-0AA12 | BLOCO DE CONTATO AUXILIAR 6A 1NAF PARA DISJUNTOR 3VM | SIEMENS /21.1
-q.21.1.1 | 1 | 3VM9153-0JA11 | ACESSÓRIO PARA 3VM - BORNE DE CONEXÃO PARA CABOS 1,5 - 70mm² | SIEMENS /21.1
-q.21.1.1 | 1 | 9342510 | ADAPTADOR DE APARELHOS 160A/90mm - 690V SAÍDA DE CABOS P/BAIXO | RITTAL /21.1
-q.21.1.1 | 1 | 9342570 | CONTONEIRA DE CONEXÃO PARA ADAPTADOR DE 160A | RITTAL /21.1
-q.22.1.1 | 1 | 3VM1180-4EE32-0AA0 | DISJUNTOR CAIXA MOLDADA 3VM11 36kA 380V - 56...80A | SIEMENS /22.1
-q.22.1.1 | 1 | 3VM9111-0WF30 | ACESSÓRIO PARA 3VM - COBERTURA ESTENDIDA PARA BORNE (3VM11) | SIEMENS /22.1
-q.22.1.1 | 1 | 3VM9111-0WD30 | ACESSÓRIO PARA 3VM - COBERTURA PADRÃO PARA BORNE (3VM11) | SIEMENS /22.1
-q.22.1.1 | 1 | 3VM9988-0AA12 | BLOCO DE CONTATO AUXILIAR 6A 1NAF PARA DISJUNTOR 3VM | SIEMENS /22.1
-q.22.1.1 | 1 | 3VM9153-0JA11 | ACESSÓRIO PARA 3VM - BORNE DE CONEXÃO PARA CABOS 1,5 - 70mm² | SIEMENS /22.1
-q.22.1.1 | 1 | 9342510 | ADAPTADOR DE APARELHOS 160A/90mm - 690V SAÍDA DE CABOS P/BAIXO | RITTAL /22.1
-q.22.1.1 | 1 | 9342570 | CONTONEIRA DE CONEXÃO PARA ADAPTADOR DE 160A | RITTAL /22.1
-q.23.1.1 | 1 | 3VM1180-4EE32-0AA0 | DISJUNTOR CAIXA MOLDADA 3VM11 36kA 380V - 56...80A | SIEMENS /23.1
-q.23.1.1 | 1 | 3VM9111-0WF30 | ACESSÓRIO PARA 3VM - COBERTURA ESTENDIDA PARA BORNE (3VM11) | SIEMENS /23.1

30/09/2025

EALBERTINI 31/07/2025 PROJ.

VERIF.

NOME DATA

MODIFICACAO REV.

A
B

DATA

C

D

## REV. NOME DO PROJETO

### NOME DA PÁGINA

BANCO DE CAPACITORES 225 kVAR

Lista de peças : 3VM9111-0WD30 - ZFI

APROV.

33.g

30/09/2025 DFERREIRA

# TRABALHO DE CONCLUSÃO DE CURSO

EALBERTINI

# Lista de peças LISTA DE PEÇAS REV-C

TAG Posicionamento | QTD | CÓDIGO DA PEÇA | DESCRIÇÃO | FABRICANTE
-q.23.1.1 | 1 | 3VM9111-0WD30 | ACESSÓRIO PARA 3VM - COBERTURA PADRÃO PARA BORNE (3VM11) | SIEMENS /23.1
-q.23.1.1 | 1 | 3VM9988-0AA12 | BLOCO DE CONTATO AUXILIAR 6A 1NAF PARA DISJUNTOR 3VM | SIEMENS /23.1
-q.23.1.1 | 1 | 3VM9153-0JA11 | ACESSÓRIO PARA 3VM - BORNE DE CONEXÃO PARA CABOS 1,5 - 70mm² | SIEMENS /23.1
-q.23.1.1 | 1 | 9342510 | ADAPTADOR DE APARELHOS 160A/90mm - 690V SAÍDA DE CABOS P/BAIXO | RITTAL /23.1
-q.23.1.1 | 1 | 9342570 | CONTONEIRA DE CONEXÃO PARA ADAPTADOR DE 160A | RITTAL /23.1
-s.8.2.1 | 1 | 2500460 | CHAVE DE POSICION. P/ ILUMINAÇÃO LED C/ CABO 600MM | RITTAL /08.2
-s.8.4.2 | 1 | 2500460 | CHAVE DE POSICION. P/ ILUMINAÇÃO LED C/ CABO 600MM | RITTAL /08.4
-s.8.6.3 | 1 | 2500460 | CHAVE DE POSICION. P/ ILUMINAÇÃO LED C/ CABO 600MM | RITTAL /08.6
-s.13.0.1 | 1 | ZSB/M/60/120 | SENSOR DE TEMPERATURA | VARIXX /13.0
-s.13.0.1 | 2 | ZFI | ABRAÇADEIRA FITA INOX PARA SENSORES BT | VARIXX /13.0
-s.13.1.2 | 1 | ZSB/M/60/120 | SENSOR DE TEMPERATURA | VARIXX /13.1
-s.13.1.2 | 2 | ZFI | ABRAÇADEIRA FITA INOX PARA SENSORES BT | VARIXX /13.1
-s.13.1.9 | 1 | ZSB/M/60/120 | SENSOR DE TEMPERATURA | VARIXX /13.1
-s.13.1.9 | 2 | ZFI | ABRAÇADEIRA FITA INOX PARA SENSORES BT | VARIXX /13.1
-s.13.2.10 | 1 | ZSB/M/60/120 | SENSOR DE TEMPERATURA | VARIXX /13.2
-s.13.2.10 | 2 | ZFI | ABRAÇADEIRA FITA INOX PARA SENSORES BT | VARIXX /13.2
-s.13.3.3 | 1 | ZSB/M/60/120 | SENSOR DE TEMPERATURA | VARIXX /13.3
-s.13.3.3 | 2 | ZFI | ABRAÇADEIRA FITA INOX PARA SENSORES BT | VARIXX /13.3
-s.13.3.11 | 1 | ZSB/M/60/120 | SENSOR DE TEMPERATURA | VARIXX /13.3
-s.13.3.11 | 2 | ZFI | ABRAÇADEIRA FITA INOX PARA SENSORES BT | VARIXX /13.3
-s.13.4.4 | 1 | ZSB/M/60/120 | SENSOR DE TEMPERATURA | VARIXX /13.4
-s.13.4.4 | 2 | ZFI | ABRAÇADEIRA FITA INOX PARA SENSORES BT | VARIXX /13.4
-s.13.4.12 | 1 | ZSB/M/60/120 | SENSOR DE TEMPERATURA | VARIXX /13.4
-s.13.4.12 | 2 | ZFI | ABRAÇADEIRA FITA INOX PARA SENSORES BT | VARIXX /13.4
-s.13.5.5 | 1 | ZSB/M/60/120 | SENSOR DE TEMPERATURA | VARIXX /13.5
-s.13.5.5 | 2 | ZFI | ABRAÇADEIRA FITA INOX PARA SENSORES BT | VARIXX /13.5
-s.13.6.6 | 1 | ZSB/M/60/120 | SENSOR DE TEMPERATURA | VARIXX /13.6
-s.13.6.6 | 2 | ZFI | ABRAÇADEIRA FITA INOX PARA SENSORES BT | VARIXX /13.6

30/09/2025

EALBERTINI 31/07/2025 PROJ.

VERIF.

NOME DATA

MODIFICACAO REV.

A
B

DATA

C

D

## REV. NOME DO PROJETO

### NOME DA PÁGINA

BANCO DE CAPACITORES 225 kVAR

Lista de peças : ZSB/M/60/120 - 51300214

APROV.

33.h

30/09/2025 DFERREIRA

# TRABALHO DE CONCLUSÃO DE CURSO

EALBERTINI

# Lista de peças LISTA DE PEÇAS REV-C

TAG Posicionamento | QTD | CÓDIGO DA PEÇA | DESCRIÇÃO | FABRICANTE
-s.13.6.13 | 1 | ZSB/M/60/120 | SENSOR DE TEMPERATURA | VARIXX /13.6
-s.13.6.13 | 2 | ZFI | ABRAÇADEIRA FITA INOX PARA SENSORES BT | VARIXX /13.6
-s.13.7.7 | 1 | ZSB/M/60/120 | SENSOR DE TEMPERATURA | VARIXX /13.7
-s.13.7.7 | 2 | ZFI | ABRAÇADEIRA FITA INOX PARA SENSORES BT | VARIXX /13.7
-s.13.7.14 | 1 | ZSB/M/60/120 | SENSOR DE TEMPERATURA | VARIXX /13.7
-s.13.7.14 | 2 | ZFI | ABRAÇADEIRA FITA INOX PARA SENSORES BT | VARIXX /13.7
-s.13.8.15 | 1 | ZFR | RESISTOR DE TERMINAÇÃO PARA SENSORES BT | VARIXX /13.8
-s.13.8.15 | 1 | ZSB/M/60/120 | SENSOR DE TEMPERATURA | VARIXX /13.8
-s.13.8.15 | 2 | ZFI | ABRAÇADEIRA FITA INOX PARA SENSORES BT | VARIXX /13.8
-s.13.9.8 | 1 | ZSB/M/60/120 | SENSOR DE TEMPERATURA | VARIXX /13.9
-s.13.9.8 | 2 | ZFI | ABRAÇADEIRA FITA INOX PARA SENSORES BT | VARIXX /13.9
-s.15.4.1 | 1 | 3SB7130-2AL10-1NA0 | COMUTADOR COMPLETO 3 POSIÇÕES - 1NA+1NA | SIEMENS /15.4
-s.16.4.1 | 1 | 3SB7130-2AL10-1NA0 | COMUTADOR COMPLETO 3 POSIÇÕES - 1NA+1NA | SIEMENS /16.4
-s.17.4.1 | 1 | 3SB7130-2AL10-1NA0 | COMUTADOR COMPLETO 3 POSIÇÕES - 1NA+1NA | SIEMENS /17.4
-s.18.4.1 | 1 | 3SB7130-2AL10-1NA0 | COMUTADOR COMPLETO 3 POSIÇÕES - 1NA+1NA | SIEMENS /18.4
-s.19.4.1 | 1 | 3SB7130-2AL10-1NA0 | COMUTADOR COMPLETO 3 POSIÇÕES - 1NA+1NA | SIEMENS /19.4
-s.20.4.1 | 1 | 3SB7130-2AL10-1NA0 | COMUTADOR COMPLETO 3 POSIÇÕES - 1NA+1NA | SIEMENS /20.4
-s.21.4.1 | 1 | 3SB7130-2AL10-1NA0 | COMUTADOR COMPLETO 3 POSIÇÕES - 1NA+1NA | SIEMENS /21.4
-s.22.4.1 | 1 | 3SB7130-2AL10-1NA0 | COMUTADOR COMPLETO 3 POSIÇÕES - 1NA+1NA | SIEMENS /22.4
-s.23.4.1 | 1 | 3SB7130-2AL10-1NA0 | COMUTADOR COMPLETO 3 POSIÇÕES - 1NA+1NA | SIEMENS /23.4
-u.12.1.1 | 1 | VZX/B1/U | RELÉ DE MONITORAMENTO DE TEMPERATURA | VARIXX /12.1
-u.14.1.1 | 1 | B44066-R6012-S221 | CONTROLADOR DE FATOR DE POTÊNCIA PARA 12 ESTÁGIOS | SIEMENS /14.1
-x.5.8.1 | 1 | 9342310 | ADAPTADOR DE CONEXÕES 800A | RITTAL /05.8
-x.14.7.1 | 1 | 51300214 | BORNE DE AFERIÇÃO PARA 1 TC'S | WAGO /14.6

30/09/2025

EALBERTINI 31/07/2025 PROJ.

VERIF.

NOME DATA

MODIFICACAO REV.

A
B

DATA

C

D

## REV. NOME DO PROJETO

### NOME DA PÁGINA

BANCO DE CAPACITORES 225 kVAR

Lista de peças totalizadas :

APROV.

30/09/2025 DFERREIRA

# TRABALHO DE CONCLUSÃO DE CURSO

EALBERTINI

# Lista de peças totalizadas LISTA TOTALIZADA Ver 6

CÓDIGO PEÇA | QTD | DESCRIÇÃO | FABRICANTE
ZCB/4/2U/400 | 2 | CABO MINI-USB PARA INTERLIGAÇÃO DE SENSORES BT - 4M | VARIXX
ZCB/4/2U/100 | 1 | CABO MINI-USB PARA INTERLIGAÇÃO DE SENSORES BT - 1M | VARIXX
ZCB/4/2U/030 | 4 | CABO MINI-USB PARA INTERLIGAÇÃO DE SENSORES BT - 0,3M | VARIXX
ZTA | 1 | DERIVADOR EM T PARA CABOS MINI-USB DOS SENSORES BT | VARIXX
ZFR | 2 | RESISTOR DE TERMINAÇÃO PARA SENSORES BT | VARIXX
ZCB/4/2U/200 | 3 | CABO MINI-USB PARA INTERLIGAÇÃO DE SENSORES BT - 2M | VARIXX
ZCB/4/2U/050 | 6 | CABO MINI-USB PARA INTERLIGAÇÃO DE SENSORES BT - 0,5M | VARIXX
30x10mm | 21 | BARRAMENTO DE COBRE 30x10mm | GDRW
110x126mm | 9 | CANALETA DE 110x126mm | DUTOPLAST
80x126mm | 6 | CANALETA DE 80x126mm | DUTOPLAST
50x126mm | 1 | CANALETA DE 50x126mm | DUTOPLAST
3092000 | 4 | PERFIL DE COBERTURA PARA BARRAS COLETORAS | RITTAL
9340070 | 3 | COBERTURA DE ACABAMENTO PARA PROTEÇÃO LATERAL | RITTAL
RIT.9340010 | 6 | SUPORTE DE BARRAMENTO 3 POLOS RILINE 60 | RITTAL
C0236500000 | 5 | TRILHO TS 35 X 15 AÇO C/ FURO | WEIDMULLER
RIT.8606500 | 3 | ARMARIO TS 600x2000x600mm RAL 7035 | RITTAL
RIT.8006500 | 1 | ARMARIO TS 1000x2000x600mm RAL 7035 | RITTAL
RIT.8640002 | 3 | ELEMENTO PARA BASE SOLEIRA FRONT. E TRAS. P/TS 600 - 100mm DE ALTURA | RITTAL
RIT.8640033 | 3 | CHAPAS P/ BASE SOLEIRA PARA TS 100X600mm | RITTAL
RIT.8660002 | 3 | ELEMENTO PARA BASE SOLEIRA FRONT. E TRAS. P/TS 600 - 100mm DE ALTURA | RITTAL
RIT.8660033 | 10 | ACABAMENTO LATERAL PARA BASE SOLEIRA VX - 100mm DE ALTURA | RITTAL
RIT.8660005 | 3 | ELEMENTO PARA BASE SOLEIRA FRONT. E TRAS. P/TS 1000 - 100mm DE ALTURA | RITTAL
RIT.4591700 | 3 | PLACA DE MONTAGEM INTERMEDIARIA 2000mm | RITTAL
RIT.4540000 | 6 | CANTONEIRA COMBINADA | RITTAL
RIT.8611290 | 4 | FECHO COMFORT PARA CADEADO | RITTAL
RIT.8611190 | 4 | BOTÃO PULSANDOR PARA FECHO COMFORT | RITTAL
TITULO | 4 | PLAQUETA DE TÍTULO PARA PAINEL ELÉTRICO | ZTK

0 | 1 | 2 | 3 | 4 | 5 | 6 | 7 | 8 | 9

30/09/2025

EALBERTINI 31/07/2025 PROJ.

VERIF.

NOME DATA

MODIFICACAO REV.

A
B

DATA

C

D

## REV. NOME DO PROJETO

### NOME DA PÁGINA

BANCO DE CAPACITORES 225 kVAR

Lista de peças totalizadas :

APROV.

34.a

30/09/2025 DFERREIRA

# TRABALHO DE CONCLUSÃO DE CURSO

EALBERTINI

# Lista de peças totalizadas LISTA TOTALIZADA Ver 6

CÓDIGO PEÇA | QTD | DESCRIÇÃO | FABRICANTE
RIT.3079000 | 12 | SUPORTE UNIVERSAL PARA BARRAMENTO FLEXÍVEL | RITTAL
RIT.8106235 | 2 | FECHAMENTO LATERIAL 600mm | RITTAL
RIT.7466035 | 3 | PRATELEIRA PARA FIXAÇÃO NO QUADRO | RIT
RIT.3574005 | 3 | BARRAS LAMINADAS EM COBRE 10x32x1MM 965A | RITTAL
B32344-E4282-Z040 | 9 | CÉLULA CAPACITIVA DE 33,7kVAR EM 440V | SIEMENS
2500100 | 3 | LUMINARIA LED 400 100-240V 50/60HZ | RITTAL
952405 | 1 | DPS CLASSE II - DG M TNS 275 FM | DEHN
787-732 | 1 | FONTE CHAVEADA EPSITRON® ECO Power - 24VCC -10A | WAGO
3SB7213-6AA20-1AA0 | 10 | SINALEIRO MONOBLOCO VERMELHO - 24V CA/CC | SIEMENS
3SB7213-6AA40-1AA0 | 1 | SINALEIRO MONOBLOCO VERDE - 24V CA/CC | SIEMENS
3SB7213-6AA30-1AA0 | 1 | SINALEIRO MONOBLOCO AMARELO - 24V CA/CC | SIEMENS
3SB7213-6AA60-1AA0 | 1 | SINALEIRO MONOBLOCO BRANCO - 24V CA/CC | SIEMENS
3RT2628-1BB45 | 9 | CONTATOR PARA CAPACITOR 33kVAR EM 380V - 24VCC | SIEMENS
25kVAR-7%-380V | 9 | REATOR DE DESSINTONIA 25kVAR - 7% - 380V | COSMO
3243700 | 2 | VENTILADOR COM FILTRO BLUE E+ 625/716m³/H 230V RAL7035 | RITTAL
3243300 | 4 | FILTRO DE SAÍDA 323X323mm RAL7035 | RITTAL
3139100 | 2 | VENTILADOR DE TETO SEM FILTRO 360/373m³/H 230V RAL7035 | RITTAL
3173120 | 2 | ELEMENTO PLISSADO IP54 PARA SK3243 3244 3245 | RITTAL
3VA1580-5EF32-0AA0 | 1 | DISJUNTOR CAIXA MOLDADA 3VA15 55kA 380V - 560...800A | SIEMENS
3VA9687-0FK21 | 1 | ACESSÓRIO PARA 3VA15/25 - ACIONAMENTO ROTATIVO EXTERNO COMPLETO | SIEMENS
3VA9601-0WF30 | 1 | ACESSÓRIO PARA 3VA - COBERTURA ESTENDIDA PARA BORNE (3VA15/25) | SIEMENS
3VA9603-0QB00 | 1 | ACESSÓRIO 3VA15/25 - BARRA DE CONEXÃO FRONTAL COM SEPARADOR DE FASE - 3 POLOS - (50MM X 28MM) | SIEMENS
3VA9988-0AA12 | 1 | BLOCO DE CONTATO AUXILIAR 1NAF PARA DISJUNTOR 3VA | SIEMENS
3VA9988-0AB12 | 1 | BLOCO DE CONTATO ALARME TAS PARA DISJUNTOR 3VA | SIEMENS
3VM1112-5ED32-0AA0 | 1 | DISJUNTOR CAIXA MOLDADA 3VM11 55kA 380V - 125A | SIEMENS
3VM9153-0JA11 | 10 | ACESSÓRIO PARA 3VM - BORNE DE CONEXÃO PARA CABOS 1,5 - 70mm² | SIEMENS
3VM9111-0WF30 | 11 | ACESSÓRIO PARA 3VM - COBERTURA ESTENDIDA PARA BORNE (3VM11) | SIEMENS

30/09/2025

EALBERTINI 31/07/2025 PROJ.

VERIF.

NOME DATA

MODIFICACAO REV.

A
B

DATA

C

D

## REV. NOME DO PROJETO

### NOME DA PÁGINA

BANCO DE CAPACITORES 225 kVAR

Lista de peças totalizadas :

APROV.

34.b

30/09/2025 DFERREIRA

# TRABALHO DE CONCLUSÃO DE CURSO

EALBERTINI

# Lista de peças totalizadas LISTA TOTALIZADA Ver 6

CÓDIGO PEÇA | QTD | DESCRIÇÃO | FABRICANTE
3VM9988-0AA12 | 10 | BLOCO DE CONTATO AUXILIAR 6A 1NAF PARA DISJUNTOR 3VM | SIEMENS
3VA1140-5ED32-0AA0 | 1 | DISJUNTOR CAIXA MOLDADA 40A 55kA | SIEMENS
3VA9153-0JA11 | 1 | ACESSÓRIO PARA 3VA - BORNE DE CONEXÃO PARA CABOS 1,5 - 70mm² | SIEMENS
3VA9111-0WD30 | 1 | ACESSÓRIO PARA 3VA - COBERTURA PADRÃO PARA BORNE (3VA1-100A e 160A) | SIEMENS
3VA9111-0WF30 | 1 | ACESSÓRIO PARA 3VA - COBERTURA ESTENDIDA PARA BORNE (3VA1-100A e 160A) | SIEMENS
9342510 | 10 | ADAPTADOR DE APARELHOS 160A/90mm - 690V SAÍDA DE CABOS P/BAIXO | RITTAL
9342570 | 10 | CONTONEIRA DE CONEXÃO PARA ADAPTADOR DE 160A | RITTAL
5SY4125-7 | 1 | MINI DISJUNTOR 1P CURVA C 25A | SIEMENS
5SY4102-7 | 1 | MINI DISJUNTOR 1P CURVA C 2A | SIEMENS
5ST3708-0MB | 1 | BARRAMENTO DE ALIMENTAÇÃO TRIFÁSICO 80/130A PARA MINI DISJUNTOR | SIEMENS
5SY4106-7 | 1 | MINI DISJUNTOR 1P CURVA C 6A | SIEMENS
5SY4104-7 | 1 | MINI DISJUNTOR 1P CURVA C 4A | SIEMENS
5SY4110-7 | 1 | MINI DISJUNTOR 1P CURVA C 10A | SIEMENS
5SL1102-7 | 3 | MINI DISJUNTOR 1P CURVA C 2A | SIEMENS
5ST3730-0MB | 1 | BARRAMENTO DE ALIMENTAÇÃO MONOFÁSICO 63/80A PARA MINI DISJUNTOR | SIEMENS
5SL1104-7 | 1 | MINI DISJUNTOR 1P CURVA C 4A | SIEMENS
3VM1180-4EE32-0AA0 | 9 | DISJUNTOR CAIXA MOLDADA 3VM11 36kA 380V - 56...80A | SIEMENS
3VM9111-0WD30 | 9 | ACESSÓRIO PARA 3VM - COBERTURA PADRÃO PARA BORNE (3VM11) | SIEMENS
2500460 | 3 | CHAVE DE POSICION. P/ ILUMINAÇÃO LED C/ CABO 600MM | RITTAL
ZSB/M/60/120 | 15 | SENSOR DE TEMPERATURA | VARIXX
ZFI | 30 | ABRAÇADEIRA FITA INOX PARA SENSORES BT | VARIXX
3SB7130-2AL10-1NA0 | 9 | COMUTADOR COMPLETO 3 POSIÇÕES - 1NA+1NA | SIEMENS
VZX/B1/U | 1 | RELÉ DE MONITORAMENTO DE TEMPERATURA | VARIXX
B44066-R6012-S221 | 1 | CONTROLADOR DE FATOR DE POTÊNCIA PARA 12 ESTÁGIOS | SIEMENS
9342310 | 1 | ADAPTADOR DE CONEXÕES 800A | RITTAL
51300214 | 1 | BORNE DE AFERIÇÃO PARA 1 TC'S | WAGO

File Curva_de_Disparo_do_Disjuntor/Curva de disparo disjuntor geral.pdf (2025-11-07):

9 de out de 2025 Dados do cliente: Projeto do escritório: | Emerson.Albertini Nome do projeto: Localização: Cliente: | Criado com Documentação do projeto Versão: 25.1 quinta-feira, 9 de outubro de 2025 Dados principais Descrição do projeto: Criado em: | Projeto banco de capacitor 225 kVAr quinta-feira, 9 de outubro de 2025 Comentário | SIMARIS curves Projetista: | © SIEMENS AG 2025 All rights reserved. Alterado com:


http://www.siemens.com/simaris

s


## 9 de out de 2025

O conteúdo técnico foi cuidadosamente verificado. Contudo é sem garantias e pode ser alterado
sem aviso prévio.
Atenção Curvas características | Português Modelo: 3VA15

Baixa tensão

Designação | | L | I
| In [A] | Ir [A] | Ii [A]
3VA15805EF320AA0 | 800 | 800 | 8.000

O conteúdo técnico foi cuidadosamente verificado. Contudo é sem garantias e pode ser alterado
sem aviso prévio.
Atenção Ajustes | Português Modelo: 3VA15

O conteúdo técnico foi cuidadosamente verificado. Contudo é sem garantias e pode ser alterado
sem aviso prévio.
Atenção Curva da corrente Cut off a 415 V / 50 Hz | Português Modelo: 3VA15805EF320AA0


O conteúdo técnico foi cuidadosamente verificado. Contudo é sem garantias e pode ser alterado
sem aviso prévio.
Atenção Curva da energia passante a 415 V / 50 Hz | Português Modelo: 3VA15805EF320AA0

I²t [A²s]

In [A] | 9 de out de 2025 Legenda de símbolos: Corrente nominal

Símbolo [unidade] | Descrição

Char | Característica - curva padrão i²t ou i4t

I [A] | Corrente

I²t [A²s] | Energia passante

I> [A] / Ip [A] | Corrente de energização de fase do modulo relé DMT

I>> [A] | Corrente de energização de fase do módulo de alta corrente do relé DMT

I>>> [A] | Corrente de energização de fase do módulo do disparador instantêneo do relé DMT

Ic [A] | Corrente passante

Ie [A] | Corrente de falha à terra do relé DMT

Ig [A] | Valor ajuste do disparador G para detecção de falha à terra

Ii [A] | Valor de ajuste do disparador instantêneo de curto-circuito (I)

Ir [A] | Valor de ajuste da corrente do disparador de sobrecarga (L)

Isd [A] | Valor de ajuste da temporização do disparador de curto-circuito (S)

t [s] | Tempo

t> [s] / tp [s] | Temporização do módulo de sobrecorrente do relé DMT

t>> [s] | Temporização do módulo de alta corrente do relé DMT

t>>> [s] | Temporização do módulo de disparo instantaneo do relé DMT

te [s] | Temporização da corrente de falha à terra do relé DMT

tg [s] | Valor da temporização do disparador G (absoluto)

tr [s] | Temporização do disparador-L

tsd [s] | Temporização do disparador-S

ti [s] | Temporização do disparador-I

Uprim [kV] | Média tensão

Usec [V] | Baixa tensão

Relação de transformação da corrente | Relação de transformação da corrente



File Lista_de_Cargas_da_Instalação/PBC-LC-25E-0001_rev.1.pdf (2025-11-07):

Lista de Cargas | PBC-LC-25E-0001
Projeto N°: PBC-001-25E-0001 | Projeto: Banco de Capacitor
1 | 10/05/2025 | EALB | EALB | DFER | Aprovado
0 | 08/04/2025 | EALB | EALB | DFER | Para Comentários
Rev. | Data | Elaborado | Revisado | Aprovado | Propósito da Emissão

# Lista de Cargas

Revisão - 01 | PBC-LC-25E-0001

Lista de Cargas | PBC-LC-25E-0001
Projeto N°: PBC-001-25E-0001 | Projeto: Banco de Capacitor
Descrição | Fator de Potência Atual | Potência Ativa Demandada ⁽kW⁾ | Potência Aparente Demandada ⁽kVA⁾ - | Potência Reativa Demandada (kVAr⁾ | Corrente Nominal Demandada ⁽A⁾ | Carregamento do Trafo ⁽%⁾
TRAFO-001 | 0.87 | | | | | 100%
QGBT-001 | | 853 | 986 | 495 | 1498 | 98.87%
RESERVA (10%) | | 85 | 99 | 49 | 150 | 10.00%
TOTAL | | 938 | 1084 | 544 | 1648 | 108.87%

# REFERÊNCIAS:

3 - OS QUADROS DE DISTRIBUIÇÃO DE FORÇA (QDF) INDICADOS NESSA LISTA, ALIMENTAM ALÉM DA CARGAS TERMINAIS, OUTROS QUADROS COMO OS DE DISTRIBUIÇÃO DE FORÇA E ILUMINAÇÃO (QDFL), PARA DETALHES DE CARGAS, DEVERÁ SE CONSULTADOS OS DIAGRAMAS UNIFILARES CORRESPONDENTE A CADA QUADRO;

# 5 - OS PAINÉIS DE BAIXA TENSÃO DEVERÃO ESTAR EM CONFORMIDADE COM A NORMA ABNT NBR IEC

61439:2016, BEM COMO NR-10 E NR-12;

# 6 - DEVERÁ SER PREVISTO UM BANCO DE CAPACITOR PARA CORRIGIR O FATOR DE POTÊNCIA DA

INSTALAÇÃO E LIBERAR POTÊNCIA DO TRANSFORMADOR;
7 - PARA DIAGRAMA UNIFILAR VER DOCUMENTO: UN-PBC-25E-0001.

1 - ABNT – Associação Brasileira De Normas Técnicas. NBR 5410: Instalações Elétricas de Baixa Tensão. Rio de Janeiro: ABNT, 2004. 209 p.

2 - ABNT – Associação Brasileira de Normas Técnicas. NBR 5419: Proteção contra descargas atmosféricas. Rio de Janeiro: ABNT, 2015.

3 - ABNT – Associação Brasileira De Normas Técnicas. NBR IEC 61439-1: Conjuntos de manobra e controle de baixa tensão - Parte 1: Regras gerais. Rio de Janeiro: ABNT, 2016. 147 p.

4 - ABNT – Associação Brasileira De Normas Técnicas. NBR IEC 61439-2: Conjuntos de manobra e controle de baixa tensão - Parte 2: Requisitos para conjuntos de manobra e controle de baixa tensão. Rio de Janeiro: ABNT, 2016. 22 p.

5 - ABNT. Associação Brasileira de Normas Técnicas. ABNT NBR IEC 60947-2: Aparelhos de manobra e comando de baixa tensão – Parte 2: Disjuntores. Rio de Janeiro, 2011.

6 - ANEEL – Agência Nacional de Energia Elétrica. Resolução Normativa ANEEL nº 1000. Brasília, ANEEL, 2021.

7 - Ministério do Trabalho e Emprego. NR 10: Segurança em Instalações e Serviços em Eletricidade. Brasília: Ministério do Trabalho e Emprego, 2019.

8 - Ministério do Trabalho e Emprego. NR 12: Segurança no Trabalho em Máquinas e Equipamentos. Brasília: Ministério do Trabalho e Emprego, 2019.

4 - O PAINEL DE MÉDIA TENSÃO DEVE ESTAR EM CONFORMIDADE COM A NORMA ABNT NBR IEC 62271-200 E A ABNT NBR 14039;

# RESUMO DAS CARGAS:
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

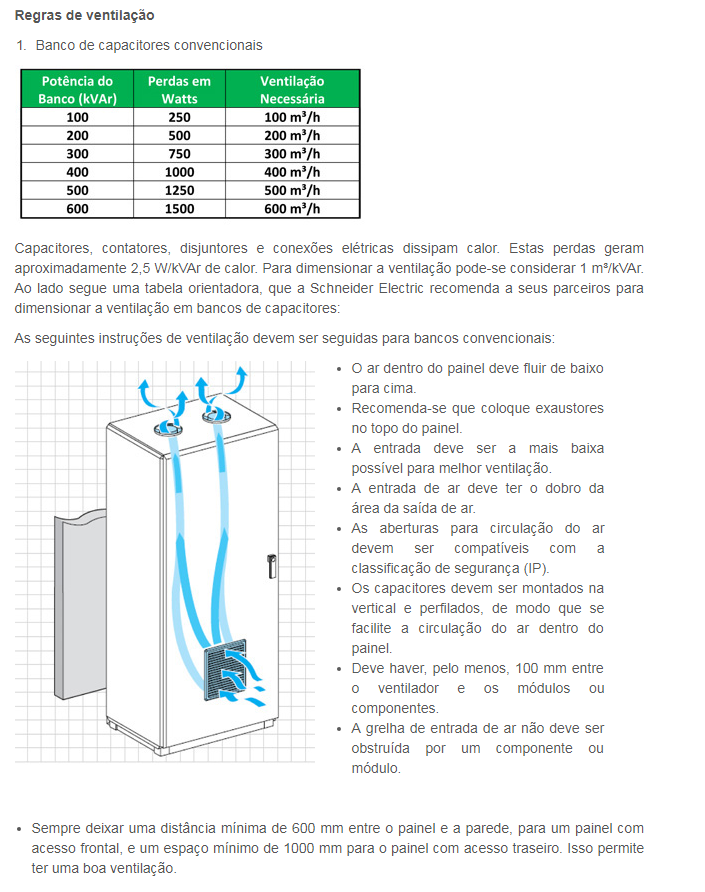
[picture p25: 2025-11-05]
Cálculo_de_Climatização/Climatização banco de capacitores - 2.PNG

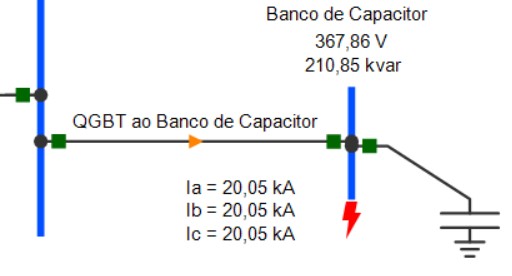
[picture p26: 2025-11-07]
Cálculo_de_Curto-Circuito/Nível de C.C. no barramento do B.C..jpg

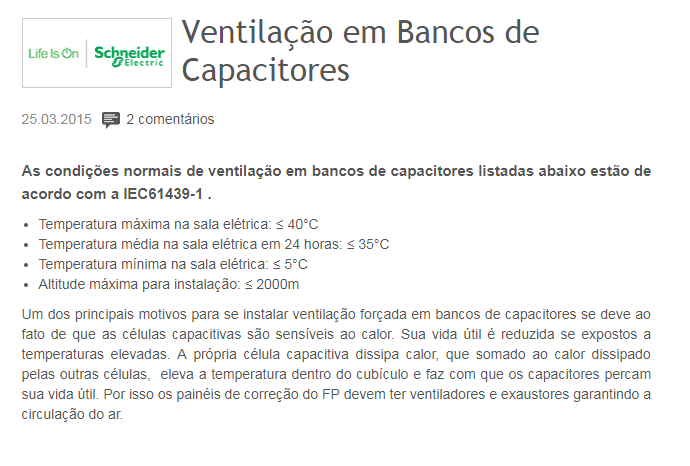
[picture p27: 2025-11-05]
Cálculo_de_Climatização/Climatização banco de capacitores - 1.PNG

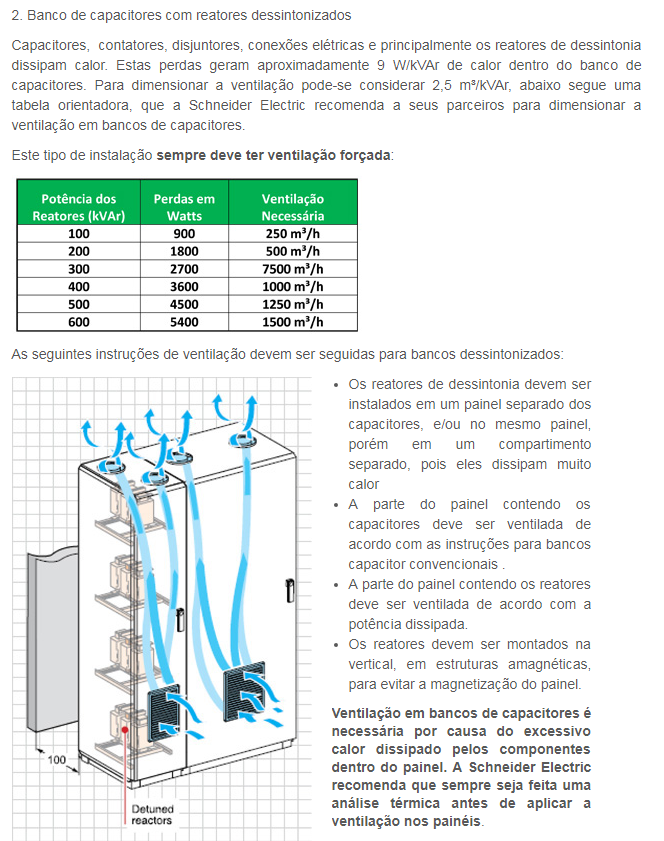
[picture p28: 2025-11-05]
Cálculo_de_Climatização/Climatização banco de capacitores - 3.PNG

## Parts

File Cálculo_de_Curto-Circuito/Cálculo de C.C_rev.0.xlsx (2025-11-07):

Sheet: CÁLCULO
CÁLCULO DE CURTO-CIRCUITO
DESCRIÇÃO | ETAPAS | VALOR | UNIDADE | OBSERVAÇÃO
 | VALORES BASE
GERAÇÃO | Tensão base - MT - VB | 13800 | V | 13,8 kV
 | Potência base | 100000000 | VA | 100 MVA
 | Impedância base - Zb | 1.9044 | Ohms
 | Corrente base - Ib | 4183.697603 | A | 4,18 kA
 | Tensão base - BT - Vbbt | 380 | V
 | Corrente base - Ibbt | 151934.2814 | A | 151,93kA
 | IMPEDÂNCIAS DO SISTEMA DE SUPRIMENTO
 | Seq. positiva - Zps | 0.02+0.3j |  | p.u. na base de 100MVA e 13,8kV
 | Rps | 0.02
 | Xps | 0.3
 | Seq. zero - Zps | 0.04+0.6j |  | p.u. na base de 100MVA e 13,8kV
 | Rp0 | 0.04
 | Xp0 | 0.6
 | CORRENTE DE CURTO-CIRCUITO NO PONTO DE FORNECIMENTO DE ENERGIA MÉDIA TENSÃO
 | CORRENTE DE CURTO CIRCUITO TRIFÁSICA ICS
 | Ics | 925.596814783932-13883.952221759j | A (cartesiano) | Ics=13,91 < -86,19° kA
 | Módulo de Ics | 13914.77 | A
 | Fase de Ics | -86.19 | Graus
 | CORRENTE DE CURTO CIRCUITO FASE-TERRA ICFT
 | Zeq até este ponto | 0.08+1.2j
 | Icft | 694.197611087949-10412.9641663192j | A (cartesiano) | Icft=10,44 < -86,19° kA
 | Módulo de Icft | 10436.08 | A
 | Fase de Icft | -86.19 | Graus
 | CORRENTE ASSIMÉTRICA DE CURTO-CIRCUITO NO SISTEMA DE SUPRIMENTO
 | Relação X/R CCM | 15
 | Fator de assimetria | 1.62 | Tabelado (aproximado)
 | Corrente de curto circuito assimétrico - Ica | 22541.92941 | A | 22,54 kA
 | Impulso da corrente de curto circuito - Icim | 31879.1023 | A | 31,88 kA
 | Cálculo do fator de assimetria | 1.619450848 | Valor real
 | Tau | 0.03978873577
 | Corrente de curto circuito assimétrico - Ica | 22534.28809 | A | 22,53 kA.
 | Impulso da corrente de curto circuito - Icim | 31868.29584 | A | 31,87 kA.
TRANSFORMADOR | IMPEDÂNCIA DO TRANSFORMADOR
 | Pot. nominal do trafo | 1000 | kVA | 1000 kVA
 | Perdas totais | 14600 | W | 14.6 kW
 | Res. percentual Rpt | 1.46 | % | 1.46%
 | Res. pu Rut | 0.0146 | pu | Na base de 1000 kVA
 | Res. pu Rut | 1.46 | pu | Na base de 100 MVA
 | Imp. percentual Zpt | 0.06 | pu | 6% - dado de placa
 | Imp. p.u. Zut | 6 | pu | Na base de 100 MVA
 | Reatância pu Xut | 5.819656347 | pu | Na base de 100 MVA
 | Imp. Dotrafo | 1.46+5.81965634724251j | pu | 1,46 + j5,82 pu
 | CORRENTE DE CURTO-CIRCUITO NO SECUNDÁRIO DO TRAFO (LADO BT)
 | CORRENTE DE CURTO CIRCUITO TRIFÁSICA ICS
 | Zeq até este ponto - Seq. positiva | 1.48+6.11965634724251j
 | Ics | 5672.53703383934-23455.3900433129j | A (cartesiano) | Ics=24,13 < -76,40° kA
 | Módulo de Ics | 24131.57679 | A
 | Fase de Ics | -76.40442858 | Graus
 | CORRENTE DE CURTO CIRCUITO FASE-TERRA ICFT
 | Zeq até este ponto - Lado de BT | 4.46+18.6589690417275j
 | Icft | 5523.4009594946-23107.8402484883j | A (cartesiano) | Icft=23,76 < -76,56° kA
 | Módulo de Icft | 23758.79288 | A
 | Fase de Icft | -76.55698332 | Graus
 | CORRENTE ASSIMÉTRICA DE CURTO-CIRCUITO NO SECUNDÁRIO DO TRANSFORMADOR
 | Relação X/R CCM | 4.135135135
 | Fator de assimetria | 1.39 | Tabelado (aproximado)
 | Corrente de curto circuito assimétrico - Ica | 33542.89174 |  | 33,54 kA
 | Impulso da corrente de curto circuito - Icim | 47436.81242 |  | 47,44 kA
 | Cálculo do fator de assimetria | 1.391243967 | Valor real
 | Tau | 0.01095086376
 | Corrente de curto circuito assimétrico - Ica | 33572.91062 |  | 33,57 kA
 | Impulso da corrente de curto circuito - Icim | 47479.26552 |  | 47,48 kA
QUADRO GERAL (QGBT) | IMPEDÂNCIA DO CIRCUITO DO TRAFO AO QGBT
 | Lc | 10 | m | Comprimento dos cabos
 | Nc | 4 |  | Condutores por fase
 | Sc | 185 | mm² | Seção dos condutores
 | SEQUÊNCIA POSITIVA
 | R_Cabo | 0.1226 | mOhms/m | Tabelado
 | R_CaboPos_ohm | 0.0003065 | Ohms
 | R_CaboPos_pu | 0.2122576177 | pu
 | X_Cabo | 0.1073 | mOhms/m | Tabelado
 | X_CaboPos_ohm | 0.00026825 | Ohms
 | X_CaboPos_pu | 0.1857686981 | pu
 | Z_CaboPos_pu | 0.212257617728532+0.185768698060942j | pu
 | SEQUÊNCIA ZERO
 | R_Cabo | 1.9226 | mOhms/m | Tabelado
 | R_CaboPos_ohm | 0.0048065 | Ohms
 | R_CaboPos_pu | 3.328601108 | pu
 | X_Cabo | 2.4594 | mOhms/m | Tabelado
 | X_CaboPos_ohm | 0.0061485 | Ohms
 | X_CaboPos_pu | 4.257963989 | pu
 | Z_CaboPos_pu | 3.32860110803324+4.25796398891967j | pu
 | CORRENTE DE CURTO-CIRCUITO NO BARRAMENTO DO QGBT
 | CORRENTE DE CURTO CIRCUITO TRIFÁSICA ICS
 | Zeq até este ponto - Seq. positiva | 1.69225761772853+6.30542504530345j
 | Ics | 6032.35925213481-22476.8313714163j | A (cartesiano) | Ics=23,27 < -74,98° kA
 | Módulo de Ics | 23272.24327 | A
 | Fase de Ics | -74.97690771 | Graus
 | CORRENTE DE CURTO CIRCUITO FASE-TERRA ICFT
 | Zeq até este ponto | 4.88451523545706+19.0305064378494j
 | Icft | 5767.53442741141-22470.8278632486j | A (cartesiano) | Icft=23,20 < -75,60° kA
 | Módulo de Icft | 23199.19305 | A
 | Fase de Icft | -75.60476885 | Graus
 | CORRENTE ASSIMÉTRICA DE CURTO-CIRCUITO NO BARRAMENTO DO QGBT
 | Relação X/R CCM | 3.733727811
 | Fator de assimetria | 1.37 | Tabelado (aproximado)
 | Corrente de curto circuito assimétrico - Ica | 31882.97327 |  | 31,88 kA
 | Impulso da corrente de curto circuito - Icim | 45089.33321 |  | 45,09 kA
 | Cálculo do fator de assimetria | 1.365051927 | Valor real
 | Tau | 0.00990402062
 | Corrente de curto circuito assimétrico - Ica | 31767.82052 |  | 31,77 kA
 | Impulso da corrente de curto circuito - Icim | 44926.48263 |  | 44,93 kA
PAINEL DO BANCO DE CAPACITOR | IMPEDÂNCIA DO QGBT-001 AO PAINEL DO BANCO DE CAPACITORES
 | Lc | 20 | m | Comprimento dos cabos
 | Nc | 2 |  | Condutores por fase
 | Sc | 185 | mm² | Seção dos condutores
 | SEQUÊNCIA POSITIVA
 | R_Cabo | 0.1226 | mOhms/m | Tabelado
 | R_CaboPos_ohm | 0.001226 | Ohms
 | R_CaboPos_pu | 0.8490304709 | pu
 | X_Cabo | 0.1073 | mOhms/m | Tabelado
 | X_CaboPos_ohm | 0.001073 | Ohms
 | X_CaboPos_pu | 0.7430747922 | pu
 | Z_CaboPos_pu | 0.849030470914127+0.743074792243767j | pu
 | SEQUÊNCIA ZERO
 | R_Cabo | 1.9226 | mOhms/m | Tabelado
 | R_CaboPos_ohm | 0.019226 | Ohms
 | R_CaboPos_pu | 13.31440443 | pu
 | X_Cabo | 2.4594 | mOhms/m | Tabelado
 | X_CaboPos_ohm | 0.024594 | Ohms
 | X_CaboPos_pu | 17.03185596 | pu
 | Z_CaboPos_pu | 13.314404432133+17.0318559556787j | pu
 | CORRENTE DE CURTO-CIRCUITO NO BARRAMENTO DO PAINEL DO BANCO DE CAPACITORES
 | CORRENTE DE CURTO CIRCUITO TRIFÁSICA
 | Zeq até este ponto - Seq. positiva | 2.54128808864266+7.04849983754722j
 | Ics | 6877.66747347535-19075.8530235693j | A (cartesiano) | Ics=20,27 < -70,17° kA
 | Módulo de Ics | 20277.83219 | A
 | Fase de Ics | -70.17358043 | Graus
 | CORRENTE DE CURTO CIRCUITO FASE-TERRA
 | Zeq até este ponto - Banco de capacitores | 21.5275207756233+40.3203263824478j
 | Icft | 4696.76411314383-8796.88209140023j | A (cartesiano) | Icft=9,97< -61,90° kA
 | Módulo de Icft | 9972.197735 | A
 | Fase de Icft | -61.9016902 | Graus
 | CORRENTE ASSIMÉTRICA DE CURTO-CIRCUITO NO PAINEL DO BANCO DE CAPACITORES
 | Relação X/R CCM | 2.775590551
 | Fator de assimetria | 1.28 | Tabelado (aproximado)
 | Corrente de curto circuito assimétrico - Ica | 25955.62521 |  | 25,95 kA
 | Impulso da corrente de curto circuito - Icim | 36706.79719 |  | 36,71 kA
 | Cálculo do fator de assimetria | 1.28297774 | Valor real
 | Tau | 0.007362482604
 | Corrente de curto circuito assimétrico - Ica | 26016.00733 |  | 26,02 kA
 | Impulso da corrente de curto circuito - Icim | 36792.1904 |  | 36,79 kA

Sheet: RESULTADOS
TABELA DE RESULTADOS
Local | Ics (kA) | Icft (kA) | X/R | Fator de assimetria | Ica (kA) | Icim (kA)
Fornecimento de energia - lado MT | 13.91 | 10.44 | 15.00 | 1.62 | 22.53 | 31.87
Transformador - lado BT | 24.13 | 23.76 | 4.14 | 1.39 | 33.57 | 47.48
Painel elétrico QGBT-001 | 23.27 | 23.20 | 3.73 | 1.37 | 31.77 | 44.93
Banco de capacitores | 20.28 | 9.97 | 2.78 | 1.28 | 26.02 | 36.79
TABELA DE RESULTADOS SIMULAÇÃO (PSP-UFU)
Local | Ics (kA) | Icft (kA)
Fornecimento de Energia | 13.93 | 10.44
Transformador - lado BT | 24.09 | 24.46
QGBT | 23.22 | 19.19
Banco de Capacitores | 20.05 | 9.19

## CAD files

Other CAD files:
Diagrama_Unifilar_da_Instalação/PBC-UN-25E-0001_rev1.dwg

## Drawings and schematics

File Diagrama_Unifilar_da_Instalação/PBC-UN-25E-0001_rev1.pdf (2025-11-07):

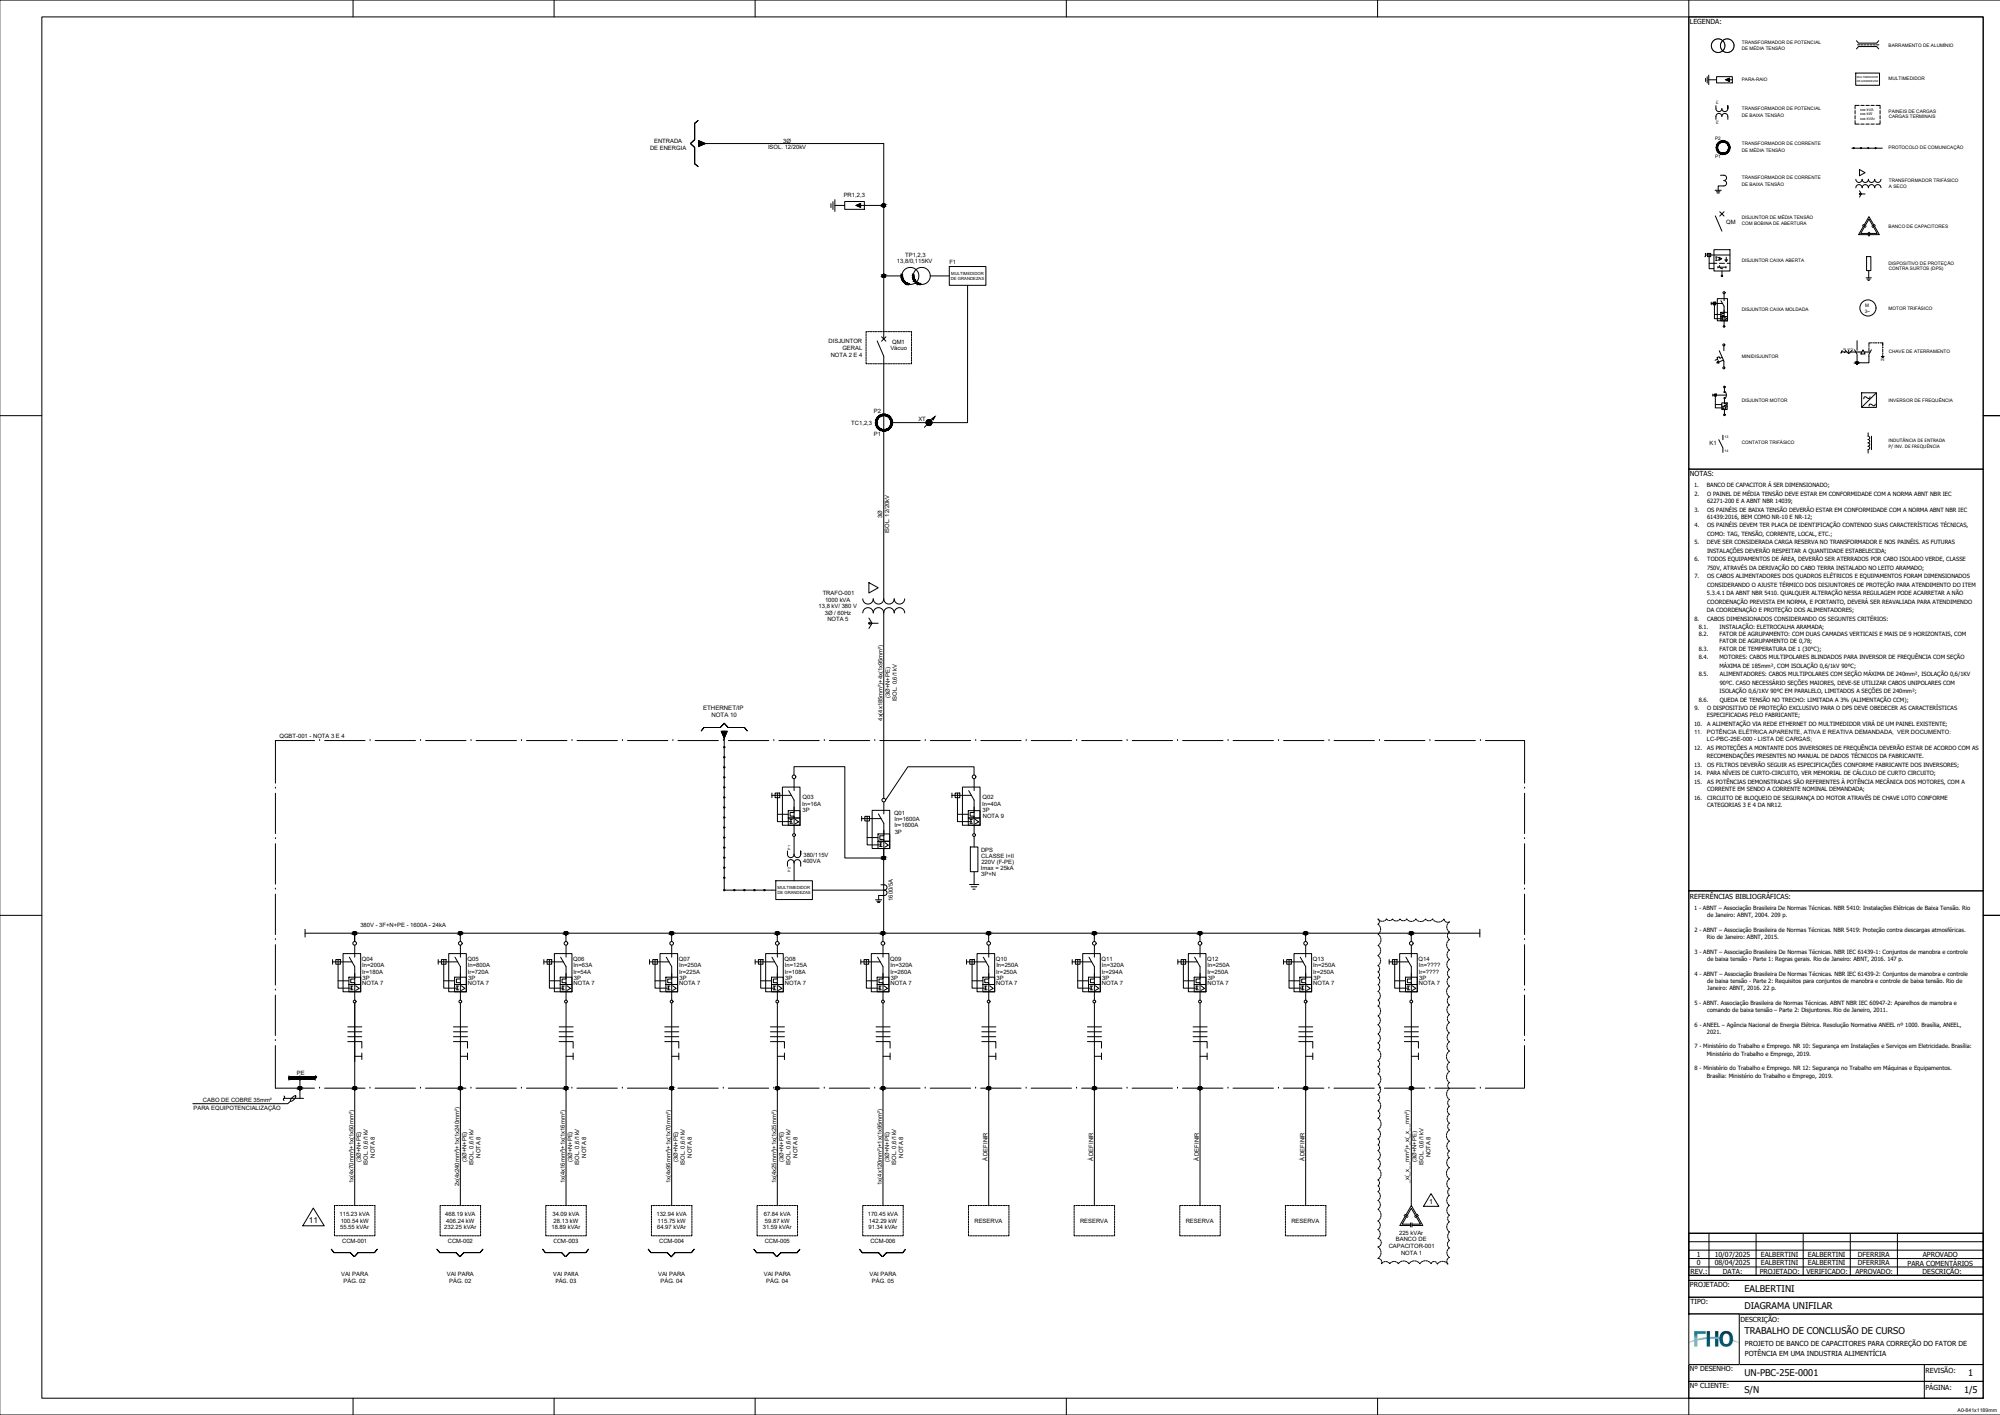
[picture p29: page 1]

4x(4x185mm²)+4x(1x95mm²) A0-841x1189mm PÁGINA: REVISÃO: TIPO: PROJETADO: Nº DESENHO: REFERÊNCIAS BIBLIOGRÁFICAS: NOTAS: LEGENDA: REV.: DATA: PROJETADO: VERIFICADO: APROVADO:

P1 P2 TRANSFORMADOR DE POTENCIAL DE BAIXA TENSÃO P2P1 TRANSFORMADOR DE CORRENTE DE MÉDIA TENSÃO TRANSFORMADOR DE CORRENTE DE BAIXA TENSÃO QM DISJUNTOR DE MÉDIA TENSÃO COM BOBINA DE ABERTURA DISJUNTOR CAIXA ABERTA DISJUNTOR CAIXA MOLDADA MINIDISJUNTOR DISJUNTOR MOTOR BARRAMENTO DE ALUMÍNIO MULTIMEDIDOR DE GRANDEZAS MULTIMEDIDOR PAINEIS DE CARGAS CARGAS TERMINAIS xxx kVA xxx kW xxx kVAr PROTOCOLO DE COMUNICAÇÃO TRANSFORMADOR TRIFÁSICO A SECO BANCO DE CAPACITORES DISPOSITIVO DE PROTEÇÃO CONTRA SURTOS (DPS) 1314 K1 CONTATOR TRIFÁSICO

1x(4x120mm²)+1x(1x95mm²) Ir=260A CABO DE COBRE 35mm² PARA EQUIPOTENCIALIZAÇÃO PE QGBT-001 - NOTA 3 E 4 NOTA 2 E 4 NOTA 5 MULTIMEDIDOR DE GRANDEZAS 132.94 kVA 115.75 kW 64.97 kVAr 34.09 kVA 28.13 kW 18.89 kVAr 468.19 kVA 406.24 kW 232.25 kVAr 67.84 kVA 59.87 kW 31.59 kVAr 170.45 kVA 142.29 kW 91.34 kVAr 11 VAI PARA VAI PARA VAI PARA VAI PARA VAI PARA VAI PARA PÁG. 02 PÁG. 02 PÁG. 03 PÁG. 04 PÁG. 04 PÁG. 05 115.23 kVA 100.54 kW 55.55 kVAr Q14 In=???? 3PNOTA 7

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

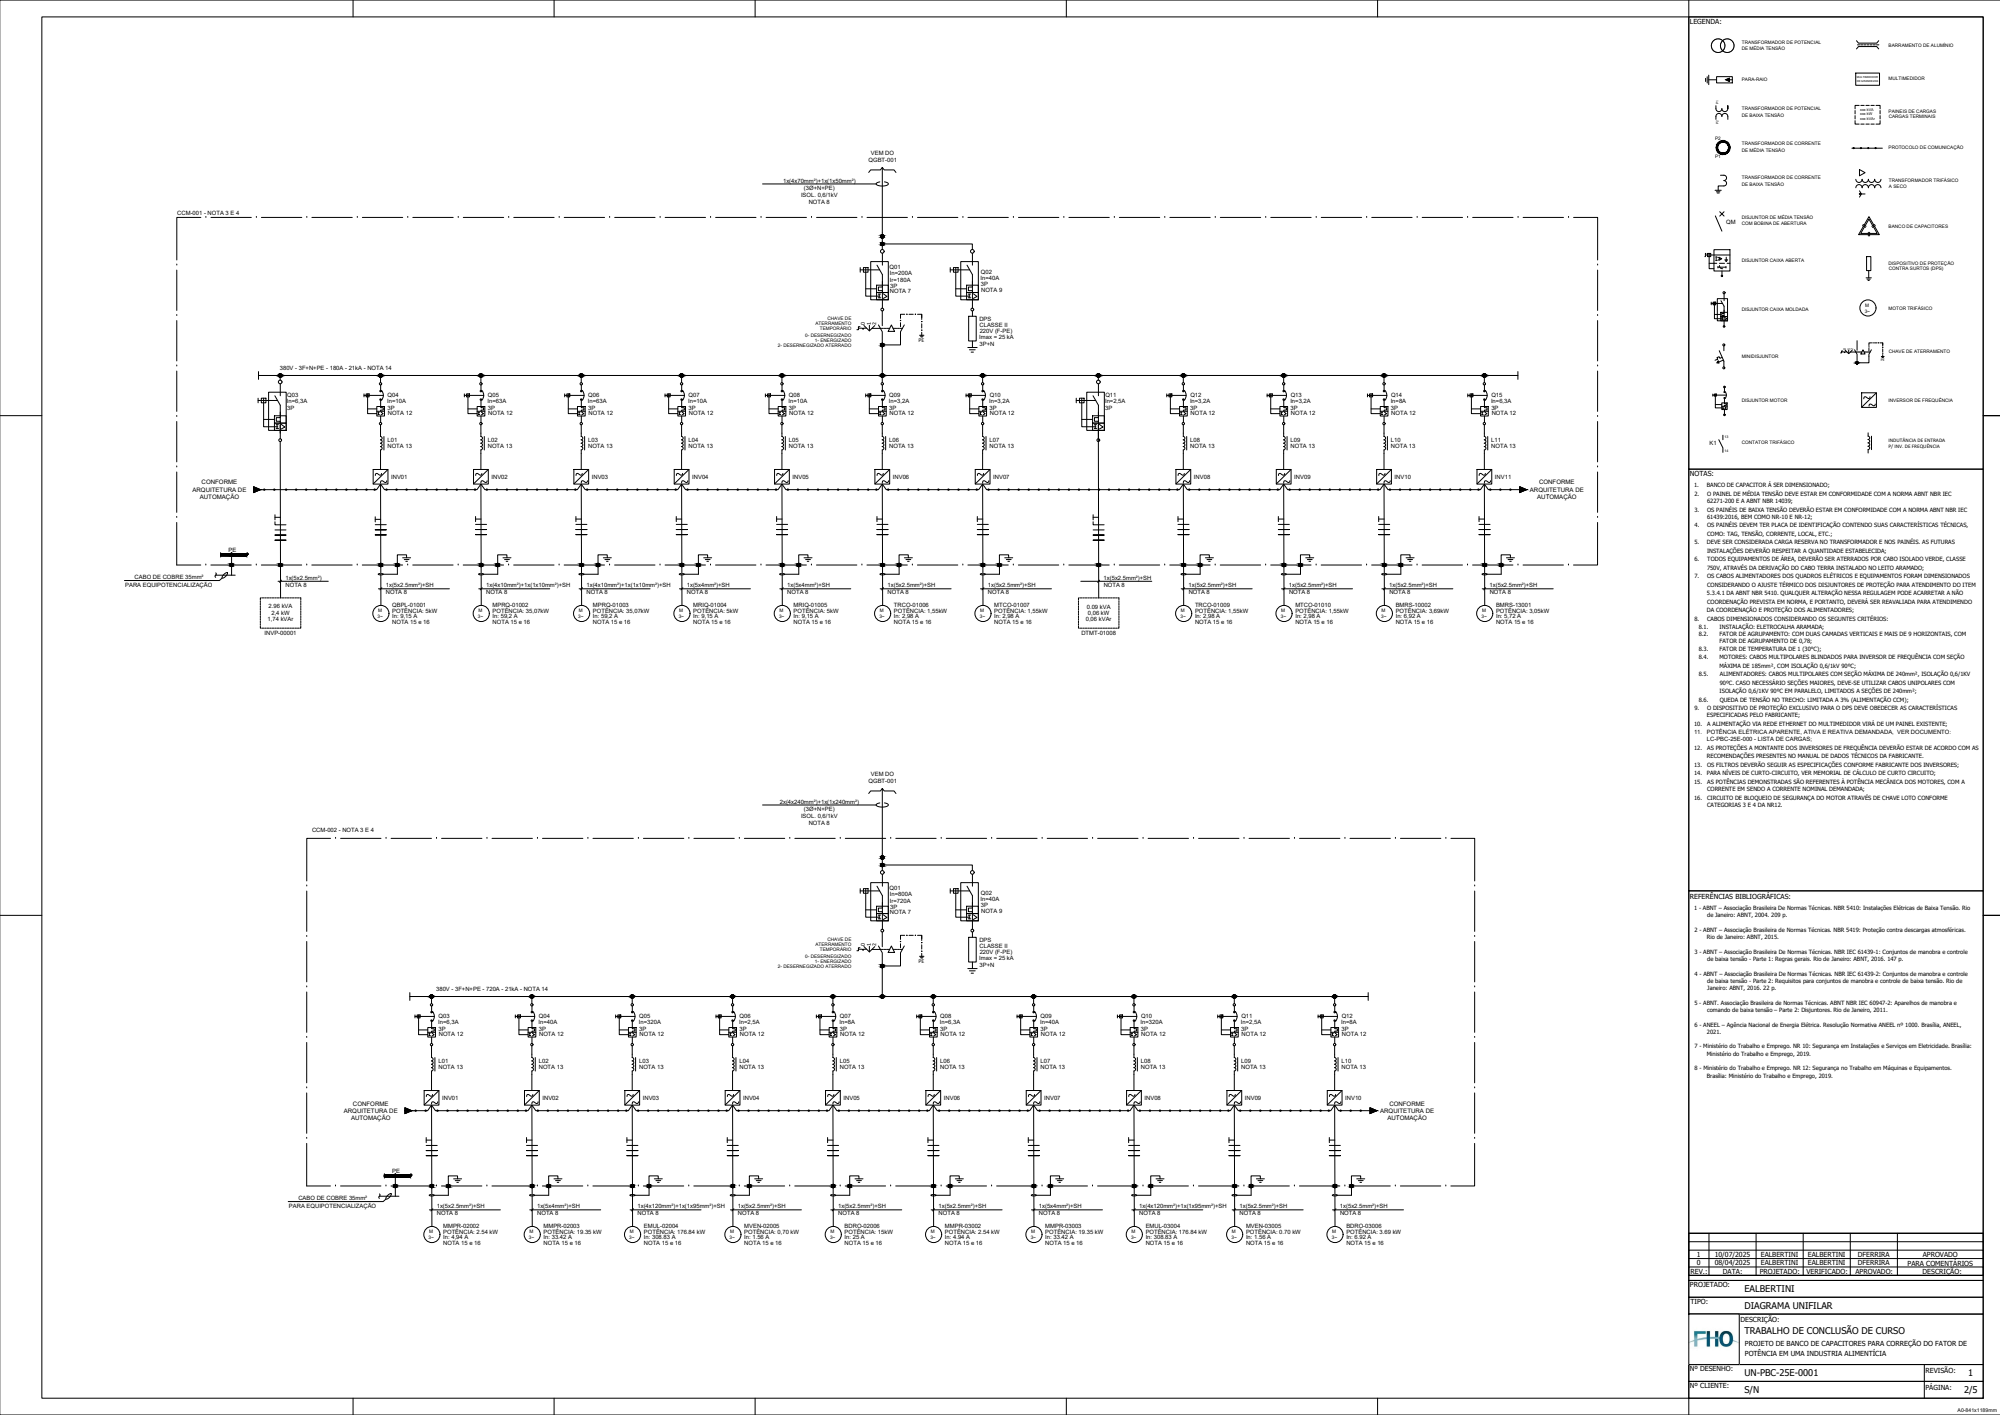
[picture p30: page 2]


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

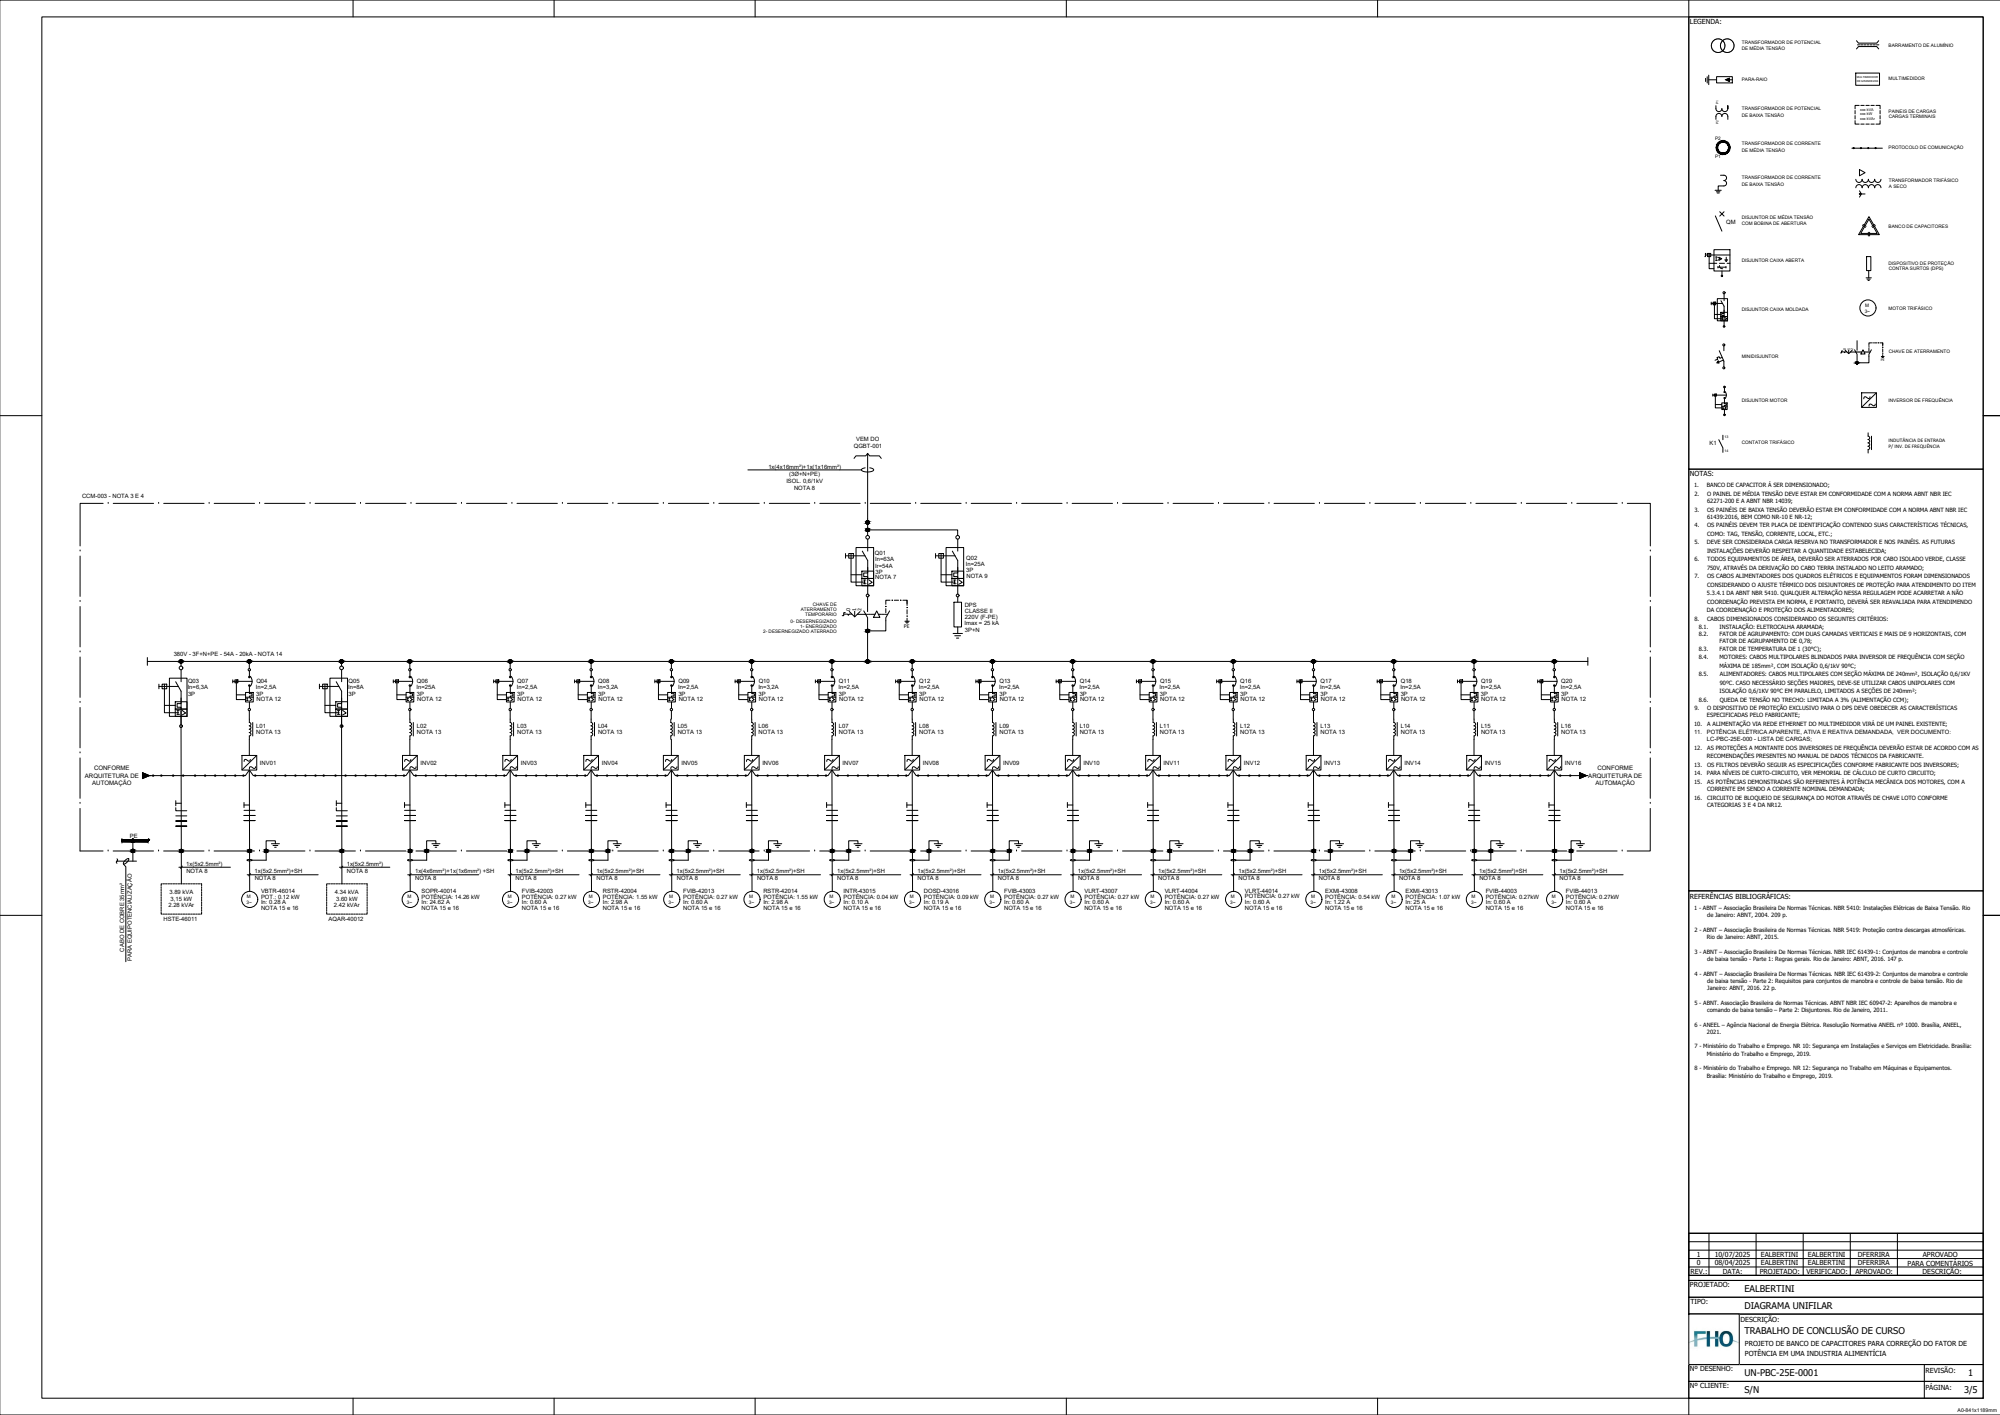
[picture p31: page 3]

PARA EQUIPOTENCIALIZAÇÃO PE CCM-003 - NOTA 3 E 4 NOTA 13 1x(5x2.5mm²) NOTA 8 Q04 In=2,5A 3PNOTA 12 L02INV02 NOTA 13 1x(5x2.5mm²)+SH NOTA 8 VBTR-46014 POT.: 0.12 kW In: 0.28 A NOTA 15 e 16 M3~ Q05 In=8A 3P L03INV03 NOTA 13 1x(5x2.5mm²) NOTA 8 Q06 In=25A 3PNOTA 12 L04INV04 NOTA 13 1x(4x6mm²)+1x(1x6mm²) +SH NOTA 8 SOPR-40014 POTÊNCIA: 14.26 kW In: 24.62 A NOTA 15 e 16 M3~ Q07 In=2,5A 3PNOTA 12 L05INV05 NOTA 13 1x(5x2.5mm²)+SH NOTA 8 FVIB-42003 POTÊNCIA: 0.27 kW In: 0.60 A NOTA 15 e 16 M3~ Q08 In=3,2A 3PNOTA 12 L06INV06 NOTA 13 1x(5x2.5mm²)+SH NOTA 8 RSTR-42004 POTÊNCIA: 1.55 kW In: 2.98 A NOTA 15 e 16 M3~ Q09 In=2,5A 3PNOTA 12 L07INV07 NOTA 13 1x(5x2.5mm²)+SH NOTA 8 FVIB-42013 POTÊNCIA: 0.27 kW In: 0.60 A NOTA 15 e 16 M3~ Q10 In=3,2A 3PNOTA 12 L08INV08 NOTA 13 1x(5x2.5mm²)+SH NOTA 8 RSTR-42014 POTÊNCIA: 1.55 kW In: 2.98 A NOTA 15 e 16 M3~ Q11 In=2,5A 3PNOTA 12 L09INV09 NOTA 13 1x(5x2.5mm²)+SH NOTA 8 INTR-43015 POTÊNCIA: 0.04 kW In: 0.10 A NOTA 15 e 16 M3~ Q12 In=2,5A 3PNOTA 12 L10INV10 NOTA 13 1x(5x2.5mm²)+SH NOTA 8 DOSD-43016 POTÊNCIA: 0.09 kW In: 0.19 A NOTA 15 e 16 M3~ Q13 In=2,5A 3PNOTA 12 L11INV11 NOTA 13 1x(5x2.5mm²)+SH NOTA 8 FVIB-43003 POTÊNCIA: 0.27 kW In: 0.60 A NOTA 15 e 16 M3~ Q14 In=2,5A 3PNOTA 12 L12INV12 NOTA 13 1x(5x2.5mm²)+SH NOTA 8 VLRT-43007 POTÊNCIA: 0.27 kW In: 0.60 A NOTA 15 e 16 M3~ Q15 In=2,5A 3PNOTA 12 L13INV13 NOTA 13 1x(5x2.5mm²)+SH NOTA 8 VLRT-44004 POTÊNCIA: 0.27 kW In: 0.60 A NOTA 15 e 16 M3~ CONFORME ARQUITETURA DE AUTOMAÇÃO Q16 In=2,5A 3PNOTA 12 L14INV14 NOTA 13 1x(5x2.5mm²)+SH NOTA 8 VLRT-44014 NOTA 15 e 16 M3~ Q17 In=2,5A 3PNOTA 12 L15INV15 NOTA 13 1x(5x2.5mm²)+SH NOTA 8 EXMI-43008 POTÊNCIA: 0.54 kW In: 1.22 A NOTA 15 e 16 M3~ Q18 In=2,5A 3PNOTA 12 L16INV16 NOTA 13 1x(5x2.5mm²)+SH NOTA 8 EXMI-43013 POTÊNCIA: 1.07 kW In: 25 A NOTA 15 e 16 M3~ Q19 In=2,5A 3PNOTA 12 1x(5x2.5mm²)+SH NOTA 8 FVIB-44003 POTÊNCIA: 0.27kW In: 0.60 A NOTA 15 e 16 M3~ Q20 In=2,5A 3PNOTA 12 1x(5x2.5mm²)+SH NOTA 8 FVIB-44013 POTÊNCIA: 0.27kW In: 0.60 A NOTA 15 e 16 M3~ - 380V - 3F+N+PE - 54A - 20kA - NOTA 14 3.89 kVA 3,15 kW 2.28 kVAr HSTE-46011 4.34 kVA 3.60 kW 2.42 kVAr AQAR-40012 CONFORME ARQUITETURA DE AUTOMAÇÃO POTÊNCIA: 0.27 kW In: 0.60 A VEM DO QGBT-001 (3Ø+N+PE) ISOL. 0,6/1kV NOTA 8 1x(4x16mm²)+1x(1x16mm²) A0-841x1189mm PÁGINA: REVISÃO: TIPO: PROJETADO: Nº DESENHO: REFERÊNCIAS BIBLIOGRÁFICAS: NOTAS: LEGENDA: REV.: DATA: PROJETADO: VERIFICADO: APROVADO: 0 08/04/2025 EALBERTINI EALBERTINI DFERRIRA PARA COMENTÁRIOS Nº CLIENTE: EALBERTINI DIAGRAMA UNIFILAR TRABALHO DE CONCLUSÃO DE CURSO S/N 13/5 UN-PBC-25E-0001 PROJETO DE BANCO DE CAPACITORES PARA CORREÇÃO DO FATOR DE POTÊNCIA EM UMA INDUSTRIA ALIMENTÍCIA DESCRIÇÃO: DESCRIÇÃO: 1 10/07/2025 EALBERTINI EALBERTINI DFERRIRA APROVADO TRANSFORMADOR DE POTENCIAL DE MÉDIA TENSÃO PARA-RAIO

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

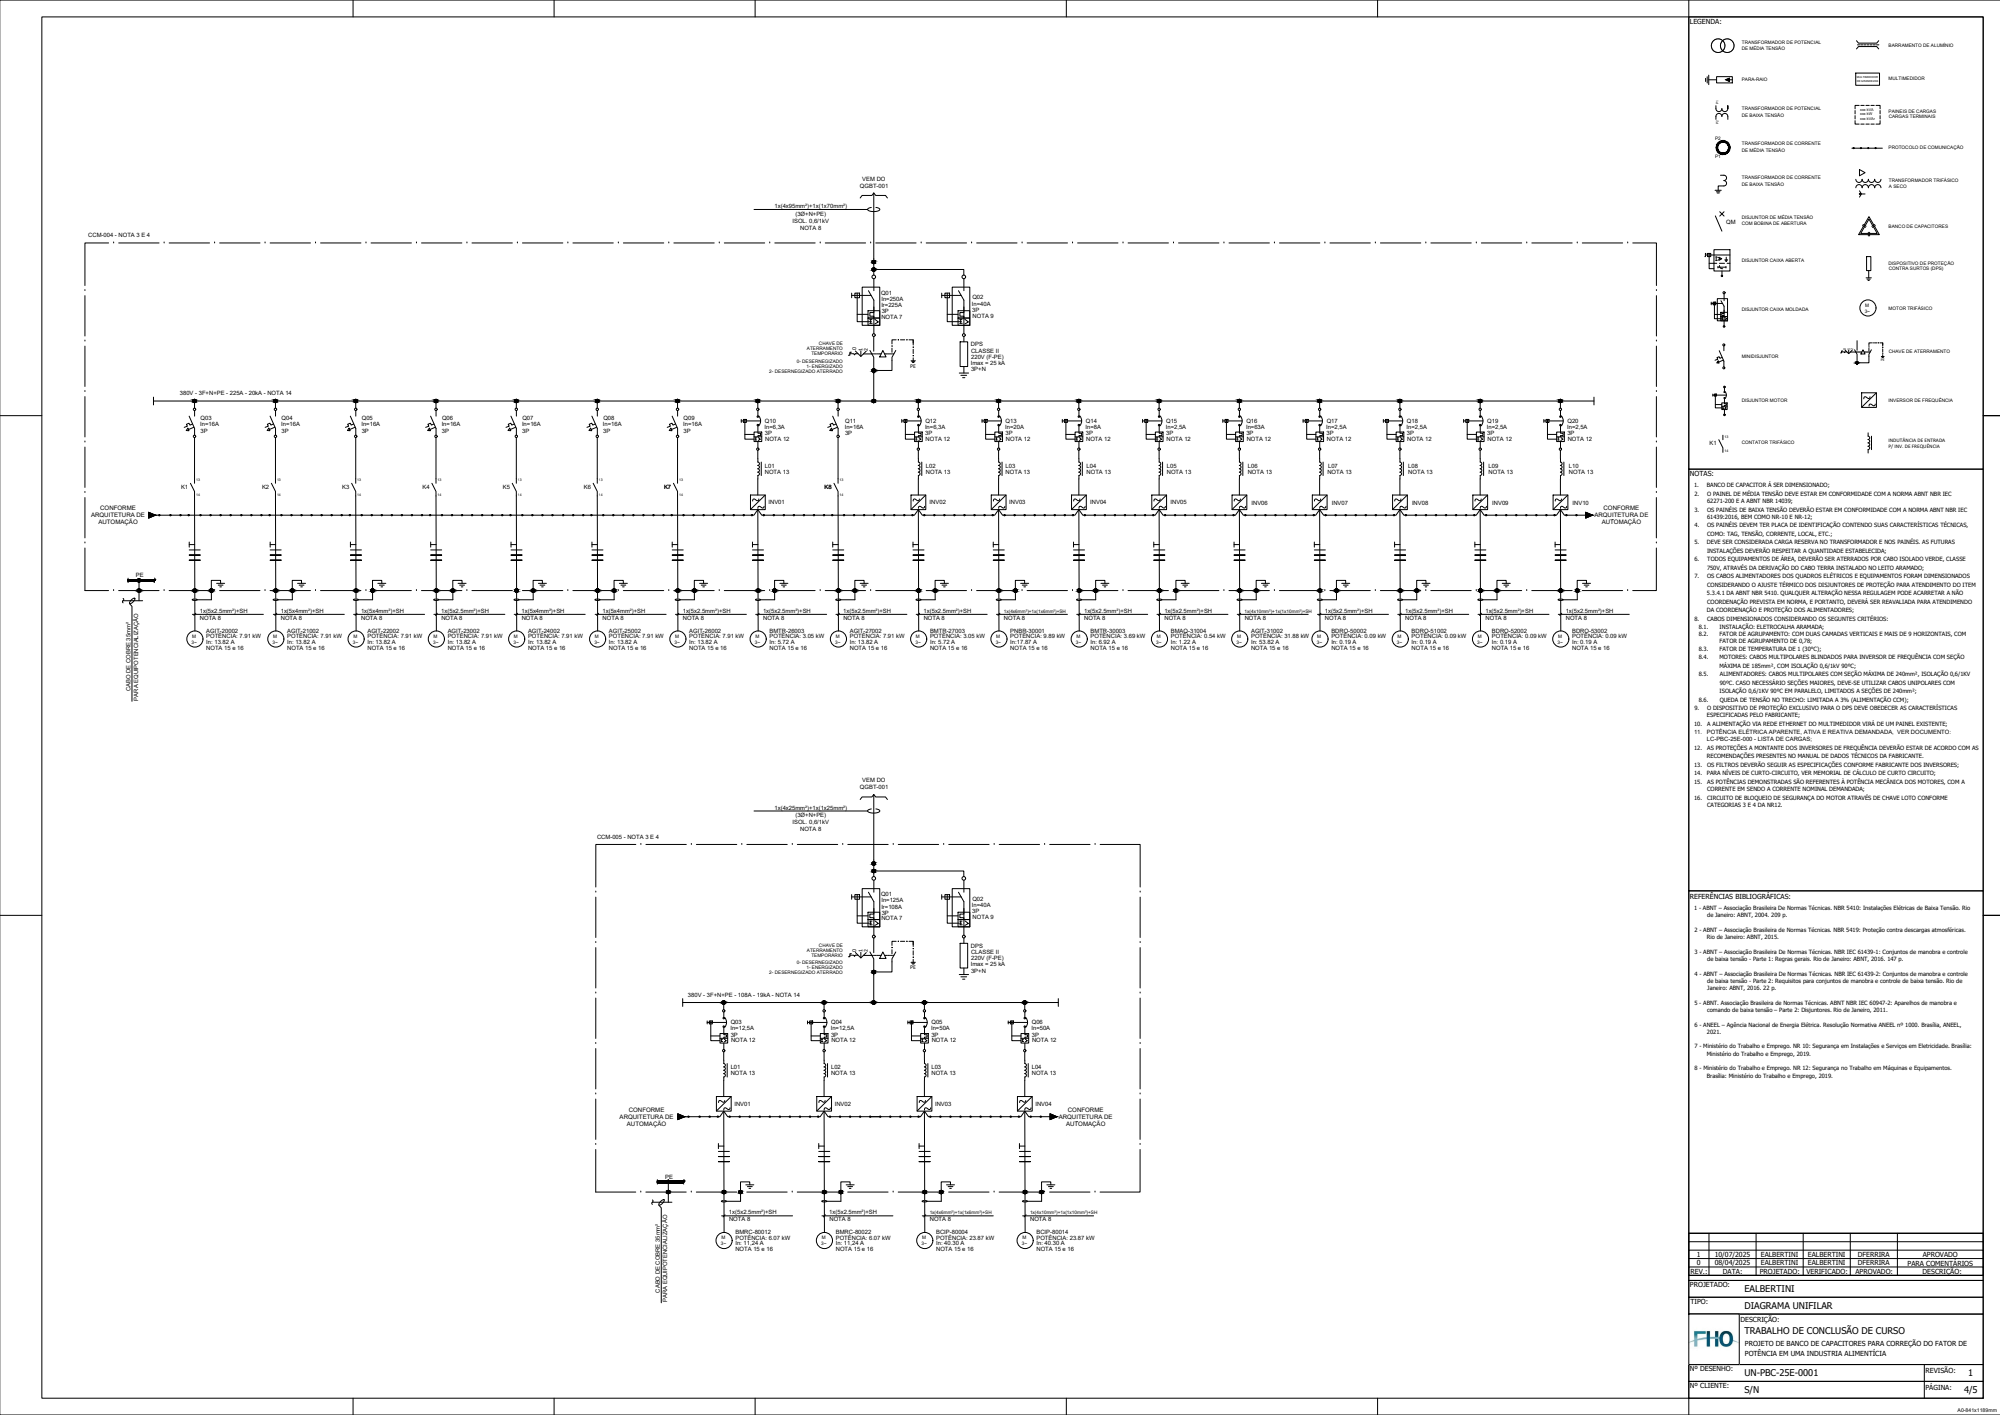
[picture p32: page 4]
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

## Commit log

2025-11-05 Create Cálculo de climatização
2025-11-05 Rename PROJETO DE BANCO DE CAPACITORES - 225kVAr_20250828_020039_documentation.pdf to Cálculo de climatização
2025-11-07 Rename PROJETO DE BANCO DE CAPACITORES - 225kVAr_20250828_020039_documentation.pdf to PROJETO DE BANCO DE CAPACITORES - 225kVAr_20250828_020039_documentation.pdf
2025-11-07 Rename Cálculo de C.C_rev.0.pdf to Cálculo de C.C_rev.0.pdf
2025-11-07 Rename Curva de disparo disjuntor geral.pdf to Curva de disparo disjuntor geral.pdf
